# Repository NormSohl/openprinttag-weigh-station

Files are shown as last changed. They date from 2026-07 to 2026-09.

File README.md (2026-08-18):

# Filliment Scale

<p align="center">
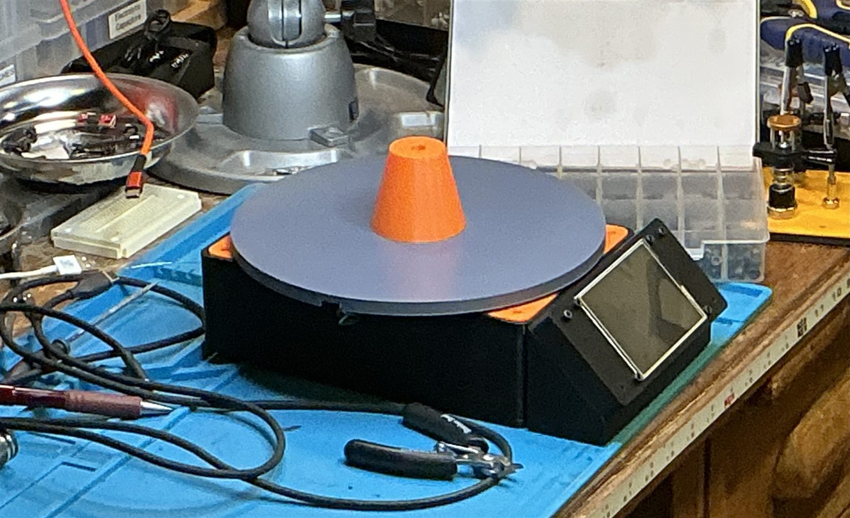
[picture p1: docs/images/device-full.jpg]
The assembled weigh station on the workbench: black enclosure, 3.5-inch display, and the round weighing platform with its orange centering spigot
  
  <br>
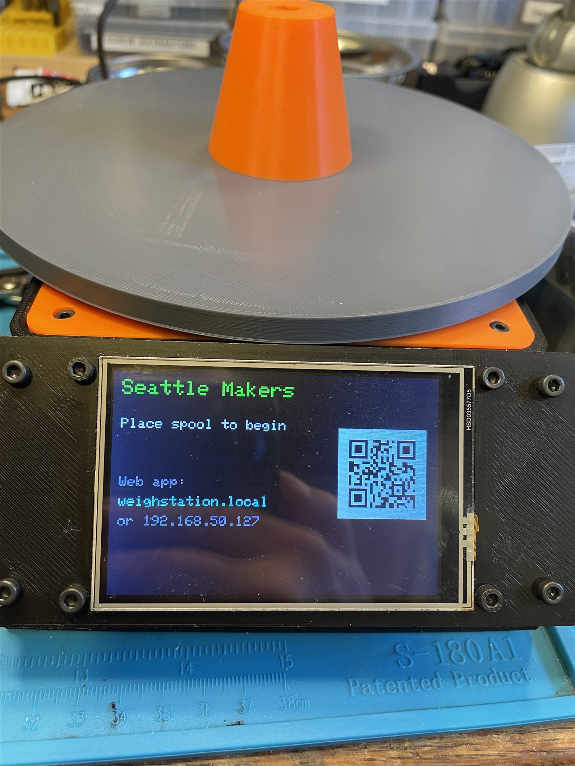
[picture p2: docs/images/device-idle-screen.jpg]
The station's idle screen: Seattle Makers, Place spool to begin, the web app address, and a QR code
  
</p>

The Seattle Makers filament weigh station: a **self-contained** NFC +
load-cell scale for the 3D-printing lab, and everything needed to build
one — the 3D-printed enclosure, wiring, and firmware.

Place a spool on the scale: it reads the [OpenPrintTag](https://specs.openprinttag.org)
(OPT) NFC tag, weighs the spool, and records the remaining filament
**locally on the device** — no external server. A built-in web app handles
inventory, onboarding new spools, reordering, backup/restore, and scale
calibration; usage history is kept as an append-only event log in
on-device flash.

OpenPrintTag is an open spool-identification standard created and
promoted by [Prusa](https://www.prusa3d.com/) — the project's namesake.
Spec: [specs.openprinttag.org](https://specs.openprinttag.org) · reference
implementation: [OpenPrintTag/openprinttag-specification](https://github.com/OpenPrintTag/openprinttag-specification)
on GitHub. This station's own tags are genuine OpenPrintTag MK1 stickers sourced
directly from Prusa (see the [BOM](hardware/bill-of-materials.md)), and it
reads any other vendor's OPT-compliant tag (Prusament, eSun, etc.) the
same way a Prusa printer would.

- **Hardware:** SparkFun Thing Plus ESP32-S3, PN5180 NFC (ISO15693), NAU7802
  load-cell ADC, 3.5" ILI9488 SPI TFT (480×320), passive piezo buzzer, onboard
  WS2812 NeoPixel.
- **Firmware:** PlatformIO + Arduino, FreeRTOS tasks (NFC / scale / display /
  sync + web app). Local storage on LittleFS + NVS.

## Get it running

Building the hardware? Start at [`docs/build-guide.md`](docs/build-guide.md).
Already have a built station and just need firmware? Download the latest
[**pre-built release**](https://github.com/NormSohl/openprinttag-weigh-station/releases/latest)
and flash it with `esptool` — no PlatformIO or source checkout required; see
the build guide's [flashing section](docs/build-guide.md#6-flashing-the-firmware)
for the exact command. Building firmware from source is documented in
[`DEVELOPMENT.md`](DEVELOPMENT.md) for anyone modifying it.

## Docs

- [`docs/build-guide.md`](docs/build-guide.md) — build one from scratch: parts, printing, wiring, flashing, first bring-up
- [`DEVELOPMENT.md`](DEVELOPMENT.md) — set up, build, and flash
- [`docs/user-manual.md`](docs/user-manual.md) — operation (members + admins)
- [`hardware/netlist.md`](hardware/netlist.md) — wiring diagram + pinout
- [`docs/design/sd-local-ecosystem.md`](docs/design/sd-local-ecosystem.md) — the
  local-storage architecture

> **History:** this project originally synced to Spoolman (and kept history in
> Prometheus). It is now standalone — Spoolman and Prometheus have been removed
> and replaced by on-device storage and the built-in web app.

## License

[GPL-3.0-or-later](LICENSE). Commercial use, including selling assembled
units or a modified firmware, is fine — but any distributed derivative
(firmware, the enclosure `.scad` files, or this repo's own docs) must stay
under the same license and come with source. Firmware, tools, and hardware
source files each carry an `SPDX-License-Identifier: GPL-3.0-or-later`
header; that's the convention to follow in any new file.

Third-party libraries pulled in via `platformio.ini` and the vendored copy
of `lib/PN5180-Library` (LGPL-2.1) keep their own upstream licenses —
check the library's own `LICENSE` before assuming GPL terms apply to it.

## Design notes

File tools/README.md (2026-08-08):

# tools/ — bench aids that need no board

Two kinds of thing here: UI previews (Python, below) and `qr/` — C harnesses
that build and run the real QR encoder natively under AddressSanitizer, to
check the capacity table `drawQr()` depends on. Unlike the previews, those
are actual tests with a pass/fail exit code. See `qr/README.md`.

## UI preview generators

Standalone Python scripts that render the device's UI **without flashing the
board**, for reviewing look/layout/wording on a PC. Pure `python3` stdlib, no
dependencies.

| Script | Renders | Source of truth |
|---|---|---|
| `preview_webapp.py` | The built-in web app (dashboard, spools, spool history + sparkline, onboard, reorder, config, calibrate, backup) | `src/web_app.cpp` |
| `preview_lcd.py` | The 3.5" ILI9488 TFT for every device state (480×320) | `src/display_task.cpp` |

```bash
python3 tools/preview_webapp.py   # -> webapp-preview.html
python3 tools/preview_lcd.py      # -> lcd-preview.html
```
Open the generated HTML in any browser.

> ⚠️ **These duplicate layout/markup from the firmware with sample data** — they
> are *not* built or tested by CI, and they will drift if the web/display code
> changes. Treat them as a convenience preview, and re-run (and tweak) them after
> editing `web_app.cpp` / `display_task.cpp`. The firmware is always authoritative.

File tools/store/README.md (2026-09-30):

# tools/store — `store.cpp`, compiled and run on the host

`./run.sh` builds and runs everything here. It needs ArduinoJson:

```
git clone --depth 1 https://github.com/bblanchon/ArduinoJson ../../.deps/ArduinoJson
./run.sh
```

## Why this exists

The PlatformIO **registry** is unreachable from the Claude Code sandbox, so
firmware changes made there get no compiler at all — only a real `pio run`
proves them. But the registry is the only thing blocked; GitHub is reachable,
and `store.cpp`'s dependencies are small enough to shim. `shim/` supplies just
enough `Arduino.h` / `LittleFS.h` / `Preferences.h` / FreeRTOS for the real
`src/store.cpp` to compile and **run**, with LittleFS over a scratch directory
and NVS over a flat file — so the counters diverge across a simulated reboot
the way the real partitions do, which is the exact condition
`reconcileIdCounter_()` exists to repair.

That buys two things the sandbox otherwise cannot have:

1. **`store.cpp` is compile-verified.** It is the largest and most-changed file
   in the project.
2. **The compaction fold is verifiable without hardware.** `run.sh` runs
   `SEED 20 200` → `DUMP usage` → `COMPACT` → `DUMP usage` and diffs the two,
   which is the one check whose regression cannot be recovered afterwards: once
   raw events are folded away, the `Usage` rows are the only evidence left. The
   figures match the 2026-08-08 hardware run exactly — 4 buckets, 4477.5 g and
   995 weighs each, 17910.0 g total.

`--products` covers what no serial command reaches: adoption converging on one
product rather than one per spool, a disagreeing tag being reported without
updating anything, an edit propagating to its spools, and products surviving a
fold. It found a real bug on its first run — `productDiffers_()` was not
comparing the tare. That comparison was **deliberately removed** on 2026-09-30:
tare now belongs to the spool, not the product (the same filament sometimes
arrives on a different spool body), so a tag whose tare differs from its
product's is that spool's tare, not a conflict. The suite now asserts both
directions — a different tare is *not* reported and does not fork a product,
and a product edit leaves each spool's own tare alone (a spool with none takes
the product's default).

`--audit` covers the physical-inventory audit state machine — phase
transitions, Found/Close semantics, and specifically the two real bugs found on
hardware 2026-08-15 that no automated test had caught until this one existed:
the four `Audit*` marker events (global, no `uuid`) silently vanishing across a
compaction fold that straddled an in-progress audit, and a retired spool never
clearing `retired` on a genuine subsequent reweigh. Both are regression-tested
here now (SEED past `STORE_LOG_KEEP_EVENTS`, `COMPACT`, assert the phase
survived; reweigh a retired spool, assert `retired` cleared).

`--cost` covers `applyInto_()`'s `delta * rate` — the conversion from grams
consumed to dollars, and the one calculation the whole cost feature exists for.
Nothing else reached it: `SEED` never sets a price, so every `dollars` figure
in the other suites is `$0.00` and a regression would have been invisible until
someone noticed the money was wrong months later. Three spools, one period:
priced up front (500 g of a $30.00/kg spool → $15.00), never priced (300 g →
$0.00, grams still counted), and priced only partway through (200 g consumed
but only the later 100 g priced → $5.00, because a price recorded later must
never backdate earlier consumption). Then it seeds past
`STORE_LOG_KEEP_EVENTS`, compacts, and re-asserts all three — Usage rows are
the only evidence left once raw events fold away.

**It seeds before compacting deliberately.** The first cut ran `COMPACT` on a
twelve-line log, where it is a no-op, so the "survives the fold" assertions
re-checked un-folded data and passed for the wrong reason. The test now
captures the line count either side of the fold and fails if nothing was
actually folded. Its detection power was confirmed by mutation: doubling the
rate in `store.cpp` fails both priced buckets, before and after compaction,
and correctly leaves the unpriced one passing.

`--popularity` covers `storeMaterialPopularity()` — the Stock List's
stockout-corrected `grams / available_days` metric — against a hand-built
timeline (in stock, consumed to empty, restocked, partially consumed again)
where every expected number is known in advance. Writing it surfaced a real,
previously undocumented gap: **popularity had no fold-survival mechanism.**
Unlike the consumption rollup (folded into permanent `Usage` rows) and unlike
Products/Audits (re-emitted from live state at compaction time),
`storeMaterialPopularity()` only ever replays raw log lines, and a compaction
`Checkpoint` carries a state snapshot, not grams or crossing history. On a
station busy enough that `STORE_LOG_KEEP_EVENTS` (2000 events) covers less
real time than the popularity window (90 days by default), a compaction could
silently fold away consumption still legitimately inside the window —
reproduced on this bench as `grams` dropping 1000 → 0 and `available_days`
shifting 15 → 5 for identical underlying history, before vs. after a forced
compaction. That was the opposite of the feature's stated purpose ("a
stockout must never make a popular material look artificially unpopular").

**Fixed** by giving `storeCompact()` a retention floor: it now refuses to
fold any log line timestamped within `STOCK_POPULARITY_WINDOW_DAYS` of now
(`config.h`), no matter how far past `STORE_LOG_KEEP_EVENTS` the log has
grown — found by a single pre-pass over the log (piggybacked on the existing
line-count pass) that locates the earliest in-window line and caps `skip` at
that index, since compaction only ever discards a *prefix* of the log.
`STORE_LOG_COMPACT_BYTES`'s byte trigger is what still bounds how long that
can go on for. `STOCK_POPULARITY_WINDOW_DAYS` moved out of `web_app.cpp` and
into `config.h` specifically so the compaction floor and the query window
share one definition and cannot drift apart. `--popularity` now asserts (not
just prints) both directions: a compaction that would touch in-window history
must be refused entirely and leave the numbers byte-for-byte unchanged, and
material genuinely outside the window must still compact normally without
disturbing an unrelated in-window material's numbers.

**This does not replace `pio run`.** Everything outside `store.cpp` — the tasks,
the web app, the display — still has no compiler here.

## The matcher slice

`storeFindProduct()` decides whether the tag on the scale is *another spool of
something we already stock* or *a new product*. Both wrong answers are silent:

- **Missed match** → a second product is created, and the inventory lists the
  same filament twice. The reorder threshold then guards half a shelf each.
- **Over-match** → two different filaments merge into one row. A 1 kg and a
  5 kg of the same product carry the identical `material_name`, so this is the
  easy mistake to make, and it defeats the decision that a different size is a
  different product.

Neither shows up as an error, on the bench or in service — which is why this is
tested off the board.

`extract_match.py` slices `ProductRecord`,
`normEq_`, `nomEq_` and `findProduct_` **verbatim** out of `src/store.h` and
`src/store.cpp` into a generated header. The test therefore exercises the
shipping bytes, and it cannot drift the way a transcribed copy would. If a
refactor moves the markers the extractor brackets on, it exits with an error
rather than testing something stale.

This also makes those functions compile-verified, which is otherwise not
available for anything in `src/`.

## Run

```
python3 extract_match.py
g++ -std=c++17 -O1 -g -fsanitize=address,undefined -o match_test match_test.cpp
LD_PRELOAD=$(gcc -print-file-name=libasan.so) ./match_test
```

`match_extract.h` and `match_test` are build products; they are not committed.

## What it asserts

Each rung of the ladder in isolation, and the cases where the rungs disagree:

| check | why it is here |
|---|---|
| `eSun` matches `ESUN`, `PLA Summer` matches `PLA  Summer` | vendors and product names are typed by hand |
| `PLA` does **not** match `PLA+` | whitespace is skipped, punctuation is not — these are different filaments |
| nominal weight 0 does not block a match | a tag carrying no weight offers nothing to distinguish on |
| 1 kg and 5 kg stay apart under rules 3 and 4 | the whole reason nominal weight is in the key |
| `package_uuid` beats `gtin` beats `material_uuid` beats names | the ladder order is the design's, not an accident |
| an unknown `package_uuid` still falls through to the name rule | a vendor UUID we have not seen must not veto a good name match |
| an empty probe matches nothing | must not silently adopt row 0 |

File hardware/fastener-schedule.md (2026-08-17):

# Fastener Schedule — opt-weigh-station

Derived directly from `weighstation.scad` and `porch-tft-faceplate.scad`.
All screws are metric ISO 4762
socket head cap screws (SHCS), stainless A2. All heat-set inserts are
Ruthex press-fit, installed from above. Washers (DIN 125-A, stainless)
go under every screw head bearing on plastic.

## Heat-Set Inserts

| Size | Location | Qty |
|---|---|-----|
| M3 (Ruthex RX-M3x5.7) | Tray mount bosses | 4 |
| M3 (Ruthex RX-M3x5.7) | Deck corner columns | 4 |
| M3 (Ruthex RX-M3x5.7) | Overload stop post | 1 |
| M3 (Ruthex RX-M3x5.7) | USB-C breakout floor bosses | 2 |
| M3 (Ruthex RX-M3x5.7) | NAU7802 standoffs | 2 |
| M3 (Ruthex RX-M3x5.7) | Porch display faceplate corner bosses | 4 |
| M4 (Ruthex RX-M4x6.0) | Platform center (underside) | 1 |
| M5 (Ruthex RX-M5x7.0) | Load cell fixed-end boss | 1 |

**Total: 19 inserts** — 17× M3, 1× M4, 1× M5

## Screws

| Size | Location | Qty |
|---|---|-----|
| M3×10 SHCS | Tray board → tray bosses | 4 |
| M3×10 SHCS | USB-C board → floor bosses | 2 |
| M3×10 SHCS | NAU7802 board → tray standoffs | 2 |
| M2.5×8 SHCS | Display board → faceplate front (+ nut) | 4 |
| M3×12 SHCS | Deck corners → column inserts | 4 |
| M3×10 SHCS | Faceplate corners → porch heat-set bosses | 4 |
| M3×50 SHCS | Overload stop adjustment screw | 1 |
| M4×25 SHCS | Spigot → platform center | 1 |
| M5×30 SHCS | Load cell fixed end → base boss | 1 |

**Total: 23 screws** — 4× M2.5×8, 12× M3×10, 4× M3×12, 1× M3×50, 1× M4×25, 1× M5×30

## Nuts

| Size | Location | Qty |
|---|---|-----|
| M2.5 nyloc (or hex) | Display board through-bolts — behind the board, faceplate's open back | 4 |

**Total: 4 nuts** — the faceplate's own corner screws thread straight into
heat-set bosses in the porch wall and need no nut; only the board-to-plate
screws do, reached through the plate's open back before final mounting.

## Washers

| Size | Qty | Notes |
|---|-----|---|
| M2.5 flat (DIN 125-A) | 4 | Under the display-board nuts (spread load on the PCB) |
| M3 flat (DIN 125-A) | 17 | One per M3 screw (incl. 4 faceplate) |
| M4 flat (DIN 125-A) | 1 | Spigot bolt |
| M5 flat (DIN 125-A) | 1 | Load cell fixed-end bolt |

## Notes

- **Overload stop screw (M3×50):** travels from below the base underside
  (~45mm) before reaching the insert mouth — a shorter screw will not
  engage the insert at all. `plat_gap` was raised 2→5 (platform/adapter
  clearance), so `lc_boss_h` grew 46.3→49.3mm and the post is ~3mm taller;
  M3×50 still engages (~5mm) but confirm on the printed part — step up to
  M3×55 if engagement is marginal.
- **Load cell screw (M5×30):** stack is platform (8mm) + load cell bar
  (12.7mm) = 20.7mm of clearance before the insert. M5×30 gives ~4–9mm of
  thread engagement depending on insert seating depth.
- **NAU7802 and USB-C breakout boards:** hole sizes have not been measured
  against the actual boards. If either board uses M2 holes instead of M3,
  swap the corresponding screw line for M2 self-tap and drop the matching
  insert (the standoff/boss is sized generously enough to work either way).
- All M3 boss/standoff fastenings (tray, deck, USB, NAU, faceplate) use the
  same Ø8 boss with a 1.7mm wall around the M3 insert — adequate in PETG.
- **Display board through-bolts (M2.5×8 + nut):** cap head sits proud on
  the faceplate's front bezel; the shaft passes through the thin front
  panel and the board's corner hole (92×50mm pattern) into an M2.5 nut
  behind, cinching the board against the panel back. Nuts + washers go on
  from the faceplate's open back before it's mounted to the porch. M2.5×8
  gives ~2–3mm past the nut; drop to M2.5×6 if the nut sits proud. No
  counterbore — the cap is intentionally proud (front service).
- **Faceplate corner screws (M3×10, no nut):** the faceplate (3mm) sits
  directly over an opening cut into the porch's own front face and picks
  up 4 heat-set-insert bosses that project sideways from the porch's real
  side wall — no wiring-passage reach-through, no nut. Head sits proud
  (no counterbore on a 3mm plate). This replaced the older adapter's
  M3×25 + nyloc-through-the-porch-cavity pattern; see
  `printed-parts-issues.md` issue 5 for why.

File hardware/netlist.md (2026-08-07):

# Wiring Netlist

Source → destination for the controller and every peripheral. Matches the
firmware pin map (`src/config.h`) and the display datasheet-of-record
(`docs/datasheets/display-hosyond-ili9488.md`).

**MCU:** SparkFun Thing Plus ESP32-S3 (DEV-21230).

> "LED" on the display is the **panel's built-in backlight** (main header
> pin 8, silk-labeled `LED`), not a separate indicator. Tie to 3.3 V for
> always-on. The panel shows nothing without it.

---

## Diagram

Wiring block diagram

Every device wires back to the controller — the PN5180 and display don't connect
to each other; each shared net runs from the controller and forks at a splice.
The onboard NeoPixel (GPIO 46) and BOOT button (GPIO 0) need no wiring.

---

## Assembly schedule

Two kinds of connection: **direct** single wires, and **shared nets** that reach
more than one device — each of those is joined once at a **soldered splice**
(pigtail star), with a single clean leg to every endpoint.

### Direct wires — one per row (MCU pin → device)

| # | From | To |
|---|---|---|
| 1 | GPIO 5  | PN5180 : NSS (CS) |
| 2 | GPIO 6  | PN5180 : BUSY *(active-high)* |
| 3 | GPIO 7  | PN5180 : RST *(active-low)* |
| 4 | GPIO 15 | TFT : CS |
| 5 | GPIO 16 | TFT : DC (RS) |
| 6 | GPIO 17 | TFT : RESET |
| 7 | GPIO 14 | Buzzer : + *(PWM; passive piezo, no resistor)* |
| 8 | **VUSB (5 V)** | **PN5180 : 5V** — RF transmitter rail, see Cautions |

### Shared nets — one soldered splice each

Each splice joins the legs below; a single wire then lands at every endpoint.
Bridge **VCC→LED** on the display module so the backlight needs no separate leg.

| Splice | MCU leg | Device legs |
|---|---|---|
| MOSI | GPIO 11 (`11/PICO`) | PN5180 MOSI · TFT SDI |
| SCK  | GPIO 12 (`12/SCK`)  | PN5180 SCK · TFT SCK |
| MISO | GPIO 13 (`13/POCI`) | PN5180 MISO **only** — *do NOT add TFT SDO, see Cautions* |
| 3V3  | 3V3 | PN5180 3.3V · TFT VCC |
| GND  | GND | PN5180 GND · TFT GND · Buzzer − |

### NAU7802 load-cell ADC — one Qwiic cable

Not jumpers — a single 4-conductor Qwiic cable from the Thing Plus Qwiic
connector to the NAU7802 board carries all four:

| Conductor | MCU | NAU7802 |
|---|---|---|
| SDA | GPIO 8 | SDA |
| SCL | GPIO 9 | SCL |
| +3.3 V | Qwiic 3V3 | 3.3V |
| GND | Qwiic GND | GND |

### Load cell → NAU7802 terminal block (4-wire full bridge)

| # | Load-cell wire | Function | NAU7802 terminal |
|---|---|---|---|
| L1 | 🟥 Red (红) | Excitation + | E+ |
| L2 | ⬛ Black (黑)  | Excitation − | E− |
| L3 | 🟩 Green (绿)  | Signal + | A+ |
| L4 | ⬜ White (白)  | Signal − | A− |
| L5 | 🟨 Yellow (黄) | Shield/drain | GND *(omit if absent)* |

**Totals:** 8 direct wires + 5 soldered splices (13 legs) + 1 Qwiic cable +
4–5 load-cell leads.

> **The display's microSD slot is not wired and is not used.** The ESP32-S3 has
> only two general-purpose SPI peripherals and both are taken (PN5180 on SPI2,
> TFT on SPI3 — see `platformio.ini`), so the card had no host of its own. The
> event log lives on internal flash and is backed up through the web app's
> **Backup** page. Leave the Thing Plus's own SD slot empty too.

---

## Shared-net junctions — soldered pigtails

Five nets reach more than one device — **MOSI, SCK, MISO, 3V3, GND**. Instead of
stacking wires on a pin, join each with **one soldered splice** and heat-shrink
it; a single clean leg then lands at each device (see the splice table above).

**Technique**

- Strip ~4 mm on each leg; gather and solder into one joint (a lineman's /
  Western-Union twist adds mechanical strength before you flow solder).
- **Thread the heat-shrink onto one leg first** and slide it well back from the
  end — once the wires are joined there's no open end to feed a tube over the
  splice. Solder, let it cool, slide the tube over the joint, then heat to shrink.
- **Stagger** the five splices along the loom so the shrink bumps don't stack,
  and anchor the bundle so nothing flexes right at a joint.
- Keep the splices **near the MCU** so the shared-bus stubs stay short.

**Rails with many legs.** The 3V3 (3 legs) and especially GND (4 legs) splices
carry the most wires; if a single solder joint gets bulky, put those two on a
small **perfboard bus** instead — a row of commoned pads, one wire per pad. Same
result, neater for many wires. The three SPI splices are just three wires each.

If you use a perfboard bus, mount it on a flat interior wall near the MCU:
foam tape (VHB) or adhesive-backed nylon PCB standoffs need no reprint; M2.5
standoff bosses can be added to the enclosure SCAD for a screw-down future
revision.

## Device-end connectors & retention

Independent of the splices, the leg that lands at each module can be:

- **Soldered directly** to the module's header pin — most reliable, permanent.
- **DuPont (0.1 in) plug** — keep it if you may want to swap a module. Each
  female terminal holds one wire and each header pin takes one terminal, which is
  exactly why the shared nets are spliced upstream rather than doubled onto a pin.
  Dab hot glue on DuPont housings so they can't back out under handling.

The NAU7802 stays on its latching Qwiic cable and the load cell in its screw
terminal — both already reliable, nothing to change.

---

## Onboard — no external wiring

| Function | MCU pin |
|---|---|
| WS2812 status pixel | GPIO 46 (onboard) |
| BOOT / WiFi-reset button | GPIO 0 (onboard) |

## Not wired (planned / out of scope)

| Device | Interface | Status |
|---|---|---|
| microSD (on display board) | would need a 3rd SPI host | **removed** — no SPI peripheral available (PN5180 has SPI2, TFT has SPI3). Backup is via the web app's Backup page instead |
| Resistive touch (T_CLK/T_CS/T_DIN/T_DO/T_IRQ) | SPI slave, same header | **out of scope** — intentionally unwired |
| PN5180 IRQ | — | unused (firmware polls BUSY) |

---

## Cautions

- **The PN5180 needs BOTH supplies.** Its *logic* is 3.3 V (never put 5 V on
  SPI/NSS/BUSY/RST), but the module has a **separate 5 V pin that powers the RF
  transmitter / antenna driver**. Leave 5 V off and SPI may still answer while
  the reader generates no usable field — i.e. it looks alive but sees no tags.
  Wire **VUSB → PN5180 5V** and **3V3 → PN5180 3.3V**.
  *(An earlier revision of this file said "3.3 V only — do not connect to 5 V".
  That was wrong: it conflated the logic level with the module's power pins.)*
- PN5180 + TFT share **MOSI and SCK only** — never MISO. They sit on *different*
  SPI peripherals (SPI2 and SPI3) and neither can be moved, so the firmware
  re-points those two pins on every handoff (`src/spi_bus.cpp`) — the S3 routes
  a pin's output from exactly one peripheral, and whoever attaches last silently
  takes it. Nothing to do at the wiring bench; noted here because it explains
  why this looks like a plain shared bus but is not one.
- **Leave the display's `SDO` pin unconnected.** The ILI9488's SDO does **not**
  tri-state when its CS is high (documented TFT_eSPI limitation), so wiring it
  to the shared MISO line makes the panel drive MISO permanently — every reply
  from any other device on the bus reads back as 0x00. Symptom: the display
  works fine while the PN5180 appears completely dead. We only write to the
  display, so nothing is lost; `TFT_MISO` is set to -1 in `platformio.ini`.
  *(An earlier revision of this file wired TFT SDO into the MISO splice. That
  was wrong and is what kept the NFC reader from ever answering.)*
- Load-cell orientation: force axis vertical, sealed/potted face **down** for
  positive output. Calibrate at 50–80 % of rated range via the web
  **Calibrate** page (or serial `ZERO` / `CAL <grams>`).

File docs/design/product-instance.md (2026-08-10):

# Design: products and instances

Status: **built** (2026-08-10) — pending bench verification.

| step | state |
|---|---|
| Stop destroying unmodelled tag fields | **done** — `OptMain.extra` passthrough |
| Read OPT identity keys 1–4 | **done** — `package_uuid` / `material_uuid` / `brand_uuid` / `gtin` |
| Product entity, index, event type, compaction survival, matching | **done** — `ProductRecord`, `StoreEv::Product`, `storeFindProduct()` / `storeAdoptProduct()` |
| Foreign-tag adoption resolves a product | **done** — `syncTask`, provisional |
| Web onboard/edit form resolves a product | **done** — not provisional |
| Products page + `/api/products` | **done** |
| Onboarding UI ("another spool of X" vs "a new product") | **done** |
| Product editing + propagation to its spools | **done** — `/product?id=N` |
| Reorder against products | **done** — exact match, name fallback |

**The design is built.** What is left is bench verification, and B2 in
`implementation-plan.md` (importing a catalog from 3dfilamentprofiles.com),
which is a separate piece of work.

**Products are created by the two onboarding paths and edited only on
`/product`.** That page is the one place an update is allowed, because it is
the only one that can honestly say what the edit will touch — it names the
spools first, then propagates on save. Neither the spool form nor a tag may
update a product; see *Authority* below. `product == 0` stays valid, so records
that predate products keep working untouched.

## The problem

Every spool record today is a complete, independent copy of its own identity:

```c
struct SpoolRecord {
    uint32_t spool;  char uuid[33];
    char     vendor[64];  material[64];  abbr[16];
    uint8_t  rgba[4];
    float    dia, empty_g, nom_g;
    float    remaining_g, used_g;
    bool     needs_ob;  char last_ts[25];
};
```

Ten spools of the same filament are ten copies of the same vendor, material
name, colour, diameter, tare and nominal weight. That costs three things:

- **Onboarding is retyped every time.** Nine of those ten forms are identical,
  and each is a fresh chance to pick the wrong spool profile — a mistake that
  silently biases every later remaining-weight, because remaining is
  `gross − tare`.
- **A correction has to be made ten times.** Discover the nozzle temperature is
  wrong and there is no single place to fix it.
- **Facts that belong to a product are stored per spool.** A measured colour is
  the clearest case: measure one spool with a spectrometer and you have
  characterised *the product*, not that spool. There is nowhere to put that.

## Guiding insight

**OpenPrintTag already models this, and we are flattening it.** Keys 0–3 are a
four-level identity:

| key | field | level | we store |
|---|---|---|---|
| 3 | `brand_uuid` | brand | ✗ (name only) |
| 2 | `material_uuid` | **the product** | ✗ |
| 1 | `package_uuid` | the SKU | ✗ — **this is our Product**, since a different size is a different product |
| 0 | `instance_uuid` | **this spool** | ✓ as `SpoolRecord.uuid` |

And the spec gives a derivation rule that makes this adoptable without vendor
cooperation:

> `material_uuid` — *"If not specified, can be deduced from `brand_uuid` +
> `material_name`."*

So a product identity can be computed from data we already hold. No new tag
field, no dependency on vendors writing UUIDs.

## Prerequisite: stop destroying fields we do not model — **DONE** (2026-08-08)

`optEncodeMain()` writes **16 of the spec's 61 Main keys**. Rewriting Main on a
compliant vendor tag therefore *destroys* up to 44 fields the vendor wrote —
GTIN, all four UUIDs, manufactured and expiry dates, density, drying temperature
and time, chamber temperatures, viscosities, certifications, RAL reference,
secondary colours. Silently, with no error, and irreversibly.

It is latent only because an adopted foreign tag's record is built *from* the
tag, so the two agree and the reconcile loop never fires. **Products make
rewrites routine** — a product edit sets `gWriteMainPending` for every spool of
it — so this stops being latent exactly when the work above lands.

Three options:

1. **Never rewrite Main on a tag we did not originate.** Safe, and gives up
   "edit the product, every tag updates itself" for precisely the spools most
   likely to carry rich data.
2. **Preserve unmodelled keys verbatim.** The decoder already walks the Main map
   key by key; record the byte span of each *unrecognised* key/value pair and
   splice those bytes back in on encode, after our own keys and before the map
   closes. No duplication is possible, because a span is only kept for a key the
   switch did not claim.
3. Model all 61 keys. Not realistic, and it would only move the problem to key
   62.

**(2), implemented.** `OptMain.extra[192]` plus `extra_len`; `optDecode()` copies
each unrecognised pair in, `optEncodeMain()` splices them back before closing the
map. 192 is above the largest Main region the layout produces (234 B) less our
own output, so overflow should be unreachable.

The overflow case is answered rather than assumed away: `extra_overflow` is set,
`optMainPreservesAll()` reports it, and `nfcTask` **refuses the rewrite**. Losing
an edit beats losing a vendor's data, and `DUMP TAG` says which happened.

`tools/opt/optfuzz` proves it — a Main map carrying `gtin`, `country_of_origin`
and `density` (uint, text and float, none of which we model) survives decode →
re-encode → decode byte for byte.

## The four entities

**Brand** → **Product** → **Profile** → **Instance**, where Profile is *not* a
child of Product but a shared table both point into.

| Entity | Holds | Why there |
|---|---|---|
| **Brand** | name | Already just a string; a table only if it grows attributes |
| **Product** | material name, abbreviation, colour (rgba + measured L\*a\*b\*), diameter, print/bed temps, GTIN, default profile | Everything true of *every* spool of this filament |
| **Profile** | tare (`empty_g`), nominal full weight | The physical reel. Shared across products, and independent of them |
| **Instance** | `instance_uuid`, spool number, remaining/used, `needs_ob` | The only things that differ spool to spool |

**Profile is separate rather than a product field** because the two vary
independently. Most of the lab is one cardboard reel, so that is one number
maintained once; but a vendor ships different reels for different lines
(eSun 1 kg is 200 g, eSun PLA+ 1 kg is 255 g), and a vendor can change reels
mid-product-life. Folding tare into Product would duplicate the shared case and
still not capture the changing one.

`CfgProfile` and `CfgStock` already exist and are most of Profile and Product
respectively — `CfgStock` has vendor, material, colour, diameter, nominal
weight, SKU, GTIN and pack quantity. This is less new construction than it
looks; it is mostly wiring what is there to spool records.

**Rename the seeded profiles while doing this.** They are named by brand today
— "eSun 1kg", "Overture 1kg" — which made sense when a profile was picked per
spool. As a shared physical-reel table they should be named by the reel:
*"Cardboard 1 kg (200 g)"*. Otherwise the table fills with brand-named entries
that all describe the same reel.

## Identity

**Products get a local auto-increment id**, like spool numbers, backed by the
same NVS counter mechanism. Not a derived string key: a product must survive
being renamed, and `brand|material_name` does not.

**Matching** — when a tag arrives, find its product by, in order:

1. **`package_uuid`** (key 1), if the vendor wrote one;
2. **`gtin`** (key 4), if present;
3. `material_uuid` (key 2) **plus nominal full weight** (key 16);
4. normalised (`brand_name`, `material_name`, nominal full weight);
5. no match → create one.

**`package_uuid` first, not `material_uuid`.** The spec distinguishes them
precisely along the line this design draws:

> key 2 `material_uuid` — *"identifier of the **material**"*, deducible from
> `brand_uuid` + `material_name`
> key 1 `package_uuid` — *"identifier of the **package (product)**"*, deducible
> from `brand_uuid` + **`gtin`**

GTIN is per-SKU: a 1 kg and a 5 kg of the same filament carry different GTINs
and the same `material_name`. Since **a different size is a different product**
here, `package_uuid` *is* our product identity and `material_uuid` is one level
too coarse — matching on it alone would merge the sizes we just decided to keep
apart. Nominal weight is the fallback that recovers the distinction when a tag
carries neither identifier.

Steps 3–4 are what make adoption converge rather than multiply: without them the
second Prusament PETG Orange creates a second product and the inventory lists it
twice.

**All four keys are now read and written** — `OptMain` carries `package_uuid`,
`material_uuid`, `brand_uuid` and `gtin`, and `tools/opt/optfuzz` asserts they
survive decode → re-encode. Note the trap that came with the passthrough above:
a decode case without a matching encode is now *worse* than not modelling the
field, because claiming the key removes it from `extra` and it is then dropped
on the next rewrite.

`tools/store/` tests the ladder natively — see that README for what each rung
is protecting against.

## Storage: spool records stay resolved snapshots

The tempting design — move the shared fields out of `SpoolRecord` and resolve
them through the product on every read — is the wrong one here. It breaks
foreign tags (a genuine Prusament has full identity inline and no local
product), and it forces a migration of every existing record.

**Instead: `SpoolRecord` keeps its fields, and gains a product reference.**

```c
uint32_t product;   // 0 = none (foreign tag, or pre-migration)
```

The existing fields become a **cache of the resolved values**. Products are the
place edits *originate*; the spool record is what everything downstream already
reads.

This falls out well:

- `recordDiffersFromMain()`, `overlayRecordOntoMain()`, `rebuildInventory_()`
  and the ~1 Hz reconcile loop need **no changes at all**.
- Editing a product emits one `Reconcile` event per spool of that product,
  updating their cached copies — which is exactly the existing mechanism that
  rewrites tags on next placement. The "fix it once, every tag updates itself"
  behaviour comes free.
- A spool with `product == 0` behaves precisely as it does today.

The cost is one event per spool per product edit, bounded by spools per product.
At lab scale that is single digits.

### New event type — built

`StoreEv::Product` is an upsert of a product definition, replayed into a
products index like spools are. Products are **definitions, not events**: they
must survive compaction the way `Usage` rows do, so `storeCompact()` carries
them into the rewritten log rather than folding them away.

It emits them from the **live** index, not from the folded region — and unlike
the spool checkpoints, that is not merely safe but required. A Product event is
not a delta: replay is last-write-wins on the whole record, so the live index
already holds the newest definition of every product. A product last defined in
the retained tail gets that same definition replayed on top (a no-op); a product
last defined in the discarded region survives only because of this. Nothing can
revert, because the tail cannot contain an *older* definition than the index
built by replaying it.

That argument is the mirror image of the one for checkpoints, where writing from
the live index **is** wrong — see *Consumption rollup* in `CLAUDE.md`. The
difference is that a checkpoint is a baseline the tail measures deltas against,
and a product definition is not.

The product-id counter is reconciled against the log at boot and on import, for
the same reason the spool counter is, and one sharper: a reissued spool number
duplicates a label, but a reissued *product* number makes two definitions
overwrite each other on replay, and every spool pointing at that number follows
whichever won.

### What must not change

**The consumption rollup must keep snapshotting strings at weigh time.** It
currently records vendor and abbreviation as text in `UsageRow`, deliberately
capturing what was true when the filament was consumed. If it referenced a
product instead, renaming a product would silently rewrite history. This is
already correct — the requirement is not to "improve" it.

## The two onboarding paths

This is the user-visible payoff, and it is what the whole change is for.

**Another spool of X.** Pick the product; everything else is inherited. Tare
and nominal come from the product's profile. One control, no retyping, no
opportunity to pick the wrong profile.

**A new product.** The current full form, plus a profile picker that mostly
selects an existing reel. Defining a new profile is rare — a genuinely new reel.

The blank-tag flow reaches the same place: format the tag, create the instance,
then the Onboard page asks *which product*, offering "new product" as the
second option rather than the only one.

## Foreign tags create products

A foreign tag is not a special case in this model — it is the new-product path
with the form pre-filled from the tag. Decode Main, find-or-create the product
by the matching rules above, create the instance, converge.

The second spool of that product then finds the existing product and inherits
it, which is the behaviour that makes an inventory of genuine Prusament roll up
correctly instead of listing four identical rows.

### Authority: create on first sight, never auto-update

**This is the rule that needs to hold.** Product edits propagate to tags. So if
a foreign tag could also *update* a product, reading one tag would rewrite the
tags of every other spool sharing it — one odd or damaged tag could walk a whole
shelf.

A later tag that disagrees with an existing product therefore:

- keeps the product as it is,
- records the discrepancy,
- writes nothing.

Surface it in the web app for a human to adjudicate. This makes the dangerous
direction impossible rather than merely unlikely.

`write_protection` (key 13) is already honoured — `optMainWritable()` gates the
Main write-back — so a protected vendor tag will not be rewritten even when a
product edit says it should be. Aux still records, per spec. `/product` says so
before you save, rather than letting a skipped tag look like a failed edit.

**Built as:** `/product?id=N`. It names the spools the edit will touch before
you press save, then `storeUpsertProduct()` + `storePropagateProduct()` — one
`Reconcile` per spool, which updates their cached copies and leaves the existing
reconcile loop to rewrite their tags on next placement. Saving also clears
`provisional`, which is precisely what that flag was waiting for: a human
looked at the values.

## Migration

No data loss and no flag day:

- Existing records keep working untouched (`product == 0`).
- Products can be derived on demand by grouping existing records on
  (vendor, abbreviation, colour), or created lazily the next time a spool of
  that filament is onboarded.
- The store is currently empty after `WIPE ALL`, so in practice this is moot on
  the bench unit — but the property matters for a deployed device.

## Reorder gets simpler

`rollUp()` matches stock items against spools by comparing **strings** —
`strcmp(r.abbr, s.material)` after today's fix, which was itself a repair for
`material` changing meaning. With products, a stock item references a product id
and matching is an exact lookup. The "keep N spools of X" threshold becomes a
product-level property, which is what it always was.

## Decisions (2026-08-08)

**1. No package/SKU level.** A different size is a different product. Three
levels: Brand → Product → Profile → Instance.

> **Consequence for identity.** If size distinguishes products, the match key
> cannot be (`brand_name`, `material_name`) alone — a 1 kg and a 5 kg of the
> same filament often carry the identical `material_name` and would merge. The
> spec already draws this line: `package_uuid` (key 1) identifies the *package*
> and is deducible from `brand_uuid` + GTIN, which is per-SKU. So
> `package_uuid` is our product identity; nominal full weight is the fallback
> when a tag carries no identifier. See *Identity* above.

**2. No per-instance tare override.** Tare lives on the Profile, reached through
the Product. An Instance is just `instance_uuid`, spool number, remaining/used
and `needs_ob`.

> **Consequence for "Capture tare".** With no instance-level place to put it,
> the button stops meaning "this spool weighs X empty" and becomes "measure this
> reel" — i.e. it creates or corrects a **Profile**. That is arguably what it
> always should have been, and it is the honest workflow: you weigh one empty
> reel and every product on that reel benefits.

**3. Tag-derived products are marked provisional.** A product created by
adopting a foreign tag is flagged until a human confirms it. Provisional
products are excluded from tag write-back, so adopting a spool can never cause
the station to rewrite a vendor's tag from data it inferred.

**4. `primary_color_lab` (key 59) — add the fields, leave them blank.** The
struct, decode and encode go in now; nothing populates them until someone
measures. Absent on the tag means unmeasured, and `optEncodeMain()` omits the
key entirely rather than writing zeroes — a measured black is `L*=0`, so zero
is a legal value and cannot double as "unknown". A separate `has_lab` flag
carries that instead, because zero-initialised structs must read as unmeasured.

Two things to settle before the *first* measurement, since neither is
recoverable afterwards and neither would surface as an error:

- **Illuminant must be D65 / 2°**, which the spec requires. Nix apps offer a
  choice and several default to D50 — valid numbers, wrong field.
- **Pick one surface.** Wound filament and a printed swatch of the same material
  are different colours (finish, layer lines, translucency). Either is
  defensible; mixing them makes the values meaningless.

## Sequencing

Store first (product entity, index, event type, compaction), then onboarding,
then reorder, then the web pages. Each step is independently shippable because
`product == 0` remains valid throughout.

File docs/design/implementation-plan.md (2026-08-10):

# Implementation Plan — Local-Storage Ecosystem

Moving `docs/design/sd-local-ecosystem.md` from design to code. This is the
sequencing/scoping plan: phases, dependencies, testable milestones, and the
decisions to lock before/while building.

Status: **complete** — see the Status section below for what closed differently
from how it was written here. Kept as the record of what was planned and why.

## Approach

Build the storage layer **in parallel** with the existing (Spoolman)
firmware, cut the tag/weigh flow over to it, then grow the web app on top.
Each phase ends at a **testable milestone** so we never have a long
untestable stretch. The OPT codec, NFC flow, and load-cell code are reused
almost unchanged — the churn is concentrated in `sync_task.cpp`.

### What can proceed now, without the load cell
The strain gauge is still en route, but NFC, TFT, and SD are in hand.
Storage, config, and the whole web app can be built and tested with
**simulated weigh events** (serial-injected). Only final end-to-end
calibration/validation needs the load cell. So Phases 1–6 are not blocked
by hardware; Phase 0's SD bring-up is the only hardware gate.

## Refactor shape

`sync_task.cpp` (679 lines: Spoolman client + web server + reconciliation)
splits into:

| New module | From | Role |
|---|---|---|
| `store.*` | new | LittleFS log + indices, NVS counters, SD backup/restore |
| `web_app.*` | expanded web server | dashboard, onboarding, config, reorder, backup |
| `net.*` | WiFiManager/AP bits | SoftAP + station, mDNS |
| ~~Spoolman client~~ | deleted | — |

`opt_tag.*`, `scale_task.cpp` unchanged; `nfc_task.cpp` repointed from
Spoolman calls to `store`; `display_task.cpp` minor (idle address, local
spool ID).

## Status (2026-08-10): **all seven phases are done and validated on hardware**

Every phase below is built, and every mechanism has run on the board — see
*Bring-up status* in `CLAUDE.md` for what each one proved. Three things closed
differently from how they were written, and are recorded as such rather than
quietly ticked off:

- **Phase 0's SD gate was closed by REMOVAL, not by completion.** The S3 has two
  general-purpose SPI peripherals and both are taken (PN5180 on SPI2, TFT on
  SPI3), so the card never had a host. Storage is internal flash only.
- **Phase 6's SD half went with it.** The host export/import path is built and
  verified; what actually bounds storage growth is `storeCompact()`, which was
  not in the original plan.
- **The `mailto:` link on `/reorder` is not built.** CSV download is. Nothing
  else in the plan is outstanding.

Backlog **B1** (per-spool weigh history, CSV, sparkline) was built as part of
Phase 4's spool detail page — it is no longer backlog. **B2** (3dfilamentprofiles
import) is still open.

Work continuing *on top of* this redesign — the product/instance data model —
is a separate design: `product-instance.md`. It is not part of these phases.

**Caveat on "done":** commits since `dafb4d5` are source-complete but have not
been flashed. The PlatformIO registry is unreachable from the Claude Code
sandbox, so only a real `pio run` compiles them. See *Due on the bench* in
`CLAUDE.md`.

## Phases

### Phase 0 — Scaffolding & hardware gate
- ✅ **Partition table** (`partitions.csv`, wired via
  `board_build.partitions`): 4 MB = single 1.875 MB `factory` app + 2 MB
  LittleFS (`spiffs` label) + nvs/coredump. Layout validated (contiguous,
  ends at 0x400000). *Verified 4 MB / 2 MB quad PSRAM with `esptool flash_id`.*
- ✅ Build-time decisions locked (see Decisions section).
- ~~**Wire + bring up the SD** on the ESP32-S3's second SPI host.~~ **REMOVED** —
  there is no third SPI peripheral for it. See the Status note above.
- **Milestone:** board mounts LittleFS (custom partition). *(The SD half of
  this milestone is void — see above.)*

### Phase 1 — `store` core (headless)
- NVS monotonic spool-ID counter.
- Append-only NDJSON event log on LittleFS + per-line CRC.
- Derived indices (`spools`, `inventory`) built by log replay; lazy rebuild
  on boot if missing/corrupt.
- Read/query API for display + web.
- Exercised via serial commands (inject events, dump indices).
- **Milestone:** inject N weigh/onboard events → correct indices survive a
  power cycle and a torn-tail-line recovery.

### Phase 2 — Cut the tag/weigh flow over to `store`
- Replace the Spoolman client calls in the tag→record path (onboard stub,
  weigh write-back, reconciliation) with `store` operations.
- Delete the Spoolman HTTP client; drop `SPOOLMAN_BASE_URL`.
- Display reads current spool from `store`.
- **Milestone:** place a tag → weigh → record persists locally; remove →
  re-place reconciles. No network needed. (Onboarding data entry still a
  stub here; the form lands in Phase 4.)

### Phase 3 — Config catalog
- `vendors / materials / spool-profiles / colors / stock-items` JSON on
  LittleFS; load/save API; seed sensible defaults.
- **Milestone:** catalog loads at boot; a hand-edited file round-trips.

### Phase 4 — Web app: inventory + onboarding
- Expand the web server; **SoftAP + station**, mDNS; serve `/web/` assets
  from LittleFS with a firmware-embedded recovery page.
- **Inventory:** `GET /`, `/spools`, `/spool/<id>` (read from `store`).
- **Onboarding:** `GET /onboard` (pick vendor/material/profile/color),
  `POST /tare`, `POST /onboard` (write tag Main + append event).
- **Milestone:** from a browser, view inventory and complete a real
  onboarding end-to-end — **this closes 2 of the 3 user-facing gaps**.

### Phase 5 — Ordering
- `GET /config` CRUD for the catalog tables.
- `GET /reorder`: on-hand roll-up per stock item → empty/below-threshold
  list → CSV download + `mailto:`.
- **Milestone:** a low stock item appears on `/reorder`; CSV downloads.
  **Third gap closed.**

### Phase 6 — Backup & restore  *(host path implemented and verified; SD path removed)*
- SD snapshot: stage → CRC-verify → promote by rename → dated history,
  with card-full oldest-first reclaim. — **REMOVED.** The S3 has no third SPI
  peripheral (PN5180 has SPI2, TFT has SPI3), so the card never had a host.
  Superseded by web-app export/import plus in-place log compaction
  (`storeCompact()`), which is what actually bounds storage growth.
- `GET /export` (host download), `POST /import`, `POST /restore` (SD), plus
  idle auto-snapshot and web controls on `/backup`.
- **Milestone:** wipe LittleFS, restore from a host-uploaded bundle. *(Verified.
  The SD half is void.)*

### Phase 7 — Display & polish
- Idle screen shows the web-UI address (+ optional QR); local spool ID;
  drop "offline" wording.
- End-to-end validation once the load cell is mounted/calibrated.
- **Milestone:** cold-boot to onboarding to reorder with no external
  services; address discoverable on-screen.

## Critical path

Phase 0 → 1 → 2 unlock the local core; **Phase 4 is the payoff** (inventory
+ onboarding UI). 3 gates 4/5; 6 and 7 can trail. Ordering (5) and backup
(6) are independent once 3/4 land.

```
0 ── 1 ── 2 ──┐
     └── 3 ───┴── 4 ── 5
                   └─── 6
                   └─── 7
```

## Decisions (LOCKED)

1. **Web stack: `ESPAsyncWebServer`.** Non-blocking; won't stall the
   NFC/scale/display tasks and serves assets + concurrent clients well.
   → add the lib dependency in `platformio.ini` at Phase 0/4; the current
   synchronous `WebServer` config page is replaced.
2. **Single app slot (no OTA) + 2 MB LittleFS.** The panel USB-C is
   full-function, so firmware flashes over USB — OTA's second 2 MB app
   slot isn't worth its cost. One 1.875 MB `factory` app (headroom) + 2 MB
   LittleFS (~800 spools w/ history). Simpler; no OTA path to build.
   *(Revised from the earlier dual-OTA choice once the panel port was
   confirmed full-function. Note: changing the partition scheme later needs
   a USB reflash to repartition.)*
3. **Network: station + AP fallback.** Join lab WiFi if configured
   (`weighstation.local`); otherwise bring up the `WeighStation` SoftAP.
   `net.*` owns this.
4. **Cutover onboarding: local stub + `needs_onboarding` flag.** New/blank
   tags register a stub locally during Phases 2–3; a person completes the
   details in the Phase 4 web form. No interim data-entry UI.

These resolve the corresponding open questions in `sd-local-ecosystem.md`
(web stack, partition scheme, AP mode).

## Out of scope (per design doc)
Spoolman, resistive touch, physical keyboard, SMTP, vendor/API ordering,
FRAM. See `sd-local-ecosystem.md`.

## Backlog — post-bringup

Ordered by likely value. B1 is done; B2 is what is left.

### ~~B1~~ — Per-spool usage history / analytics view — **BUILT**
The append-only event log **already records** the raw data: every weigh
session appends one `weigh` line (`ts`, `gross_g`, `remaining_g`, `used_g`)
and it is never overwritten, so the time series accrues automatically from
first flash. Nothing on the tag is involved — the tag carries only current
used/remaining; history lives in the log. Missing piece is the **read side**:
- ✅ `GET /spool?id=<n>` — the weigh series for one spool.
- ✅ CSV export of the series (`/spool?id=<n>&format=csv`).
- ✅ Remaining-over-time sparkline, on the spool detail page.
Build cost is a store query that streams the log filtering by spool/uuid,
plus a web view. Because the data is already captured, deferring this loses
no history.

### B2 — Import onboarding catalog from 3dfilamentprofiles.com
Populate the config tables (vendors/materials/colors/spool-profiles/stock-
items) from a user's exported filament list, so onboarding is pick-from-your-
usual-order. **Offline-first:** the user exports on their laptop (their
account) and uploads the file to the device via a new `/import-3dfp`
endpoint — no internet or credentials on the ESP32. Verified field mapping
(from the real dataset schema):

| 3dfilamentprofiles field | → config field | note |
|---|---|---|
| `brand_name` | vendors / stock `vendor` | |
| `material` | materials / stock `material` | |
| `color` + `rgb` | colors (name + rgba) | `#RRGGBB` → RGBA |
| `default_properties.temp_min/max` | material print temps | fallback from `properties` |
| `default_properties.bed_temp_min/max` | material bed temps | |
| **`spool_weight` (~253 g)** | **profile `empty_g` (tare)** | it's the *empty* spool weight → feeds the scale's remaining calc |
| `ASIN` | stock reorder reference | Amazon link for the reorder CSV |

Gaps + defaults: no diameter (default 1.75); `spool_weight` is empty, so
nominal-full defaults to 1000 g (adjustable); no GTIN (ASIN used instead).
Needs a real `/my/spools` export sample to lock the parser to the export
schema (which may be flatter than the public API dump).

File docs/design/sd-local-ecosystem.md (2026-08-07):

# Redesign: Local-Storage Ecosystem (Spoolman-free)

Status: **implemented**, with one part superseded.

> **The SD card was removed.** Every SD section below is kept as a record of
> the original design, not as a description of the build. The ESP32-S3 has two
> general-purpose SPI peripherals and both are taken — PN5180 on SPI2, TFT on
> SPI3, which TFT_eSPI's S3 port hard-wires — so the card never had a host it
> could use. It also cost more than it bought: a failed `SD.begin()` boot-looped
> the device once, and an unattended backup nobody audits mainly manufactures
> false confidence.
>
> What replaced it: the web app's **Backup** page (`/export`, `/import`) for
> off-device copies, and in-place **log compaction** (`storeCompact()`) to bound
> growth — which is what actually threatened storage, and which an SD mirror of
> the same file would not have fixed. See the *Storage* section of `CLAUDE.md`.

## Goal

Replace the external Spoolman backend with a fully self-contained
ecosystem: the weigh station stores everything locally and serves its own
web UI for onboarding, history, and reordering. No separate server to
host, back up, or keep running. Primary data lives on the ESP32-S3's
internal flash; the SD card is demoted to backup, cold archive, and
web-asset hosting — so the device works even with no card inserted.

## Guiding insight

**The OPT tag is already the authoritative record.** Its Main section
holds spool identity (brand, material, color, weights); its Aux section
holds used/remaining weight. So local storage does **not** need to be a
database — it only needs to be a logbook plus a few rebuildable indices.
Even a total storage loss only costs *history*; current inventory can be
reconstructed by re-scanning the physical spools.

## Storage architecture — three tiers

The SD card's weakness (FAT corruption on brownout, removable-media
flakiness, cheap-card wear) makes it a poor *primary* store. The board
already carries better storage. Split by reliability need:

| Tier | Medium | Holds | Why |
|---|---|---|---|
| **Counters** | **NVS** (internal flash) | spool-ID counter, log write/rotation pointers, scale cal, WiFi, hostname/SoftAP | transactional, power-fail safe; the values whose corruption hurts most |
| **Primary** | **LittleFS** (internal flash) | event log + derived indices + **all config tables** + **web UI assets** | copy-on-write, wear-leveled, brownout-resilient; no removable media |
| **Backup** | **microSD** (removable) | mirror of everything above, rotated cold archive, export/import transport | pure backup — **nothing lives only on SD**; card absent or corrupt loses backup, never function |

**Nothing the device needs to run lives only on SD** — the card can be
absent and the station still onboards, weighs, and serves its web UI. The
source of truth is the **event log on LittleFS**; indices and config are
edited in primary storage and **mirrored to SD as backup** (SD is read
only during restore, never in normal operation). Old log segments still
rotate out to the SD archive when the flash partition fills.

A **minimal recovery page is embedded in firmware** so a blank board with
no card can still boot, show the address, and accept a restore.

```
# LittleFS (internal flash) — PRIMARY (source of truth)
/log/events.ndjson          # append-only, one JSON object per line
/index/spools.json          # current state per spool (derived)
/index/inventory.json       # remaining grams per material (derived)
/index/reorder.json         # stock items empty/below threshold (derived)
/config/vendors.json        # brand list
/config/materials.json      # material presets (temps, diameter, class/type…)
/config/spool-profiles.json # spool size → nominal-full + empty tare
/config/colors.json         # color palette (name → RGBA)
/config/stock-items.json    # standard-stock catalog: SKUs to keep + thresholds
/web/                       # static UI assets (served from primary)

# NVS namespace "store" — counters + device settings
counter                     # uint32, next spool ID (atomic)
rotate                      # log rotation bookkeeping
# (+ scale cal, WiFi, hostname/SoftAP as today)

# microSD — BACKUP ONLY (verified snapshots + transport; never SD-only)
/backup/events.ndjson       # current good backup (promoted by rename)
/backup/events.staging      # in-progress write; promoted only after verify
/backup/history/            # dated point-in-time snapshots (retained)
/backup/config/             # config backup (same discipline)
/backup/manifest.json       # current generation + CRCs for restore/recovery
```

### Capacity

The board is **4 MB flash / 2 MB quad PSRAM** (ESP32-S3-MINI-1-N4R2) —
**verified on hardware** with `esptool flash_id` ("Embedded Flash 4MB (XMC),
Embedded PSRAM 2MB (AP_3v3)"). An earlier 8 MB assumption was wrong and put
the partition table past the end of flash, which boot-looped the board. No
OTA (firmware flashes over the full-function panel USB), so a single
1.875 MB app leaves a **2 MB LittleFS** partition. Current-state record ≈
250 B/spool; history event ≈ 120 B; ~20 events per spool lifetime ≈
2.5 KB/spool with full history.

| Counting… | Per unit | Fits in 2 MB LittleFS |
|---|---|---|
| Registered spools, current state only | ~250 B | **~8,000** |
| Spools with full lifetime history | ~2.5 KB | **~800** |
| Raw history events | ~120 B | **~17,000** |
| Spool-ID counter (NVS `uint32`) | 4 B | **4.29 billion** (never the limit) |

Still far beyond a makerspace's working set (hundreds of spools at most), and
SD archiving lifts the ceiling further.

Indices live in RAM/PSRAM (2 MB) — ~250 B/spool → thousands of records fit
easily. With SD archiving the working set stays on flash and older history
rolls to the card (GBs) — pushing the practical ceiling to hundreds of
thousands of spools, bounded by the card, not the device. Headroom lever:
a slimmer log line
(`used_g` is derivable from `gross − tare`).

### Event log line schema (NDJSON)

One object per line, newline-terminated, flushed after every write.

```json
{"ts":"2026-07-05T18:03:11Z","ev":"weigh","uuid":"<opt-instance-uuid>",
 "spool":42,"gross_g":812.4,"remaining_g":612.4,"used_g":187.6,"crc":"a1b2"}
```

- `ev` ∈ `onboard | weigh | reconcile | reorder_flag | export`.
- `uuid` ties the event to the tag's `instance_uuid` (same key Spoolman
  used as `nfc_id`).
- `spool` is a local auto-incrementing ID (replaces Spoolman's native ID
  shown on the display).
- `crc` is a checksum of the rest of the line so a torn tail line from a
  mid-write brownout can be detected and skipped on recovery.

### Derived indices

Rebuilt by replaying the log (on demand, or lazily on boot if missing).
Never the source of truth — safe to delete and regenerate.

## Onboarding & UI — built-in web app

Replaces Spoolman's web UI. Same workflow shape as today: device detects
a blank/foreign tag and creates a stub; a human fills in the real
material data in a browser; the device writes the tag and logs it.

- **Access:** device runs a **SoftAP** ("WeighStation"). Connect a
  laptop/phone directly to it and browse to the device — no LAN or
  infrastructure required. (Builds on the existing captive-portal AP
  code.) Falls back to station mode + `weighstation.local` if a network
  is configured.
- **Discoverability:** the **idle/at-rest screen shows the address**
  (SoftAP SSID or `weighstation.local` + IP) so anyone can find the web
  UI without poking the device — this is why the display is deliberately
  not touch-driven. A QR code to the URL is a cheap add on 480×320 and
  lets a phone jump straight in. (Today's Idle screen shows only
  "Place spool to begin" — extend it.)
- **Assets from primary storage:** serve `/web/` static files off
  LittleFS, so the UI loads with no card present; updating it is editing
  files (web upload), no reflash. Backed up to SD like everything else.
- **Routes (sketch):**
  - `GET /` — dashboard: recent activity, low-stock warnings.
  - `GET /onboard` — onboarding form (pick vendor/material/spool/color).
  - `POST /tare` — read the load cell once; return the current weight to
    prefill `empty_container_weight` (reference-spool capture).
  - `POST /onboard` — write Main section to tag, append `onboard` event.
  - `GET /spools` — spool list from `spools.json`.
  - `GET /spool/<id>` — per-spool history (filtered log view).
  - `GET /config` — manage the config tables (vendors, materials, spool
    profiles, colors, stock items); writes to primary + mirrors SD.
  - `GET /reorder` — stock items empty/below threshold; CSV download +
    `mailto:`.
  - `GET /export` — download a full backup bundle (log + config + manifest).
  - `POST /restore` — restore from an SD backup (confirm-guarded).
  - `POST /import` — restore from a host-uploaded backup bundle (confirm-
    guarded); the no-card route.

### Config catalog — onboard by picking, not typing

Most OPT Main fields are *reusable* across spools, not per-spool. Holding
them as web-editable config tables (in primary storage) turns onboarding
into **pick vendor → pick material → pick spool profile → pick color**,
filling nearly all of Main automatically. Only `actual_netto_full_weight`
is measured per-spool.

| Table | Fills OPT Main field(s) |
|---|---|
| `vendors.json` | brand_name (k11) |
| `materials.json` | material_name (k10), abbreviation (k52), class (k8), type (k9), diameter (k30), min/max print temp (k34/35), min/max bed temp (k37/38) |
| `spool-profiles.json` | nominal_netto_full_weight (k16) + empty_container_weight (k18) |
| `colors.json` | primary_color_rgba (k19) |

```json
// /config/spool-profiles.json  (size → nominal-full + empty tare)
[
  {"label":"Prusament 1kg PETG", "nominal_full_g":1000, "empty_g":201.0},
  {"label":"Generic 1kg cardboard","nominal_full_g":1000,"empty_g":130.0},
  {"label":"Generic 0.75kg plastic","nominal_full_g":750, "empty_g":175.0}
]
```

All tables are user-editable via `GET /config` in the web UI (writes to
primary, mirrors to SD). New free-text values entered during onboarding
offer to save back to the relevant table for reuse.

### Empty-spool tare (`empty_container_weight`)

The tare feeds the firmware's remaining-filament calc (gross − tare). A
new full spool can't be weighed empty, so onboarding gets it two ways
(both in the web form — no touchscreen):

1. **Reference-spool capture.** Keep spare *empty* spools on hand; place a
   matching empty and hit **"Capture tare"** (`POST /tare` reads the load
   cell once). Offers to save the value to the spool profile.
2. **Profile lookup.** Picking a spool profile pre-fills the tare, so no
   reference spool is needed when the type is known.

## Backup & restore

SD is pure backup, and backup is only useful with a restore path.

### Write discipline — never overwrite a good backup in place

Each backup is a **fresh, verified file promoted by rename**; the previous
good copy is retained as dated history. So an intact backup exists at
every instant, even if power is lost mid-write. Crash-safe sequence:

1. **Stage.** Write the snapshot to `backup/events.staging`; flush + close
   (commit FAT metadata). The live `backup/events.ndjson` is untouched.
2. **Verify.** Recompute a CRC32 over the staged file and compare to the
   hash taken from the primary source during the write (plus re-check
   per-line CRCs + record count). On mismatch: delete staging and abort —
   the current backup still stands.
3. **Archive the old.** Rename the current good backup
   `events.ndjson → history/events-<UTC-timestamp>.ndjson`.
4. **Promote.** Rename `events.staging → events.ndjson`.
5. **Record + prune.** Update `manifest.json` (current generation,
   timestamp, CRC, record count) and prune history per retention policy.

`manifest.json` names the current-good file + its CRC, which closes the
brief window between steps 3–4 where `events.ndjson` is momentarily
absent: on boot, if `events.ndjson` is missing or fails its manifest CRC,
recovery falls back to the newest `history/` file whose CRC matches its
manifest entry. Rename is a tiny directory-entry op (not a long data
write), so its corruption window is negligible vs. an in-place rewrite.

The same scheme covers `/backup/config/`. Dated history gives **free
point-in-time rollback** — you can restore any snapshot, not just the
latest. **Retention:** keep the last N snapshots (or GFS-style
dailies/weeklies) and prune older; SD has GBs, so the cap just prevents
unbounded growth. Snapshot cadence is tunable (after onboarding events,
on card insert, or periodic — see open questions).

**Space reclaim (card full):** before staging a new snapshot, if the card
lacks room, **delete the oldest `history/` snapshot first** and retry;
repeat oldest-first until it fits. Guardrails:

- Only dated `history/` files are evictable — **never** the current
  `events.ndjson`, `events.staging`, `manifest.json`, or `/backup/config/`.
- Evict down to (but not past) a floor of the most-recent few snapshots
  unless space truly demands going lower.
- If even evicting all prunable history won't fit the new snapshot, **skip
  the backup gracefully** — surface a "backup card full" warning on the
  dashboard/idle screen; primary data on flash is untouched, so nothing
  live is lost, only backup freshness.

Accepted tradeoff: on a chronically full card the oldest point-in-time
history eventually ages out — expected for finite storage, and current
inventory is always recoverable from the tags + primary flash regardless.

### Off-device backup — download to the host machine

A third, independent copy: the web client can **download a full backup to
the browser's machine** (`GET /export`). It's the strongest copy —
off-device, air-gapped from whatever fails the board or the card, and
needs no SD and no mail credentials.

- **Same bundle as an SD snapshot** — a single file (zip) containing
  `events.ndjson`, `config/*`, and `manifest.json` (version + CRCs). A
  host-saved file is byte-identical to an SD snapshot and restores through
  the exact same verified path.
- **Round-trip via upload** — `POST /import` accepts an uploaded bundle,
  verifies it against its manifest CRCs, and restores (confirm-guarded).
  Works even with no SD present.
- **Config cloning without moving the card** — download a bundle here,
  upload it on a second station; it inherits vendors/materials/profiles/
  colors/stock-items.
- Purely manual (a "Download backup" button on the dashboard); an
  optional periodic reminder can nudge, but no credentials are stored.

Net: three independent copies — **primary (flash), SD (auto snapshots),
host (manual, air-gapped)**.

### Restore paths

- **Auto-bootstrap:** on boot, if primary is empty (fresh/erased board)
  and an SD backup exists, offer to restore from it.
- **Manual restore (`POST /restore`):** replay the backup log to rebuild
  the primary log, regenerate indices, and import config. **Confirm-
  guarded** so it can't silently overwrite good primary data.
- **Upload restore (`POST /import`):** restore from a host-uploaded
  bundle (see above) — the no-card recovery route.
- **No-card / blank-flash floor:** the firmware-embedded recovery page
  still loads, shows the address, and accepts a restore/upload or fresh
  setup.

## Ordering workflow

Spoolman never did ordering, so this is net-new either way. Manually
triggered from the web UI, review-then-send.

### "Standard inventory" = the stock catalog

There is **no standard-inventory flag on the tag or per spool** — nor
should there be. "We keep this in stock" is a property of a *product
line/SKU*, not of an individual spool (a line you're **out of** has zero
spools to carry a flag). So it lives in a config table; **presence in the
table means it's standard stock.**

```json
// /config/stock-items.json
[
  {"vendor":"Prusament","material":"PETG","color":"Prusa Orange",
   "diameter":1.75,"spool_g":1000,
   "min_spools":2,                 // threshold; or "min_grams"
   "sku":"PRM-PETG-ORG-1000","gtin":"859...","pack_qty":1}
]
```

Spools that aren't in the catalog (a one-off someone brought in) never
generate reorder noise.

### Flow

1. **Roll-up** on-hand per stock item from the inventory index — match
   active spools by identity (vendor + material + color [+ diameter]) and
   sum remaining grams / count spools.
2. **Flag** each item that is **empty** or **below its threshold**
   (`min_spools`/`min_grams`; global default if unset).
3. **Review** the shortfall list on `GET /reorder`.
4. **Send** the reviewed list as a CSV.

### Sending the list

`/reorder` offers a **CSV download** to the web client's machine, plus a
prefilled `mailto:` link to the order address. The human sends/places the
order from the CSV — no mail credentials or SMTP on the device.

Vendor/API order integration is explicitly out of scope for now.

## Firmware impact

Reuse is high — the tag format, weighing, and NFC flow are unchanged.

| Module | Change |
|---|---|
| `opt_tag.*` | unchanged |
| `nfc_task.cpp` | unchanged (still reads/writes tags) |
| `scale_task.cpp` | unchanged |
| `display_task.cpp` | minor: show local spool ID; "offline" wording gone |
| `sync_task.cpp` (679 lines) | **removed** — Spoolman HTTP client deleted |
| `store.*` | **new** — storage layer: LittleFS log/indices/config (primary) + CRC, NVS counters, SD mirror/rotate/archive, backup/restore |
| `web_app.*` | **new/expanded** — full app (dashboard, onboarding, config CRUD, reorder/CSV, backup export/import); `/web/` assets served off LittleFS |
| recovery page | **new** — minimal UI embedded in firmware for the no-card / blank-flash bootstrap + restore floor |
| `config.h` | drop `SPOOLMAN_BASE_URL`; add 4 SD pins (own SPI host), LittleFS partition + paths |
| partition table | **new** — single 1.875 MB app + 2 MB LittleFS (no OTA; see Capacity) |

## SD interface — RESOLVED

The display is a Hosyond 3.5" ILI9488 (`3.5'' TFT SPI 480X320 V1.0`). Its
microSD lines (`SD_CS`/`SD_MOSI`/`SD_MISO`/`SD_SCK`) are on a **separate
header** and are **not** bonded on-PCB to the display SPI bus — so the SD
topology is a free wiring choice, not a constraint. See
[`docs/datasheets/display-hosyond-ili9488.md`](../datasheets/display-hosyond-ili9488.md).

**Decision: give the SD its own SPI bus.** Wire the four SD pins to the
ESP32-S3's second SPI host (FSPI/HSPI), separate from the shared
PN5180 + TFT bus. This keeps SD I/O independent of NFC polling and display
refresh — no `gSpiMutex` traffic for storage at all. Costs 4 GPIOs, which the
S3 has spare. **Assigned:** `SD_SCK/MOSI/MISO/CS = GPIO 10/18/21/42`
(`src/config.h`, wired per `hardware/netlist.md`).

**Onboard slot considered.** The Thing Plus ESP32-S3 also carries its own
microSD slot on the SDIO-4 pins (which SparkFun notes is faster than SPI). We
use the **display's** SD instead for front-panel card access, and leave the
onboard slot empty (its SDIO traces then stay inert). If enclosure access ever
makes the onboard slot preferable, switching to `SD_MMC` there would drop these
4 wires — revisit if desired.

## Risks & mitigations

1. ~~**SD corruption on power loss**~~ — **downgraded.** Primary data now
   lives on LittleFS (internal flash), which is copy-on-write and
   brownout-resilient; the counter is in transactional NVS. SD holds only
   the backup mirror + archive, so a corrupt or absent card loses backup,
   not live data — the device runs standalone with no card. Log stays
   append-only + per-line CRC so a torn tail line is skipped on recovery.
2. ~~**SPI bus contention**~~ — **resolved.** SD is on its own SPI host,
   so it never touches `gSpiMutex`. No contention with the PN5180 or TFT.
3. **Flash wear** — writes happen at *weigh cadence* (occasional), not
   the 1 Hz reconciliation poll (reads/network only), so LittleFS
   wear-leveling keeps internal flash well within endurance for years.
4. **Backup freshness** — single device. SD mirror + web `/export` give
   off-device copies; mirror lag is the only exposure if flash itself
   ever failed (rare).

## Open questions

- Snapshot cadence + retention: when to write a verified snapshot (after
  onboarding, on card insert, periodic) and how many dated history files
  to keep — trades backup freshness/depth against card wear and space.

Resolved (see `implementation-plan.md` → Decisions LOCKED): network mode
= **station + AP fallback**; partition = **single app, no OTA, 2 MB FS**;
web stack = **ESPAsyncWebServer**.

## Explicitly out of scope

- Physical keyboard for onboarding — rejected. Adds USB-host firmware
  and hardware for worse UX than a browser form.
- **Resistive touchscreen — left unwired.** The board bundles resistive
  touch (T_xx pins) + stylus, but it simplifies nothing: the common path
  is hands-free (place/remove spool), and the only input-heavy task
  (onboarding) is far better on a browser form than a stylus + on-screen
  keyboard. The two conveniences touch might have offered are handled
  elsewhere instead — tare capture lives in the onboarding web form
  (`POST /tare`), and the web-UI address is shown on the idle screen. Not
  worth the 5 pins, XPT2046 driver, panel calibration, and parallel UI.
- **FRAM (e.g. Qwiic MB85RC256V) — considered, deferred.** Byte-atomic,
  ~10¹² write endurance, would drop onto the existing I²C/Qwiic bus. But
  LittleFS + NVS already give power-safe primary storage and a
  transactional counter with **zero added hardware**, so FRAM buys little
  for v1. Revisit only if a guaranteed-atomic ring buffer of the last N
  events (independent of any filesystem) is ever wanted.
- Any external server or cloud dependency.

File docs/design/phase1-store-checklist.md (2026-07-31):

# Phase 1 — `store` Core: Task Checklist

Foundation everything else sits on. Headless (no web); driven/tested over
serial with **simulated events**, so it's not blocked by the load cell.

**Prereq (Phase 0):** LittleFS data partition mounts; SD reads/writes.
Phase 1 assumes LittleFS is mountable — it does not need SD (SD is Phase 6).

**Definition of done (milestone):** inject a mix of onboard/weigh events
over serial → indices correct → power-cycle → indices identical (rebuilt
from log) → append a deliberately torn line → recovery skips it and the
rest is intact.

## Progress

**Code landed** (`src/store.h`, `src/store.cpp`, wired into `main.cpp` +
`scale_task.cpp` serial): tasks **1.1–1.8 implemented**. CRC round-trip and
torn-tail skip verified against a Python mirror; brace/paren balance clean.
**Not yet compiled/flashed** (no PlatformIO here) — 1.9 is on-hardware
verification: run the serial script, power-cycle, confirm the milestone.

**Flash size — RESOLVED (Phase 0 partition CSV still to write):** the
board is **4 MB flash / 2 MB quad PSRAM** (ESP32-S3-MINI-1-N4R2 — verified
on hardware with esptool; earlier 8 MB and 16 MB guesses were both wrong).
**Confirm with `esptool flash_id`** before cutting the CSV (one search
snippet mentioned a 4 MB N4R2 variant — unlikely given the JSON, but a 4 MB
board would not fit dual-OTA + a useful FS).

Partition (`partitions.csv`): **no OTA** (panel USB is full-function, so
firmware flashes over USB) → single 1.875 MB app + **2 MB LittleFS**
(~800 spools w/ full history). `storeBegin()` mounts LittleFS on the
`spiffs`-labelled partition.

---

## Design details to fix first

### Log line schema (per event type)
Append-only NDJSON, one object per line, newline-terminated, flushed after
each write. **Refinement over the design doc:** identity fields must live
in the log (on `onboard`/`reconcile`) so the spools index is fully
rebuildable — weigh lines stay lean.

```jsonc
// onboard / reconcile — carry identity (from the tag Main section)
{"ts":"2026-07-14T18:03:11Z","ev":"onboard","uuid":"<hex32>","spool":42,
 "vendor":"Prusament","mat":"PETG","abbr":"PETG","rgba":[227,111,17,255],
 "dia":1.75,"empty_g":201.0,"nom_g":1000.0,"needs_ob":true,"crc":"a1b2c3d4"}

// weigh — lean; weights only
{"ts":"...","ev":"weigh","uuid":"<hex32>","spool":42,
 "gross_g":812.4,"remaining_g":611.4,"used_g":188.6,"crc":"…"}
```

- `ev` ∈ `onboard | weigh | reconcile | reorder_flag | export`.
- `uuid` = tag `instance_uuid`, 32 hex chars (the store lookup key; the same
  value Spoolman formerly used as `nfc_id`).
- `spool` = local auto-increment ID (NVS counter).
- `crc` = CRC-32 (IEEE 802.3, poly 0xEDB88320) over the exact line bytes
  **from `{` up to and including the comma before `"crc"`** — i.e. the
  serialized object minus the `,"crc":"…"}` tail. Documented precisely so
  encode and verify agree byte-for-byte.
- Numbers: grams to 1 decimal; fixed formatting so CRC is deterministic.

### Sub-decisions to resolve in this phase
- **Timestamp source.** ESP32 has no battery RTC. Options: NTP when
  station-connected; manual "set clock" via web (Phase 4); accept
  approximate/relative time offline. Field is ISO-8601 UTC regardless;
  pick the populate path. *(Proposed: NTP-when-available + web manual-set;
  until then, boot-relative — flag events written before time is known.)*
- **Index persistence.** Rebuild-from-log on every boot (simplest; a few
  MB parses fast) vs persist `/index/*.json` and only rebuild on
  miss/corrupt. *(Proposed: rebuild-on-boot for Phase 1; add persisted
  snapshots later if boot time bites.)*
- **Concurrency.** `store` is touched by nfc_task (append), display
  (read), web (read/write). Guard with a `gStoreMutex`; keep the critical
  section to the in-memory index + the file append.

---

## Tasks

### 1.1 Module skeleton + types
- `src/store.h` / `src/store.cpp`. Structs: `StoreEvent` (tagged union by
  `ev`), `SpoolRecord` (current state), `MatInventory` (material → grams).
  Event-type enum. Path constants (`/log/events.ndjson`, `/index/…`).
- **Done:** compiles; `storeBegin()` stub mounts LittleFS.

### 1.2 NVS spool-ID counter
- Namespace `"store"`, key `"counter"` (u32). `storeNextSpoolId()` =
  atomic read-increment-commit; `storePeekSpoolId()`.
- **Done:** IDs are unique and monotonic across power cycles; never reused.

### 1.3 Log line codec + CRC
- `encodeEvent(StoreEvent&) -> String` and `decodeLine(line, StoreEvent&)`
  with CRC compute + verify per the spec above.
- **Done:** round-trips every event type; a flipped byte fails verify.

### 1.4 Append path (durable)
- `storeAppendEvent()`: serialize → append to log → `flush()`/`close()` →
  update in-memory indices under `gStoreMutex`.
- **Done:** N appends = N valid lines; a power cut mid-append leaves ≤1
  torn line and never corrupts earlier lines.

### 1.5 Index model + in-memory maintenance
- Apply each event to indices: `onboard` creates/updates identity +
  `needs_onboarding`; `weigh` updates weights + derives remaining;
  `reconcile` updates identity. Inventory = Σ remaining per material.
- **Done:** after a sequence, queries reflect correct current state.

### 1.6 Index rebuild (log replay)
- `storeRebuildIndices()`: stream the log, verify each CRC, **skip a torn
  tail line**, apply in order. Called on boot when indices absent/stale.
- **Done:** clear RAM → rebuild → indices identical to pre-wipe; torn tail
  skipped, earlier data intact.

### 1.7 Query / read API
- `storeGetSpool(id)`, `storeFindByUuid(uuid)`, spool iteration,
  `storeInventoryByMaterial()`. Read-only, mutex-guarded snapshots.
- **Done:** display can render the current spool from `store` alone.

### 1.8 Serial test harness
- Commands (115200): `EV onboard <uuid> <vendor> <mat> …`,
  `EV weigh <uuid> <gross_g>`, `DUMP spools|inv`, `REBUILD`, `LOGSTATS`
  (lines/bytes/last-CRC), `TORN` (append a partial line), `WIPE`.
- **Done:** the whole milestone test is scriptable over serial.

### 1.9 Milestone verification
- Script: inject mixed events → `DUMP` → power-cycle → `DUMP` matches →
  `TORN` → reboot → recovery skips the torn line, rest intact.
- **Done:** milestone criteria all pass; record the transcript.

---

## Not in Phase 1 (later phases)
- SD backup/snapshots/restore → Phase 6.
- Config catalog (vendors/materials/…) → Phase 3.
- Any web/HTTP → Phase 4+.
- Repointing nfc_task off Spoolman → Phase 2 (Phase 1 only injects events
  via serial; nothing calls `store` in the live flow yet).

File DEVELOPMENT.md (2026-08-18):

# Development & flashing

The assembled weigh station on the workbench

> **Just want to flash a station, not modify the firmware?** Skip this
> whole document — download the four files from the
> [latest release](https://github.com/NormSohl/openprinttag-weigh-station/releases/latest)
> and flash with `esptool` directly. See
> [`docs/build-guide.md`](docs/build-guide.md#6-flashing-the-firmware) for
> the exact command. Everything below is for building from source: making
> firmware changes, or targeting a board/partition layout no release
> covers yet.

This is a [PlatformIO](https://platformio.org/) project. The toolchain, the
ESP32 platform, and every library install themselves on the first build — you
don't hand-install any of that. The same build runs in CI on every push, so a
green local build should match CI.

## 1. Install the tools

**Recommended — VS Code + PlatformIO:**

1. Install [VS Code](https://code.visualstudio.com/).
2. Install [Git](https://git-scm.com/downloads).
3. In VS Code → Extensions → search **"PlatformIO IDE"** → Install. It bundles
   its own Python and the `pio` CLI — nothing else to set up.

**Or CLI-only:** install
[PlatformIO Core](https://docs.platformio.org/en/latest/core/installation/index.html)
(`pip install platformio`, or the standalone installer).

> **Windows:** the VS Code route is the path of least resistance — no Python to
> install, no PATH to edit, and no USB driver (see §5). Open the repo folder and
> VS Code will offer the PlatformIO extension automatically (it's recommended in
> `.vscode/extensions.json`). If you use PowerShell directly and `pio` isn't
> found, either use the PlatformIO toolbar buttons instead or add
> `%USERPROFILE%\.platformio\penv\Scripts` to your PATH.

## 2. Get the code

```bash
git clone https://github.com/NormSohl/openprinttag-weigh-station.git
cd openprinttag-weigh-station
```

## 3. Build

The first build downloads everything (the `espressif32` platform, the GCC
toolchain, and all `lib_deps`: PN5180, NAU7802, TFT_eSPI, ArduinoJson,
WiFiManager, AsyncTCP, ESPAsyncWebServer, tinycbor, …).

- **VS Code:** open the folder; PlatformIO auto-detects `platformio.ini`. Click
  the **✓ (Build)** button in the bottom status bar.
- **CLI:** `pio run`

## 4. Connect the board and flash

The target is a **SparkFun Thing Plus ESP32-S3** (`sparkfun_esp32s3_thing_plus`),
flashed over USB-C.

1. Plug the board into USB-C.
2. Upload: the VS Code **→ (Upload)** button, or `pio run -t upload`.
   - A normal upload writes the **bootloader + partition table + app**
     together, so the custom `partitions.csv` (single 1.875 MB app + 2 MB
     LittleFS, no OTA) takes effect on the first flash automatically.
   - **Download mode (expect to need this on the very first flash):** the S3's
     native USB won't present a bootloader until it's told to. Hold **BOOT**
     (IO0), tap **RESET** (EN), release **BOOT**, then upload. After one good
     flash the auto-reset works on its own.
   - Optional clean slate the first time: `pio run -t erase` before uploading.

> **Native USB, no bridge chip.** The Thing Plus ESP32-S3 wires USB-C straight
> to the chip's USB — there is **no CP210x/CH340 serial bridge**, so there's no
> vendor driver to install, and the port is **`ttyACM*` / `cu.usbmodem*` /
> `COMx`**, *not* `ttyUSB*`. (If you're hunting for `/dev/ttyUSB0`, that's why
> it's not there.)

**No filesystem image to upload.** Config tables seed themselves at first boot
and the web UI is embedded in the firmware, so there is no `uploadfs` step — a
plain upload is complete.

## 5. Serial monitor (optional)

```bash
pio device monitor -b 115200
```

For boot logs and the capacity/test harness (`SEED <spools> <events>`, `DUMP`,
`LOGSTATS`, `REBUILD`, …). WiFi setup is shown on the TFT and
calibration/onboarding are done in the browser, so the serial console is **not**
required for bring-up — but on the *first* power-on it's the single most useful
instrument (see the expected output below). `pio device list` prints the port.

If the monitor is blank after a successful upload, it's the ESP32-S3 native-USB
CDC quirk: add `-DARDUINO_USB_CDC_ON_BOOT=1` to `build_flags` in
`platformio.ini` (depends on the board's USB wiring).

### Serial port access & drivers (per OS)

No driver install — native USB is class-compliant CDC. The only per-OS bit is
**permissions / a couple of well-known gotchas**:

- **Linux** — add yourself to the serial group once, then log out/in:
  ```bash
  sudo usermod -aG dialout $USER      # (or `uucp` on Arch)
  ```
  If the port appears then **vanishes after ~1 s**, the culprit is almost always
  `brltty` (a screen-reader daemon that grabs ACM devices):
  `sudo apt remove brltty`. Port is `/dev/ttyACM0`.
- **macOS** — nothing to install; port is `/dev/cu.usbmodemXXXX`. (Only a
  *bridge* board would need the SiLabs VCP driver — this one doesn't.)
- **Windows** — Win10/11 install the USB-CDC class driver automatically; it
  shows up as `COMx` in Device Manager. No Zadig needed for flashing/monitoring
  (Zadig is only for the separate JTAG interface, which we don't use).

## 6. Editor automation (VS Code)

Committed in `.vscode/` so it works the moment you open the folder:

| Task | What | How |
|---|---|---|
| **Pull, Flash & Monitor** | `git pull` → build → upload → serial monitor | **Ctrl+Shift+B** (default build task) |
| Flash & Monitor (no pull) | same, but builds exactly what's on disk | Ctrl+Shift+P → *Run Task* |
| Build / Flash / Monitor | the individual steps | Ctrl+Shift+P → *Run Task* |
| List serial ports | `pio device list` — find the COM port | Ctrl+Shift+P → *Run Task* |
| Erase flash | clean slate; **wipes LittleFS** (log, config, WiFi, calibration) | Ctrl+Shift+P → *Run Task* |

Build errors are parsed by the `$gcc` problem matcher, so compiler messages
become clickable file:line links in the Problems panel.

**Crash decoding is on.** `monitor_filters` in `platformio.ini` enables
`esp32_exception_decoder`, which rewrites a panic backtrace from raw addresses
into function + file:line — so a first-boot crash reads as
`nfcTask() at src/nfc_task.cpp:112`, not `Backtrace: 0x42008f3a 0x3ffb2280`.
Lines are also timestamped (`time`).

## First-boot bring-up (no PC needed after flashing)

> **First power-on: leave the microSD slot empty and keep the serial monitor
> open.** SD is the only brand-new, unvalidated wiring — it's fail-safe (boots
> fine with no card), so keeping it out means it can't muddy the first log. Add
> the card once the core is proven.

**What a healthy boot prints.** The subsystems come up as independent tasks, so
even a dead peripheral won't hide the others — read the banner to see who's
alive:

```
[store] ready: 0 spools, 0 log lines, next id #1
[cfg]   ready: N vendors, N materials, N profiles, N colors, N stock
[sd]    no card (backup to SD disabled until inserted)
*wm:AutoConnect ...            <- WiFiManager (portal or join)
```

Then the TFT lights and shows `WiFi Setup` (or the idle screen once joined). A
missing line points straight at the section to drill into — e.g. no `[cfg]`
means LittleFS didn't mount; a hang right after `SPI.begin` points at the shared
PN5180/TFT bus.

1. **WiFi:** on first boot the TFT shows `WiFi Setup` — join the
   `WeighStation-Setup` network and enter the lab WiFi. After that it runs in
   plain station mode at `http://weighstation.local` (no access point). If it
   can't reach the network it falls back to the `WeighStation` SoftAP.
2. **Find the UI:** the idle screen shows the web address.
3. **Calibrate:** open the web UI → **Calibrate** → *Zero* (empty scale) then
   *Set calibration* (known weight + its grams). The "not calibrated" banner
   clears when done. (Serial `ZERO` / `CAL <grams>` still work as a fallback.)
4. **Onboard a spool:** place a blank tag → 5-second confirm countdown → a stub
   is created → fill in the details at **Onboard**.

## Verifying the flash size

The partition map targets **4 MB** flash (ESP32-S3-MINI-1-N4R2), verified on the board. Re-check if you swap boards:

```bash
pio pkg exec -- esptool.py flash_id   # expect "Embedded Flash 4MB", "PSRAM 2MB"
```

## Project layout

| Path | What |
|---|---|
| `src/main.cpp` | task setup + shared globals |
| `src/nfc_task.cpp` | PN5180 / OPT tag read + write |
| `src/scale_task.cpp` | NAU7802 load cell + calibration |
| `src/sync_task.cpp` | state machine, WiFi/AP, tag ⇄ store reconcile |
| `src/web_app.cpp` | built-in web UI (inventory, onboard, reorder, calibrate, history, backup) |
| `src/store.*` | append-only event log + indices (LittleFS) |
| `src/config_store.*` | onboarding catalog tables |
| `src/display_task.cpp` | TFT + buzzer + NeoPixel |
| `platformio.ini` | build config incl. TFT_eSPI settings (passed as -D flags) |
| `.vscode/` | shared editor setup: tasks, extension recommendation, terminal settings |
| `partitions.csv` | flash layout |
| `docs/design/` | architecture + implementation plan (+ post-bringup backlog) |

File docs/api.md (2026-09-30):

# HTTP API

The assembled weigh station on the workbench

The station serves its web app and a small JSON API from the same server on
port 80. Base URL is `http://weighstation.local/` — or the raw IP, which is
worth preferring for anything automated, since mDNS is unreliable across VLANs
and from some Linux hosts. Pin it with a DHCP reservation.

Everything below is stable enough to build against; `state` values come from
`deviceStateName()` in `src/device_state.h`.

---

## Reading

All read endpoints are **open** — no key needed — so dashboards and scrapers
work with no configuration.

| Endpoint | Content-Type | Purpose |
|---|---|---|
| `GET /api/status` | JSON | Everything a dashboard polls: state, spool on the scale, weight, WiFi, storage health |
| `GET /api/spools` | JSON | Every spool: id, uuid, vendor, material, colour, remaining/used grams, product reference, cost, onboarding flag, retired flag |
| `GET /api/products` | JSON | Every product: what we stock, as opposed to the spools on the shelf |
| `GET /api/stock` | JSON | Every Stock List item (what to keep + its reorder threshold), each with its 90-day popularity |
| `GET /stock.csv` | CSV | Every Stock List item, no popularity — plain line-by-line list for comparing against physical bins/tags |
| `GET /reorder?format=csv` | CSV | Stock items below threshold |
| `GET /api/usage` | JSON | Consumption per month per vendor+material, grams and dollars (all-time, coarse — see `/api/stock` for the finer-grained, windowed number) |
| `GET /usage.csv` | CSV | Same data for spreadsheets and analysis pipelines |
| `GET /api/scale` | JSON | Live load-cell reading + calibration flag |
| `GET /api/storage` | JSON | Log size, free space, compaction due, write-failure flag |
| `GET /export` | NDJSON | The complete raw event log — the full backup artifact |
| `GET /config/export` | JSON | The Config catalog (vendors/materials/spool-profiles/colors/stock-items) as one file — a separate backup from `/export`; see below |
| `GET /events` | `text/event-stream` | Server-Sent Events push — see below |

> **`color` is `null` when no colour has been assigned**, on both `/api/spools` and
> `/api/status` — it is not `"000000"`. A spool onboarded before its colour was
> known, and any foreign tag that omits OpenPrintTag's `primary_color` key, has no
> colour rather than a black one, and a consumer must be able to tell those apart.
> `material` carries the OPT display string (`"PLA Summer Grass"`); the bare type
> code is on the record as the abbreviation and is what `/api/usage` groups by.
>
> **`cost` follows the same rule** — `null`, not `0`, when no price was recorded
> for that spool. A spool nobody priced is not a free spool, and filtering for
> `cost == null` is how you find the ones still missing one. It is the price of
> the whole spool as entered at onboarding, not a per-gram rate; `/api/usage`
> derives its dollar figures from it.

### `GET /api/products`

A **product** is a filament SKU; a spool is one instance of it. A spool's
vendor, material, colour, diameter, tare and nominal weight are a resolved
*cache* of its product's, so both endpoints report them and they agree.

```json
[
  { "id": 3, "vendor": "Prusament", "material": "PLA Galaxy Black",
    "abbr": "PLA", "color": "112233", "diameter_mm": 1.75,
    "empty_g": 201.0, "nominal_g": 1000.0, "provisional": false,
    "package_uuid": "…", "gtin": "8595581746018" }
]
```

- **`product` on `/api/spools` is `null`, not `0`**, for a spool that predates
  products or whose tag could not be resolved. It keeps working; it simply
  belongs to no product.
- **The four OpenPrintTag identity keys are omitted when the tag carried none**
  (`package_uuid`, `material_uuid`, `brand_uuid`, `gtin`) rather than sent as
  `""`. Absent is not the same as known-empty.
- **`gtin` is a string.** It is an identifier, and JSON numbers go through a
  double in most consumers.
- **`provisional: true`** means the product was inferred by adopting a tag and
  no human has confirmed it. Provisional products are excluded from tag
  write-back, so adopting a spool can never make the station rewrite a vendor's
  tag from data it guessed.

Products are created, never updated, by both onboarding paths and by tag
adoption — a product edit propagates to every tag of that product, so one odd
tag must not be able to rewrite a shelf, and neither should a typo corrected on
one spool's form. The single place an edit is allowed is `POST /api/product`
(behind the `/product?id=N` page, which names the spools the edit will touch
before you save). It updates the definition, clears `provisional`, and emits one
`Reconcile` per spool of the product. See `docs/design/product-instance.md`.

### `GET /api/stock`

```json
{
  "window_days": 90,
  "data_since": "2026-08-14T03:51:15Z",
  "items": [
    { "id": 7, "vendor": "eSun", "material": "PLA Beige", "color": "", "dia": 1.75,
      "spool_g": 1000.0, "min_spools": 1, "min_grams": 0.0,
      "sku": "", "gtin": "", "pack_qty": 1,
      "has_data": true, "grams_in_window": 820.0, "available_days": 41.2,
      "grams_per_week": 139.3 }
  ]
}
```

Every row is a Stock List item — what you've decided to keep, not what's
currently on the shelf (that's `/api/products`/`/api/spools`) — paired with its
**popularity**: grams consumed in the trailing `window_days`, divided by the
days that material was actually *in stock* (combined on-hand across every
spool of it), not by the calendar window. A material that sold out on day 2 of
90 and sat empty the other 88 is scored on those 2 days, not diluted across
90 — a stockout must never make a popular material look unpopular.

- **`id`** is the row's stable, never-reused identifier, and is what
  `/api/stock/update` and `/api/stock/delete` take. It is deliberately *not*
  the row's position in `items` — positions shift whenever anything is added
  or removed, so an id captured from an earlier read stays valid (or fails
  cleanly as gone), while a position silently comes to mean a different row.
- **`material` usually carries the colour and `color` is empty.** A row
  linked to a product (the normal case — picking an existing product,
  a catalog search, or manual entry, all link one) reports that product's
  full display name, e.g. `"PLA Beige"`, exactly as a spool's OpenPrintTag
  `material_name` holds it. `color` is only populated separately on an
  unlinked row, where `material` is then the bare type (`"PLA"`).
- **`has_data: false`** means the item was never in stock at all during the
  window — the strongest possible signal it's a candidate to remove from the
  Stock List, not an edge case to hide. `grams_per_week` is `null` in that case.
- **`data_since`** is the earliest event timestamp actually found in the log.
  If it's less than `window_days` ago, coverage is shorter than the window
  implies — shown rather than silently assumed.
- This is computed fresh from the log on every request (a bounded, read-only
  pass, same cost class as compaction) — it is not the same permanent,
  coarser rollup `/api/usage` reports, and the two numbers for the same
  material will not match.

### `GET /api/status`

```json
{
  "firmware": "1.0.0",
  "build_version": "milestone-2026-08-16-3-gabc1234",
  "state": "present",
  "uptime_s": 84213,
  "heap_free": 142360,
  "scale":   { "weight_g": 1243.5, "calibrated": true },
  "spool":   { "id": 42, "uuid": "e0040108660759df", "vendor": "eSun",
               "material": "PLA+ Summer Grass", "color": "1b1b1b",
               "remaining_g": 812.0, "needs_onboarding": false },
  "wifi":    { "mode": "station", "ssid": "Neverhood2",
               "ip": "192.168.50.127", "rssi": -54 },
  "storage": { "spools": 37, "log_bytes": 214880, "log_lines": 1442,
               "usage_rows": 18, "free_bytes": 1680384,
               "compact_due": false, "write_failed": false },
  "auth":    { "required": true }
}
```

`spool` is `null` when nothing is on the scale.

`build_version` is `git describe --tags --always --dirty` at build time --
which commit is actually flashed on this unit, distinct from `firmware`
(a hand-maintained semver that doesn't move on every commit). A `-dirty`
suffix means the working tree had uncommitted changes when it was built.

### GET /events

A persistent Server-Sent Events stream the built-in web app uses to update
itself live (see `CLAUDE.md`'s *Live page updates (Server-Sent Events)*
section for which pages watch it and why). Each message is:

```
event: state
data: <spool id>,<needs_onboarding 0/1>,<audit phase 0/1/2>,<audit found>,<audit total>
```

`<spool id>` is `-1` when nothing is on the scale; audit phase is
`0` Idle / `1` Scanning / `2` Resolving. A message is sent on every device
state change, on every audit start/finish/abandon/close/found action, and
once immediately to every client the instant it (re)connects — so a client
that only just opened the connection, or reconnected after a drop, is caught
up without needing a follow-up request.

**Don't react to a message by fetching more detail.** An earlier version of
this stream sent a bare "something changed" ping and expected listeners to
`fetch('/api/status')` to find out what — found on hardware to silently
stall under load, because this server holds very few concurrent connections
(see *Polling* below) and that fetch was racing the already-open SSE
connection for one. The message body above carries everything a listener
should need instead.

This is a genuine long-lived connection, unlike everything else in this
document — count it against the "few concurrent connections" budget
mentioned below if you're also polling other endpoints from the same client.

### Polling

`ESPAsyncWebServer` holds few concurrent connections. Poll on the order of
seconds, one client at a time; don't point a multi-worker scraper at it.
`/api/status` exists precisely so a dashboard needs one request, not six.
`/events` is the exception to "poll" — open it once and listen.

---
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

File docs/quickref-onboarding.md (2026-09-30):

# Quick Reference — Onboarding a New Spool

*Print this page and keep it at the station. Full detail: [user-manual.md](user-manual.md).*

Mainly for processing new stock as it arrives from a vendor — once per new,
untagged reel.

## Steps

1. **Apply an OpenPrintTag sticker** to the spool's flat hub face — centered
   so it lands over the reader. Press firmly.
2. **Place the spool on the scale.**
3. The display shows a 2-second countdown, then in the last second the digit
   turns **red** and the text switches to **"Writing tag now!"**:

   > New tag found
   > Remove to cancel
   > Registering in: 2…

   - **Remove the spool** within the countdown to cancel (e.g. it landed on
     the scale by accident).
   - **Leave it in place** to confirm — the station formats the tag and
     assigns a spool number.
4. Display shows the spool number and a QR code:

   > Registered!  Spool #58  212 g
   > NEEDS ONBOARDING

   The spool is now trackable but has no material data yet.
5. **Enter data for the new spool from any web browser.** Scan the QR code
   with your phone or tablet, or browse to `weighstation.local/onboard` on
   any device on the same network, while the spool is still on the scale.
6. On the **Onboard** page, the "This spool is…" dropdown defaults to
   **"a new product"**:
   - Already have this exact product on file? **Scroll down to select
     "another spool of X"** — it inherits vendor/material/colour/tare with
     nothing to retype. Different kind of spool this time? Set its tare
     below; it applies to this spool only.
   - New product (the default)? **Search the catalog first** — picking a
     real result fills in brand, material, colour, print temps, and vendor
     identifiers automatically.
   - Not in the catalog? Expand **Enter details manually**. Vendor, material,
     and colour each default to whatever you picked last time, and each has
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

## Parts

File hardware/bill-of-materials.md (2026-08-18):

# Bill of Materials — opt-weigh-station

Everything needed to build one weigh station, beyond the fasteners
(see `fastener-schedule.md` for screws, inserts, washers).

## Electronics

| Item | Spec | Qty | Notes |
|---|---|-----|---|
| ESP32-S3 dev board | SparkFun Thing Plus ESP32-S3 | 1 | Native USB CDC, Qwiic on GPIO 8/9 |
| NFC reader module | PN5180-NFC (ISO 15693) | 1 | **Needs BOTH rails:** 3.3 V logic *and* 5 V on the module's RF/antenna-driver pin (VUSB). 3.3 V alone can answer SPI but produce no usable RF field |
| Load cell amplifier | NAU7802 (SparkFun Qwiic Scale) | 1 | I²C, on Qwiic bus |
| Load cell | TAL220B, 5kg, 55×12.7×12.7mm | 1 | Single-bolt mount, ~40mm hole spacing |
| TFT display | Hosyond 3.5" ILI9488 SPI TFT, 480×320, resistive touch (MSP3520-type) | 1 | Amazon (Hosyond Store, sold by HONGXINBAORUI), ~$17.99; incl. stylus. SPI, shared bus with PN5180; CS GPIO 15, DC GPIO 16, RST GPIO 17. On-board microSD **not wired** (no SPI peripheral left — see netlist.md); resistive touch (T_xx pins) intentionally unwired |
| Piezo buzzer | Passive, GPIO 14 | 1 | Feedback tones |
| USB-C panel-mount cable | Full-function extension, panel-mount | 1 | Routes the ESP32's **native USB-C** to the panel — the single port for the whole unit: power, serial console, and firmware flashing (no OTA needed). Supersedes the earlier power-only USB-C breakout board. |

## Mechanical — Printed Parts

| Part | Material | Notes |
|---|---|---|
| Base | PETG | 4 walls, 40% infill near load cell boss |
| Deck | PETG or PLA | Prints face-down for finish |
| Platform | PLA | Disc, Ø205mm, prints face-down |
| Spigot | PLA | Centering cone |
| Tray | PETG or PLA | Carries ESP32 + NAU7802 |
| Porch display faceplate | PETG | `porch-tft-faceplate.scad`; thin retainer plate over the display opening, front face down, no supports |

**Print envelope check:** platform Ø205mm fits the Prusa MK4S bed (210mm Y)
with 2.5mm margin per side. Base footprint 200×140×60mm.

> **Known issues / errata:** see
> [`printed-parts-issues.md`](./printed-parts-issues.md) for deferred
> fixes (load-cell boss stiffening, TFT adapter window/depth) before the
> next print revision.

## Mechanical — Hardware (Wiring)

| Item | Spec | Qty | Notes |
|---|---|-----|---|
| Hookup wire | Thin stranded, various colors | — | Slack loop required between RFID platform and controller — a stiff harness corrupts load cell readings |
| Dupont jumpers / crimp housings | 2.54mm pitch | — | Per user's preferred prototyping style |
| Header pins | 2.54mm | — | For breakout board connections |

## Fasteners

See `fastener-schedule.md` for the complete screw/insert/washer list
(19 heat-set inserts, 23 screws, 23 washers, 4 nuts — incl. 4× M3×10 into
heat-set bosses for the display faceplate and 4× M2.5×8 + nut for the
display board).

## OPT NFC Tags

| Item | Spec | Qty | Notes |
|---|---|-----|---|
| Blank OpenPrintTag (10 NFC tags) — MK1 sticker | Prusa's own tag product | as needed | What this project actually uses. From Prusa directly: [prusa3d.com](https://www.prusa3d.com/product/blank-openprinttag-10-nfc-tags/), $5.55/10-pack. From [Printed Solid](https://www.printedsolid.com/products/original-prusa-blank-openprinttag-10-nfc-tags), Prusa's **official US distributor** (Prusa Research acquired them in 2022; US-based warehouse in Delaware), $7.99/10-pack — check stock, this SKU sells out periodically. See `docs/user-manual.md` for how they're applied |
| Blank ISO15693 NFC tags (alternative) | ICODE SLIX2-compatible — **not** NTAG (that's ISO14443A, incompatible) | as needed | The station formats a blank tag itself on first placement; no pre-formatting needed. NFC Tools app is only for manually formatting/testing tags outside the station's own flow |

## Open Items — Not Yet Specified

These appear in the design but don't have confirmed part numbers or
quantities yet:

- **NAU7802 mounting screws/board hole size** — not measured against
  the actual board; assumed M3, may be M2 (see fastener schedule notes)
- **Rubber feet** — base has recesses for them (4 corners) but no
  spec/source chosen yet
- **External server hardware** — no longer needed. The station is
  self-contained (local storage + built-in web app), so there is no
  Spoolman/Prometheus host to source. (Was previously an open item.)
  <!-- (Display microSD interface pinout — RESOLVED: the SD lines are on a
       separate header, not bonded to the TFT bus, now wired to a dedicated
       2nd SPI host at GPIO 10/18/21/42. See netlist.md and
       display-hosyond-ili9488.md.) -->

## Tools Required (not consumed, but needed for assembly)

- Soldering iron (heat-set insert installation)
- 2.5mm and 3mm hex keys (M3/M4 SHCS)
- 4mm hex key (M5 SHCS)
- Digital calipers
- NFC Tools app (NDEF tag formatting) + NFC.cool Tools (tag testing)

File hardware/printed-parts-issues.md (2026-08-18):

# 3D-Printed Parts — Known Issues / Errata

Field-found problems with the printed parts, and the fixes made. Issues 1-3
have been printed and verified as of 2026-08-16. Issues 4 and 5 are design
fixes that exist only in SCAD — render-verified, never printed — and are
**closed without a reprint as of 2026-08-17**: the current prototype was
built from an earlier revision and is working fine as-is, and another
costly print run isn't planned unless a second unit gets built. If that
happens, pick these back up and validate on hardware before trusting them.
**Issue 6 is OPEN** — a field workaround exists, but the SCAD itself still
needs to be fixed. Kept here as the errata history — add a new row and
update status the same way if a future print turns up a new issue.

Related files: [`weighstation.scad`](./weighstation.scad),
[`porch-tft-faceplate.scad`](./porch-tft-faceplate.scad).
`porch-tft-adapter.scad` (issues 2 and 3 below) is no longer in the repo
— superseded by the faceplate (issue 5) and removed rather than kept for
reference, so those two entries describe a file that no longer exists.

| # | Part | Severity | Status |
|---|---|---|---|
| 1 | Base — load-cell fixed-end boss | High (affects weighing accuracy) | **Fixed & verified** — reinforced boss printed, no visible deflection under load |
| 2 | Porch TFT adapter — window + pocket depth | Medium (fit/assembly) | **Fixed & verified** — printed, fits as designed. Superseded in the source by issue 5 for any future unit; the current prototype keeps this printed adapter and is working fine |
| 3 | TFT adapter top edge fouls the overhanging platform | High (blocks weighing) | **Fixed & verified** — plate_y 67→63 + plat_gap 2→5 (~3.1mm), printed and clears |
| 4 | Base — hairline crack at the bottom of the front-corner crevice (rounded body meets porch wedge) | Low (unprintable cusp, not a structural issue) | **Closed, not printed** — final fillet design (repositioned + enlarged, sliced clean of the porch face and display recess) is render-verified only. Current prototype predates this fix and is working fine as printed; no reprint planned for this unit |
| 5 | Porch TFT adapter → flush faceplate (mount redesign, not a defect) | — design change, not a fault | **Closed, not printed** — `porch-tft-faceplate.scad` replaces the adapter with a thin flush plate over an enlarged opening, held by 4 corner screws into heat-set bosses in the porch wall. Render-verified, mounting holes confirmed coaxial with the bosses. Current prototype keeps the printed adapter (issue 2) and is working fine; banked for the next unit built |
| 6 | Base — load-cell fixed-end mount, fastener access | Medium (field workaround exists; not yet modeled) | **OPEN** — the built unit needed a hand-drilled, countersunk hole through the case underside to run a long screw up into the fixed-end mount. Works well as a physical fix, but hasn't been carried back into `weighstation.scad` |

---

## 1. Load-cell fixed-end boss (pillar) deflects under load

**File:** `weighstation.scad` — load-cell fixed-end boss, ~line 408
(`cube([18, lc_w + 8, lc_boss_h])`, i.e. ~18 × 20.7 × 46 mm tall).

**Symptom:** under scale load the printed boss/pillar that anchors the
load cell's fixed end **flexes**, so part of the deflection is taken up by
the mount instead of by the strain-gauge beam. The load cell must be the
*only* compliant element in the load path; a springy mount corrupts the
reading (non-linear, hysteresis, drift).

**Interim workaround:** the pillar cross-section was increased on the
built unit to stiffen it.

**Fix applied to SCAD:** the boss's fore-aft (X) footprint — the direction
it bends — is widened on both sides: a full-height extension rearward
(`lc_boss_ext`, −X) and wider ±Y (`lc_boss_wide`), plus a forward
(`lc_boss_fwd`, +X) buttress toward the free end that stops `lc_beam_gap`
(5 mm) below the bar so the beam still deflects freely. Fore-aft base
grows from 18 mm to ~43 mm. Only the strain-gauge beam should move.

> The first attempt used a `hull()` of thin boxes as a rear buttress —
> that rendered as a degenerate zero-thickness sheet ("polygon with no
> sides", Volumes: 2). Replaced with the solid +X buttress above.

**Verified (2026-08-16):** printed with `lc_boss_ext` / `lc_boss_fwd` /
`lc_boss_wide` as committed in the SCAD — single solid volume, +X buttress
clears the overload-stop post. Re-checked under a full-scale test weight:
no visible boss deflection; the load cell's strain-gauge beam is the only
compliant element in the load path. Cross-ref the load-cell install guide
([`docs/datasheets/load-cell-install-guide.md`](../docs/datasheets/load-cell-install-guide.md))
— "force direction perpendicular, rigid mount" — satisfied.

**Render-verified (2026-08-16, OpenSCAD 2021.01, headless):** `openscad -D
part="base" --render` reports `Simple: yes`, `Volumes: 2` — a single
connected manifold solid, not the disconnected-sheet failure this note
originally warned about. (The "expect Volumes: 1" comment above was itself
wrong: CGAL's Nef-polyhedron count always includes the unbounded exterior as
an extra volume, confirmed by rendering a plain merged two-cube test case
alongside a genuinely disconnected one — a single real part always reports
2, not 1.) Buttress-to-post clearance computed directly from the SCAD
variables (`lc_x0=-27.5`, buttress far edge at X=1.5, overload-stop post
near edge at X=18): **16.5 mm**, matching the "~16 mm" estimate.

---

## 2. Porch TFT adapter — window size and pocket depth

**File:** `porch-tft-adapter.scad` — **removed from the repo**, superseded
by `porch-tft-faceplate.scad` (issue 5). Entry kept as historical record
of a real fit issue and its fix.

**Change A — enlarge 0.5 mm PER SIDE, opening + surrounding shelf
equally.** The 0.5 mm is per side (i.e. +1.0 mm on each overall
dimension), applied equally to the bezel window opening **and** the shelf
/ pocket recess around it — so the lip width is unchanged, the whole
recessed area just grows. In the SCAD: `win_x` 85→86, `win_y` 55→56, and
grow the `pocket_x`/`pocket_y` recess by the same 0.5 mm/side.

**Change B — +10 mm to the WHOLE object (taller walls), to seat the
header.** The 10 mm applies to the entire part, not just the pocket floor:
plate thickness / perimeter walls grow by 10 mm (`plate_t` 5→15) so the
adapter becomes a deeper tray whose raised walls house the board's pin
header. This **eliminates the slot cut** for the header pins.

**Status:** **Fixed & verified** — applied to `porch-tft-adapter.scad`:
`win_x` 85→86, `win_y` 55→56; `pocket_clr` 0.4→1.4 (pocket grown 0.5 mm/
side); `plate_t` 5→15 with `pocket_d` 3.2→13.2 (keeps the 1.8 mm bezel
lip, adds 10 mm of wall to house the soldered header). The design now
**keeps the header** rather than desoldering it. Printed and verified
(2026-08-16):

- Header stays soldered: the wire notch is **removed**; wires exit the
  **open back** into the porch cavity. No back cover / cable relief — the
  open back is intentional. Confirmed on the printed part.
- A **microSD access slot** was added in the top wall (card exits the top;
  socket on the PCB back). First print had it on the wrong side and a bit
  tight — corrected: offset flipped to **+18 mm**, width **22 mm**
  (+3/side), and the display-side edge extended 1.5 mm (Z 4.7→11.2).
  Reprinted with the corrected offset/width and now clears.
- Screws pass through 15 mm of plate now — use M3×20+ (noted in the SCAD
  header). Confirmed on the printed part.
- Printed and test-fit against the board and bezel — fits as designed.

**Render-verified (2026-08-16, OpenSCAD 2021.01, headless):** `openscad
--render` reports `Simple: yes`, `Volumes: 2` (single connected solid, same
CGAL convention as the base part above). `win_x`/`win_y`/`pocket_clr`/
`plate_t`/`pocket_d`/`plate_y`/`sd_slot_offset`/`sd_slot_w` all confirmed
present in the SCAD exactly as described above.

---

## 4. Hairline crack at the bottom of the front-corner crevice

**File:** `weighstation.scad` — `base()`, SOLIDS union, ~line 288
(`fillet_r`).

**Symptom:** at both front corners (where the main shell's rounded corner
transitions into the 45-degree porch wedge), a hairline crack runs down the
outer wall from the top rim, right where the curved wall and the flat porch
wall meet. Spotted in an exterior render, not yet on a physical print.

**Root cause — genuinely different from a modeling gap.** The crescent-
shaped notch/crevice at this corner (bounded by `rrect()`'s corner arc on
one side and the porch wedge's exposed front face on the other) is the
*intended* shape of this transition — it's what a rounded corner meeting a
sharp-edged wedge looks like, and it's the look this corner is meant to
have. The problem is narrower than that: the arc is centred at
(`porch_x0+corner_r`, `base_w/2-corner_r`), so at X=`porch_x0` its tangent
direction is exactly vertical — the same direction as the porch's flat
face there. A tangent meeting closes the gap to **exactly zero width at one
point** and opens up on either side of it. No nozzle can resolve a
zero-width feature, so that one point prints as a hairline gap even though
the model is a valid, fully manifold solid there (confirmed: `Volumes: 2`,
`Simple: yes`, unchanged before and after the fix below — this was never a
hole in the geometry, just a cusp too fine to print).

**First attempt (reverted):** a full-height gusset cube filling the entire
crevice. This closed the crack, but also squared off the whole notch,
changing the corner's silhouette — not what was wanted. Reverted
(`git revert`) in favour of the fix below.

**Fix, first pass (superseded, see below):** a small vertical cylinder
(`fillet_r` = 1.5mm radius, full base height) at each front corner — not
filling the crevice, just padding the point where it pinches to zero. The
broader crescent shape stays exactly as it was.

> **First version of this fix was itself broken** — centred exactly on the
> tangent point (X=`porch_x0`), which straddles the porch wedge's own
> boundary there. The porch's top edge is a 45-degree slope: its solid
> only reaches the full `base_h` height exactly AT X=`porch_x0`, receding
> forward in Z for every mm forward in X past it. A cylinder centred ON
> that boundary therefore pokes a visible stub through the receding slope
> near the rim on the porch side, even though it's fine on the shell side
> — caught visually (a render sent for review showed it clearly) before
> ever reaching a printer. Fixed by moving the cylinder's centre to
> X=`porch_x0 + fillet_r`, keeping the entire cylinder at X >= `porch_x0`
> (tangent to the boundary, never crossing it) — entirely on the
> shell/void side, where nothing recedes with height, so it can safely run
> the full `base_h`. Confirmed by isolating just the porch wedge and the
> fillet cylinder in a standalone test file and rendering an orthographic
> side profile: the cylinder's silhouette sits entirely inside the wedge's
> own outline at every height.

**Render-verified (2026-08-16, OpenSCAD 2021.01, headless):** `openscad -D
part="base" --render` reports `Simple: yes`, `Volumes: 2` — unchanged from
both the original and the (reverted) gusset version, still one connected
solid. The hairline seam is gone in the same exterior viewpoint used to
find it, and the crescent notch's overall shape is visibly preserved (not
squared off) compared side-by-side with the gusset version.

**Fix, final (2026-08-17) — the tangent-point fillet above undersold the
real gap.** Tracing the actual cross-section showed the porch cavity's own
cut leaves only a thin, Z-sliding sliver of the wedge's rear wall standing,
so the true gap between the shell's rounded corner and the porch's back
wall is far wider than a single tangent point through most of the case's
height (derived exactly: `gap(Z) = 55.757 - Z` for Z in [13.757, 56.5]).
The fillet is now anchored where two fixed planes meet instead — the
porch's own back face (`X = porch_x0`) and the case's inside wall
(`Y = 64.5`, the porch cavity's own Y-extent boundary) — confirmed solid by
cross-section at multiple heights, radius bumped 1.5mm → 2.0mm, then
sliced against the porch's own 45-degree roof plane and the real display
cutout geometry so it can't poke through the sloped face or intrude on the
faceplate's recess (this fix also caught and closed a related poke-through
into the display pocket — see issue 5). Render-verified: `Simple: yes`,
`Volumes: 2`, unchanged.

**Closed 2026-08-17, not printed.** The current prototype was built before
any of this section's fillet work and is working fine as printed — the
crack was only ever seen in a render, never confirmed as a real defect on
this unit. No reprint is planned to validate the fillet fix; if a second
unit gets built, print it with the current SCAD and confirm the crevice is
actually gone and the fillet doesn't foul the faceplate before trusting
this closed.

---

## 5. Porch TFT adapter replaced by a flush faceplate

**Files:** `porch-tft-faceplate.scad` (new); `weighstation.scad` — `base()`,
"porch display faceplate" boss section.

**This is a design change, not a fault fix** — logged here because it
retires the part covered by issue 2 and shares the same corner-fillet
history as issue 4 above. `porch-tft-adapter.scad` mounted the display
proud, through-bolted, as a full-face panel; it has been **removed from
the repo** (2026-08-17) now that this faceplate is the intended part —
see issue 2 and the top-of-doc note for what that means for those
historical entries.

**New design:** the display sits flat against the porch's own front face,
in a large opening cut directly into `base()`. `porch-tft-faceplate.scad`
is a thin retainer plate over that opening — a bezel window, held down by
4 corner screws into heat-set-insert bosses that reach sideways to the
porch's own real side walls (not a wall behind the opening, so display
wiring keeps a clear path through). The board itself is still held by its
own 4 screws through the plate into a nut behind it, the same mechanism
the adapter used.

**Mounting-hole coaxiality confirmed** (2026-08-17): the faceplate's
corner screw holes (`boss_u`/`boss_v` in `porch-tft-faceplate.scad`) and
the porch's heat-set bosses (`disp_boss_u`/`disp_boss_v` in
`weighstation.scad`) are hand-copied between the two files, not shared
code — checked by extracting the live values from both real files via
OpenSCAD `echo()` rather than trusting the source comments: both resolve
to identical U/V offsets (23.1198mm / 61.3mm). The two files code the
local frame with X/Y transposed relative to each other, but the hole
pattern is a symmetric `±U, ±V` rectangle, so that's immaterial — only the
magnitudes matter, and they match exactly.

**Closed 2026-08-17, not printed.** Render-verified only (`Simple: yes`,
`Volumes: 2` for the base with the new boss geometry). The current
prototype keeps the printed adapter from issue 2 and is working fine; this
faceplate is banked for the next unit built, not scheduled for a reprint
of this one. If a second unit gets built: print the faceplate, confirm all
4 screws seat straight into their bosses with no binding, and confirm the
board still clears the bezel window before trusting this closed.

---

## 6. Load-cell fixed-end mount needed a field-drilled, countersunk access hole

**File:** `weighstation.scad` — load-cell fixed-end boss (same area as
issue 1's stiffening fix, but a different problem: this one is about the
fastener's access path, not the boss's stiffness).

**Symptom:** as printed, the boss didn't provide a workable way to
actually drive the mounting screw into the strain gauge's fixed end. The
designed path (per issue 1's fix and `fastener-schedule.md`: M5×30 SHCS
down through the platform and load-cell bar into a top-of-boss insert)
wasn't usable in practice on the built unit.

**Field fix (2026-08-17):** drilled through the case from underneath and
countersunk the hole, then ran a long screw up into the mount from below
instead. Works well — the load cell is properly secured — but this was a
hand-drilled modification to the physical part, not a SCAD change, so
none of it is reflected in `weighstation.scad`.

**Status: OPEN.** Not yet investigated in the model. Before designing a
fix: pin down *why* the top-down path wasn't usable (tool/screwdriver
clearance under the platform once assembled? insert depth or thread
engagement issue? something else?), then model the underside access hole
and countersink as a real feature — including whatever floor thickness
and boss geometry changes that implies — so a future print doesn't need
the same manual drill-and-countersink step. Not printed, not
render-verified — this is only a written record of the field fix so far.

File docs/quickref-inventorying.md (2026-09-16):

# Quick Reference — Inventorying

*Print this page and keep it at the station. Full detail: [user-manual.md](user-manual.md).*

Two things live under this heading: checking what's on hand day-to-day, and
periodically running a physical shelf audit.

## Checking what's on hand (no action needed)

Browse to `http://weighstation.local/` — every weigh already updates this
automatically.

| Page | What it shows |
|---|---|
| **Inventory** | Remaining filament by material, grouped by vendor. Click a row to see individual spools; click a spool number for its weigh history. |
| **Stock List** (`/stock`) | The curated "what we keep buying" list, each item with a 90-day popularity score. Lowest-popularity and never-in-stock items sort to the top — those are the candidates to reconsider. It's normal for inventory to hold material *not* on this list (phased-out stock). |
| **Reorder** | Stock List items at or below their threshold — download a CSV, or use Copy list / E-mail this list to place the order. |
| **Usage** | The permanent, all-time consumption record by month/year — CSV download. |

## Running a physical audit (e.g. monthly shelf inventory)

An audit finds spools that have gone missing without anyone recording it, and
retires them properly instead of leaving the count wrong forever.

1. On **Inventory**, click **Start audit**.
2. **Weigh every spool** — a normal weigh during the audit window marks that
   spool "found" automatically, no extra step. **Leave the Inventory page
   open** while you work — the found count updates itself live as each spool
   is weighed.
3. When every spool has been checked, click **Finish audit**. The page now
   lists every spool that was *not* seen, each with two buttons:
   - **Found** — it's physically there but wasn't weighed (eyeballed it
     on the shelf). No weight change.
   - **Close** — it's genuinely gone. Its last known weight is recorded as
     consumed and it's marked **retired**.
4. Resolve **every** not-found spool one of those two ways — there's no bulk
   action and no way to leave some undecided. Once the last one is resolved,
   the audit closes itself.
5. **Abandon audit** at any point backs out of the audit itself, without
   undoing any Found/Close already recorded.

**Retired spools aren't deleted** — their history still counts toward Usage
and Stock List popularity, but they're hidden from Inventory by default (a
count + show/hide toggle reveals them). If a "retired" spool turns up and gets
weighed again, it automatically un-retires — no extra step.

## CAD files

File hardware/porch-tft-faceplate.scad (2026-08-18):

// SPDX-License-Identifier: GPL-3.0-or-later
// Copyright (C) 2026 Norm Sohl

// =============================================================
// porch-tft-faceplate.scad — thin retainer plate for the porch's TFT
// window, replacing an earlier through-bolted adapter design (removed
// from the repo -- note this design itself is still render-verified
// only, not yet printed or fitted to real hardware; see
// printed-parts-issues.md issue 5).
// =============================================================
// The display sits FLAT against the porch's own front face, directly in
// the large opening cut in weighstation.scad's base() -- it is no longer
// housed in a deep pocket machined into this plate. This plate exists
// only to make mounting easy: a thin frame with a bezel window, held
// down over the board by 4 corner screws into the porch's own
// heat-set-insert bosses (see weighstation.scad, "porch display
// faceplate" comment in base()'s interior-bosses section). The board
// itself is still held by its own 4 screws through the plate into a nut
// behind it, the same mechanism the old adapter used.
//
// Dimensions here MUST match weighstation.scad's disp_* variables and
// the ILI9488 board geometry -- kept in sync by hand, not shared code,
// same as the old adapter's screw pattern always was.
//
// Print: PETG, 3-4 walls, 15-20% infill, FRONT FACE DOWN on bed (flat,
// no supports needed -- same convention the old adapter used).
// Corner screws: 4x M3x10 SHCS + M3 washer, straight into the porch's
// heat-set-insert bosses -- no nut, nothing reached through the porch
// wiring passage (that was the old adapter's M3x25+nyloc pattern; this
// plate doesn't use it). Board screws: 4x M2.5x8 SHCS + M2.5 washer +
// M2.5 nyloc nut behind the board, same as the old adapter used.
// =============================================================

$fn = 64;
eps = 0.01;

// ── Plate dimensions ────────────────────────────────────────────────────
// Matches weighstation.scad's disp_open_w/disp_open_u (134.6 x 58.2396)
// minus clearance to seat in the opening, same 0.6mm-total convention the
// deck uses against its own rebate ledge. disp_rim_w (there) is set to
// porch_edge_w-0.3 so this plate's own final installed edge measures
// exactly porch_edge_w (3mm, matching the deck's edge) once the 0.3mm
// fit clearance is added back on -- see weighstation.scad's disp_rim_w
// comment for the derivation. (Earlier history: disp_rim_w went 1mm ->
// 2mm after a hairline crack/hole showed up at the front-corner fillet;
// this 2.7mm is a further tuning of that same number, not a reversion.)
plate_v = 134.6  - 0.6;   // 134     -- face-width (V)
plate_u = 58.2396 - 0.6;  // 57.6396 -- up-slope   (U)
plate_t = 3;              // matches wall -- "as thick as the top panel"
corner_r = 7;   // matches weighstation.scad's corner_r-1 (the deck's own corner radius), for visual consistency

// ── Corner mounting screws (plate -> porch bosses) ──────────────────────
// Must match weighstation.scad's disp_boss_u/disp_boss_v exactly.
// Plain through-hole, no counterbore: a proper SHCS counterbore is 5.8dia
// x 3.5 deep (m3_cbore_d/m3_cbore_h elsewhere in this project) -- more
// depth than this whole 3mm plate has. The deck solves the same problem
// by hanging a reinforcing pad off its back at each screw, extending the
// local material enough to hold a real counterbore with floor to spare.
// Doing that here means re-coordinating the porch's insert-boss depth to
// match, for a screw head that's only ever seen from an angle anyway --
// not worth it. Head sits proud instead, same call already made for the
// board-mounting screws below.
boss_v = 61.3;      // disp_open_w/2 - 6
boss_u = 23.1198;   // disp_open_u/2 - 6
m3_cl_d = 3.4;

// ── Display bezel window ─────────────────────────────────────────────────
// Unchanged from the old adapter design -- the viewable active area.
win_v = 86;
win_u = 56;

// ── ILI9488 TFT — MSP3520-type PCB, landscape (for reference; the board
//    itself sits directly against the porch face now, not in a pocket
//    here) ──────────────────────────────────────────────────────────────
tft_pcb_v = 98.00;
tft_pcb_u = 56.34;

// ── Board mounting screws (plate -> board -> nut behind), same mechanism
//    and same pattern the old adapter used: cap proud on the front,
//    shaft through the board's corner hole into a nut trapped behind it. ──
brd_screw_v = 46;     // +-46mm (V), 92mm c-c
brd_screw_u = 25;     // +-25mm (U), 50mm c-c
brd_screw_d = 2.7;    // M2.5 clearance bore

module rrect(l, w, h, r) {
    linear_extrude(h)
        offset(r) offset(-r) square([l, w], center = true);
}

module faceplate() {
    difference() {
        rrect(plate_v, plate_u, plate_t, corner_r);

        // bezel window, full thickness
        translate([0, 0, -eps])
            linear_extrude(plate_t + 2*eps)
                offset(0.5) offset(-0.5)
                    square([win_v, win_u], center = true);

        // 4x corner mounting screws: plain clearance bore, head proud
        for (sv = [-1, 1], su = [-1, 1])
            translate([sv*boss_v, su*boss_u, -eps])
                cylinder(d = m3_cl_d, h = plate_t + 2*eps);

        // 4x M2.5 board-mounting bores, plain through-holes, cap proud
        for (sv = [-1, 1], su = [-1, 1])
            translate([sv*brd_screw_v, su*brd_screw_u, -eps])
                cylinder(d = brd_screw_d, h = plate_t + 2*eps);
    }
}

faceplate();

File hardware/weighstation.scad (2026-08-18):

// SPDX-License-Identifier: GPL-3.0-or-later
// Copyright (C) 2026 Norm Sohl

// =============================================================
// OpenPrintTag Weigh Station — parametric enclosure
// =============================================================
// Rev — see printed-parts-issues.md:
//   #1 load-cell fixed-end boss reinforced (fore-aft footprint widened;
//      +X buttress capped below the bar so the beam still flexes).
//   Porch UI reworked: OLED/button/LED removed; single TFT opening, now
//   covered by a flush faceplate (porch-tft-faceplate.scad) on corner
//   heat-set bosses inside the cavity -- superseded an earlier
//   through-bolted adapter design, since removed from the repo.
//   plat_gap 2->5: raises the platform so it clears the display
//   mount's top edge (with plate_y=63) — boss grows ~3mm (see fastener
//   note).
//   Reinforcement render- and print-verified 2026-08-16 — see
//   printed-parts-issues.md.
// =============================================================
// Parts: set `part` below (or via -D part="...") and export STL.
//   "platform"  — weighing disc + antenna pocket (prints top-face-down)
//   "spigot"    — separate centering cone, bolts to platform center
//                 (swap spigots for different hub bores)
//   "base"      — shell + 45-deg UI porch, load cell boss, tray bosses
//                 (prints fully open-topped — zero bridging)
//   "deck"      — drop-in top plate closing the corners the platform
//                 doesn't cover; rests on the base's rebate ledge
//   "tray"      — electronics tray (modules + crimped jumper harnesses)
//   "assembly"  — preview of everything in place (don't print)
//
// MEASURE BEFORE PRINTING (the four numbers that must match reality):
//   hub_bore_d        — measured: 53mm
//   tag_ring_r        — set from the MK1 drawing (35.8mm); only revisit
//                       if a future tag revision changes coil geometry
//   (load cell: measured — TAL220B 55mm, one M5 per end @ 7.5mm)
//   pcb_hole_*        — tray/boss mounting pattern (shared by base + tray)
//
// Print notes: base in PETG (4 walls, 40% infill near the
// load cell boss), platform + spigot in PLA. All screws: metric
// socket head (SHCS) + washers on plastic. Heat-set inserts:
//   M3 (Ruthex RX-M3x5.7) — tray bosses, deck columns, overload stop
//   M4 (Ruthex RX-M4x6.0) — platform center (spigot bolt)
//   M5 (Ruthex RX-M5x7.0) — load cell fixed-end boss
// =============================================================

part = "assembly"; // [assembly, platform, spigot, base, deck, tray]

$fn = 96;
eps = 0.01;

// ---------------- heat-set insert pockets (Ruthex press-fit style) --------
// Pocket diameter = insert OD; pocket depth = insert length + 0.5mm lead-in.
// All inserts are installed from the TOP of the boss/post (iron in from above).
// Screw clearance bores are Ø = nominal + 0.4mm throughout.
m3_ins_d  = 4.6;   m3_ins_l  = 6.2;   // M3 insert (Ruthex RX-M3x5.7): OD 4.6, L 5.7+0.5
m4_ins_d  = 6.0;   m4_ins_l  = 6.5;   // M4 insert (Ruthex RX-M4x6.0): OD 6.0, L 6.0+0.5
m5_ins_d  = 7.4;   m5_ins_l  = 7.5;   // M5 insert (Ruthex RX-M5x7.0): OD 7.4, L 7.0+0.5
// Socket-head cap screw (SHCS ISO 4762) counterbore dims:
// M3: head Ø5.5 x 3.0 → cbore Ø5.8 x 3.5
// M4: head Ø7.0 x 4.0 → cbore Ø7.4 x 4.5
// M5: head Ø8.5 x 5.0 → cbore Ø9.0 x 5.5
m3_cbore_d = 5.8;  m3_cbore_h = 3.5;
m4_cbore_d = 7.4;  m4_cbore_h = 4.5;
m5_cbore_d = 9.0;  m5_cbore_h = 5.5;

// ---------------- spool / tag ----------------
hub_bore_d   = 53;     // measured spool center bore (Jun 2026)
// Tag geometry per the official MK1 drawing
// (specs.openprinttag.org/media/tag_mk1.pdf): tag OD Ø90; antenna coil
// traces occupy the zone between Ø64 and Ø79.1 → coil mean radius ≈36mm.
// The reader couples to the COIL, so the pocket centers on this radius.
tag_ring_r   = 35.8;   // MK1 coil mean radius (was a 60mm placeholder)

// ---------------- platform ----------------
plat_d       = 205;    // fits the MK4S bed (210mm Y, 2.5mm/side margin);
// holds Ø200 spools with the rim still 2.5mm proud — contact is near
// the hub regardless. Bump to 220 only if printing on an XL.
plat_t       = 8;   // disc top is dead flat (prints face-down).
// All fasteners are metric SOCKET HEAD cap screws (user stock), washer
// under every head on plastic. Both platform fastenings live inside
// the spool's Ø53 bore shadow: the free-end M5 counterbore floor
// stacks on the integral spacer pad (2mm disc + 3mm pad = 5mm), and
// the spigot uses an M4 through-bolt from above into a captive-nut
// trap recessed in the underside — no island, no protrusions.
spigot_h     = 45;
spigot_top_d = 30;     // cone: top narrower than hub bore for easy drop-on
spigot_clr   = 1.0;    // diametral clearance at hub seat

// ---------------- load cell (5 kg bar, 80x12.7x12.7 typ.) ----------------
// TAL220B, per datasheet (measured Jun 2026): 55 x 12.7 x 12.7mm,
// ONE M5 per end, holes 40mm apart (7.5mm from each end). Single-bolt
// ends can rotate about the bolt — both mounts get anti-rotation
// features (cradle walls at the fixed end, flanking ribs at the free
// end). Rated output 1.0 mV/V; ultimate overload 150%FS (7.5kg on a
// 5kg cell) — the stop bolt is not optional.
lc_len  = 55;
lc_w    = 12.7;
lc_h    = 12.7;
lc_hole_from_end = 7.5;  // both ends, M5
spacer_h        = 3;    // flex clearance both ends
plat_gap        = 5;    // platform floats this far above the base rim
                        // (raised 2->5 so it clears the TFT adapter's top
                        //  edge; pairs with plate_y=63 -> ~3.1mm clearance)
// Boss height is DERIVED so the platform always clears the shell:
// raise the bar high enough that (boss + bar + spacer) tops the rim.
// (was a fixed 14mm — which buried the platform inside the box)

// ---------------- base ----------------
base_l   = 200;
base_w   = 140;
base_h   = 60;
wall     = 3;
corner_r = 8;
// Target width of the wall remaining around the deck once it's actually
// installed (the deck rebate ledge's own inset, in base(), PLUS the
// deck plate's 0.3mm fit clearance beyond that ledge -- see both use
// sites). Was an uncancelled wall+0.3=3.3mm; set to exactly `wall` on
// request so the deck's real edge measures the same 3mm as the general
// wall thickness. Global, not local to base() or deck(), because both
// modules need the identical number and are otherwise independent.
deck_edge_w = wall;
// Same idea, for the porch faceplate: disp_rim_w (below, near the
// display-opening variables) is set to porch_edge_w-0.3 so the
// faceplate's own installed edge also lands on exactly `wall`, matching
// the deck's treatment above.
porch_edge_w = wall;

// ------------- electronics tray mounting -------------
pcb_l = 80;  pcb_w = 50;   // tray fits the -Y half, clear of the central load-cell band
pcb_hole_inset = 5;     // hole centers from each edge
pcb_boss_h = 8;
pcb_pos = [20, -38];    // tray in -Y half: clears central LC/stop band, columns, walls

// ---------------- antenna (PN5180-NFC module) ----------------
// Board measured: 40 x 70mm, +5mm radial relief so wires reach the
// header without binding. Header (JP1) sits at the INWARD end, antenna
// coil at the OUTWARD end — the radial cable channel exits inward-to-
// outward, but the header needs to reach DOWN through the platform to
// the base, so the channel still routes from the pocket's outer edge
// to the rim (matches existing harness routing in base()).
ant_l = 40;              // tangential extent (board width, across header)
ant_w = 70 + 5;          // radial extent (board length + 5mm wire relief)
ant_t = 3.5;             // pocket depth
ant_angle = 90;          // angular position on tag ring (deg, 0 = +X)
ant_web_t = 2;           // plastic left between pocket and platform top
// Pocket center is offset OUTWARD from the tag-ring antenna reference
// point (ant_pos, used elsewhere for the OPT coil alignment and the
// base harness pass-through) so the pocket's inward edge clears the
// center M4 boss (Ø10 counterbore, 5mm radius) with a 3mm wall margin.
ant_clear_r   = 8;                          // min radial clearance from center
ant_pocket_dy = ant_clear_r + ant_w/2;      // pocket center offset along radius

// ---------------- ports / UI ----------------
usb_w = 12;  usb_h = 7;            // rear cutout for USB-C breakout module
// The SSD1306 OLED, panel button, and status LED are REMOVED — replaced
// by a single 3.5in ILI9488 TFT on a printed faceplate (porch-tft-faceplate.scad).
// The faceplate is centred on the porch face and fastened with 4x M3
// into heat-set bosses in the porch wall.
// 45-degree UI porch: a wedge extending forward past the platform edge,
// carrying the display on its sloped face, angled at the user.
porch_len = 45;                    // how far the wedge extends (also = height drop @45)
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

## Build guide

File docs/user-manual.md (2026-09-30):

# Weigh Station — User Manual

The assembled weigh station on the workbench

The Weigh Station is a self-contained filament inventory tool for the Seattle
Makers 3D-printing lab. Place a spool on the scale; it reads the NFC tag, weighs
the spool, and records the remaining filament **on the device**. A built-in web
app (`http://weighstation.local/`) shows inventory and history, onboards new
spools, flags reorders, and takes backups. There is no external server.

**Printable one-page quick references**, for posting at the station itself:
[Weighing a spool](quickref-weighing.md) ·
[Onboarding a new spool](quickref-onboarding.md) ·
[Inventorying](quickref-inventorying.md). (There's also a
[Tag Erase](quickref-tag-erase.md) one-pager, but that workflow isn't in
active use right now.)

---

## For Members: Weighing a Spool

1. **Place the spool on the scale.** The NFC reader and load cell activate
   immediately — no button press needed.
2. **Wait for the display to settle.** It shows the spool number, material, and
   remaining weight for a second or two.
3. **Remove the spool.** The display returns to the idle screen.

That's it — the reading is saved locally, and a weigh entry is added to the
spool's history.

### What the display shows

The idle screen in person: Seattle Makers, Place spool to begin, the web app address, and a QR code

The 3.5" screen shows one of these, depending on what's happening:

| Display | Meaning |
|---|---|
| Idle screen: Seattle Makers, Place spool to begin, web app address, and a QR code | **Idle, ready** — place a spool to begin |
| Weighing screen showing grams | **Weighing** — reading the load cell |
| Present screen: spool number, material, grams remaining, Weight recorded | **Done** — spool number, material, and remaining weight recorded locally |
| Registered screen: Registered!, spool number and weight on one line, NEEDS ONBOARDING, Scan QR to add details or visit the Onboard page, both addresses, and a QR code | **New spool registered** — scan the QR or visit the **Onboard** page to fill in the material details (see *New Spools* below) |
| Updating tag screen | **Updating tag** — writing updated filament data back to the NFC tag |
| Idle screen with a Scale not calibrated warning and a QR code | **Not calibrated** — shown on idle until the scale is calibrated (weights are unreliable until then) |

> **Opening the web app from your phone.** The idle screen shows a **QR code** on
> the right — scan it with the camera and it opens the app directly. The address
> is also printed as text: `weighstation.local` for typing, with the numeric IP
> underneath as a fallback. Use the numeric one if `.local` doesn't resolve,
> which happens on some Android browsers and across some networks. (The QR
> always encodes the numeric address, for exactly that reason.)

### Status light (NeoPixel)

| Color | Meaning |
|---|---|
| Dim green | Idle, ready |
| Blue | Working (WiFi setup, weighing, writing tag) |
| Green | Spool weighed and saved |
| Yellow | Spool registered but needs details entered in the web app |
| Amber (blinking, accelerating) | New-tag countdown — remove the spool to cancel |
| Red | Tag read error — reposition the spool |

---

## For Members: New Spools

When you place a spool with a **blank NFC tag** on the scale:

1. The display shows a **2-second countdown** — "New tag found / Remove to
   cancel / Registering in: 2…". The window is short, so in the last second
   the digit turns red and the text switches to "Writing tag now!" as a final
   heads-up.

   New tag found screen with a large countdown digit

2. **Remove the spool within 2 seconds** to cancel, or **leave it in place** to
   proceed.
3. The station formats the tag and creates a placeholder record on the device.
   The display shows `Registered!`, the spool number, and **NEEDS ONBOARDING**
   — the spool has no vendor, material or colour yet, so it is not usable for
   inventory until step 4. **Scan the QR code on that screen** to jump straight
   to the form for this spool, or type either address it shows —
   `weighstation.local/onboard` or the numeric one below it. Both go to the
   **Onboard** page, which acts on whichever spool is currently on the scale.

   Registered screen: Registered!, spool number and weight on one line, NEEDS ONBOARDING, Scan QR to add details or visit the Onboard page, both addresses, and a QR code

4. **Open the web app and fill in the material details** for that spool — see
   *Onboarding a spool* below.

Once the details are saved, the NFC tag is written with the real data — either
right away if the spool is still on the scale, or the next time it's placed.

### Onboarding a spool (web app)

1. With the spool on the scale, browse to `http://weighstation.local/` on any
   phone or laptop on the same network.
2. Open **Onboard**. If this is another spool of something already on file,
   pick **another spool of X** — it inherits the vendor, material, colour and
   tare with nothing to retype. If this one came on a different kind of spool
   (a vendor sometimes switches spool bodies), set its tare below; the product
   keeps its own. For something new, choose **a new product**.
3. **Search the catalog first.** Typing a vendor or material name searches the
   published OpenPrintTag catalog directly; picking a real result fills in the
   brand, material, colour, print temperatures, and the manufacturer's own
   identifiers — the same data a genuine vendor tag carries. If the filament
   isn't in the catalog, expand **Enter details manually** and pick the
   **vendor**, **material**, and **color** from the lab's own lists — each
   picklist defaults to whichever choice was used last, so onboarding a batch
   of the same shipment doesn't mean re-picking the same vendor for every
   spool. Any of them has a **+ Add new** option if it isn't in the list yet —
   no need to visit Settings first to add it.

   **Spool profile** sits next to the tare field, outside the manual section,
   and works however you identified the filament — catalog pick, manual
   entry, or **another spool of X**. It's a preset for the empty spool's weight: picking one fills in
   the **tare** box for you. It starts on **— choose a spool profile —**
   every time, rather than on the last one used, so what the tare box shows
   is always what will be saved. It has its own **+ Add new** option. If you
   entered details manually you must pick one: it also sets the spool's
   nominal full weight, and the form won't save without it. After a catalog
   pick it's optional; leaving it unchosen keeps the catalog's own tare.
   Anything you type in the tare box yourself wins. You can also
   capture the tare from a matching empty spool with **Capture tare**. (If
   you chose **another spool of X**, a blank tare box means the product's
   tare; anything you pick or type is used for this spool only.)

   **Every spool needs a tare.** The form won't save if it would end up with
   none — for example a catalog product with no empty weight listed, or a
   spool profile without one. Type it, pick a profile that has one, or use
   **Capture tare**. Without it the station would count the empty spool as
   filament. A spool or product saved before this rule shows its tare as
   *not recorded*; fix a product's on its own page.

   **Cost for this spool** is optional: enter what the reel cost if you know
   it, leave it blank if you don't. It drives the dollar columns on the Usage
   page. The field is deliberately blank every time the form opens — coming
   back later to fix something else and leaving it empty keeps the price
   already on record rather than wiping it. Enter `0` to clear one.
4. **Save & write tag.** The full OpenPrintTag data (identity, print temps,
   weights) is written to the tag and the record is saved.

### Changing a spool that's already onboarded

If the spool on the scale has already been onboarded, the **Onboard** page
says so and shows what it is, instead of showing an empty form. Nothing needs
entering. Two reasons to go further:

- **Adding a price you didn't have at onboarding.**
- **Fixing a spool attached to the wrong product**, or giving a product to an
  old spool that predates products.

Click **Change this spool's details** to open the form. It opens on the
spool's current product (marked *(current)*), so to add a price, just type it
and save; the spool's identity stays as it was. To attach it to a different
product, pick that product from the list. Choosing **a new product** instead
(typed in or from the catalog) replaces the spool's identity, and the page
asks you to confirm before it does. Saving always rewrites the tag.

### Applying an NFC tag to a new spool

Use an OpenPrintTag MK1 sticker — sourced directly from
[Prusa](https://www.prusa3d.com/), who created and promotes the OpenPrintTag
format itself (see `docs/build-guide.md` if you need to reorder). Peel and
apply to the flat hub face of the spool — away from the filament windings,
centered so it sits over the NFC reader when placed on the scale. Press
firmly for 5 seconds.

**Do not reuse tags.** Peeling a tag risks cracking the foil antenna invisibly.
New tag for every new spool.

### Pre-tagged spools (e.g. Prusament)

Some spools arrive with an NFC tag already applied (genuine Prusament, or spools
tagged by another maker's setup). The station recognizes these as legitimate and
creates a local record from the data already on the tag — no countdown, no
blank-tag flow. It then weighs and records normally.

---

## For Administrators: Initial Setup

Full build/flash steps are in [`DEVELOPMENT.md`](../DEVELOPMENT.md); a short
version follows.

### 1. Hardware assembly

Wire the components per [`hardware/netlist.md`](../hardware/netlist.md). The
NAU7802 connects via a Qwiic cable; the PN5180 NFC module and the ILI9488 TFT
display share the SPI bus.

### 2. Flash the firmware

```bash
pio run --target upload
```

### 3. First-time WiFi setup

On first boot the display shows the WiFi setup screen:

WiFi Setup screen: Join network WeighStation-Setup, then open browser to 192.168.4.1

1. On any phone or laptop, join the `WeighStation-Setup` WiFi network.
2. A captive-portal page opens automatically (or browse to `192.168.4.1`).
3. Select your WiFi network and enter the password.
4. Submit. The device connects to the lab network and the display shows the idle
   screen with its address (`http://weighstation.local/`).

If no network is configured (or it can't be reached), the station falls back to
its own `WeighStation` access point so the web app stays reachable — the idle
screen shows the SSID and address to use.

### 4. Scale calibration (web)

The scale reads raw counts until calibrated; the idle screen shows **"Scale not
calibrated"** until you do this:

Idle screen with a Scale not calibrated warning and a QR code

1. With the spool on/off as directed, browse to `http://weighstation.local/` and
   open **Settings → Calibrate**.
2. **Step 1 — Zero:** clear the scale, then click **Zero (tare)**.
3. **Step 2 — Calibrate:** place a known weight, type its exact mass in grams,
   then **Set calibration**.

The banner clears when it takes. (Serial `ZERO` / `CAL <grams>` at 115200 baud
still work as a fallback.)

---

## For Administrators: Ongoing Maintenance

### The web app

`http://weighstation.local/` provides:

- **Inventory** — remaining filament by material, grouped by vendor. Click a
  row to expand it and see the individual spools, or a spool number to open
  its weigh history + a remaining-over-time sparkline (with CSV export). A
  spool's own page is also where you can check **what it cost** — it shows
  the recorded price, or says plainly that none was recorded, which is how
  you spot spools still needing one. This is also where a physical stock
  **audit** is started — see below.
- **Onboard** — fill in details for a new/blank spool, or add another spool of
  something already on file. For a spool that's already onboarded it says so,
  and keeps the form behind a **Change this spool's details** button.
- **Reorder** — Stock List items at or below threshold; download a CSV to
  place the order.
- **Stock List** (`/stock`) — the curated list of what the lab keeps in stock,
  each with a 90-day popularity score, sorted so the least-popular (or
  never-in-stock) items surface first — see *Deciding what to stock* below.
- **Usage** — the lab's permanent consumption record: how much filament has
  gone through the station, per material, broken down by year, quarter and
  month, all-time; CSV download. Also shows what that consumption **cost**,
  for spools that had a price recorded at onboarding — filament used before
  a price was entered counts its grams but contributes $0, since there's no
  honest way to price it after the fact. (For deciding what belongs on the
  Stock List, prefer the Stock List page's popularity score — it corrects for
  spools that sold out early, which this page's plain totals do not.)
- **Settings** — edit the vendor/material/color/spool-profile/stock-item
  tables, set the WiFi/API-key, choose the display timezone and 12/24-hour
  clock format, rename the station (the idle screen's greeting — "Seattle
  Makers" by default, but any lab running this can make it their own), and
  reach **Calibrate**.
- **Backup** — download the event log; restore from an uploaded backup. Also
  where the separate Settings-table backup lives (see *Recalibrating /
  backups* below).

A product's own edit page (`/product?id=N`) isn't in the top nav — reach it by
clicking a spool's material name on its detail page. Editing there updates
every spool of that product and rewrites their tags automatically the next
time each is placed on the scale.

### Physical inventory audits

Periodically (e.g. a monthly shelf count), do a physical audit: weigh and scan
every spool the lab actually has, and let the station reconcile what wasn't
seen.

1. On the **Inventory** page, click **Start audit**. Spools weighed from this
   point on are marked found automatically — no separate step needed for
   normal weighing during the count.
2. When every spool has been physically checked, click **Finish audit**. The
   page now lists each spool that was never seen during the count, with two
   buttons per row:
   - **Found** — it's on the shelf but wasn't weighed (e.g. you eyeballed it
     without placing it on the scale). No weight change.
   - **Close** — it's genuinely gone. The station records its last known
     weight as consumed (the same as a normal weigh-to-zero) and marks it
     **retired**.
3. Every not-found spool must be resolved one of these two ways before the
   audit finishes — there's no way to leave some undecided. Once the last one
   is resolved, the audit closes itself; there's no separate "finish resolving"
   button.
4. **Abandon audit** drops the audit at any point without undoing anything
   already marked Found or Closed.

**Retired spools are not deleted.** They stay in the inventory history (their
consumption still counts toward Usage and Stock List popularity) but are
hidden from the normal Inventory view by default — a count next to a
**show/hide** toggle reveals them. If a spool marked retired is later found
and weighed again, it's automatically un-retired and rejoins normal tracking
with no extra step.

### Deciding what to stock

The **Stock List** page (`/stock`) is where the lab's day-to-day
"what do we keep buying" decisions happen — it's a curated list, not a
snapshot of everything currently on the shelf (that's Inventory). Each entry
shows a **popularity score**: grams consumed over the trailing 90 days,
corrected so a material that sold out early in that window isn't scored as
if it sat unused the rest of the time. The list sorts lowest-popularity (and
never-in-stock) first, since those are the candidates to reconsider. A
material can be in the lab's inventory without being on the Stock List at
all — that's normal for something being phased out, not an error.

**Adding an entry.** The list comes first on the page; the add/edit form is
below it (the **Edit** link on a row jumps straight down to it). The
"Item is…" dropdown at the top of the form decides how you identify the
filament:

- **Pick one of the listed products** if the lab already has that filament on
  file — nothing to retype.
- Otherwise leave it on **Search catalog or type in** and use the **catalog
  search**, which looks up any real vendor product, including ones the lab has
  never stocked.
- Not in the catalog (a colour the vendor added recently, or an out-of-date
  entry)? Expand **Or enter manually** and pick vendor / material / colour
  from the lists, each with a **+ Add new** option. These default to whatever
  you chose last time, which speeds up entering several at once.

For the catalog and manual routes, fill in **Default spool tare** — the empty
spool's weight. It becomes the product's starting tare, so the first real spool
onboarded against it weighs correctly. Leave it blank after a catalog pick that
already lists an empty weight; otherwise it's required. It's only a default: a
spool that arrives on a different kind of spool gets its own tare when it's
onboarded.

All three routes are equal — each one files the entry against a real product,
so the Stock List can match it against Inventory exactly rather than guessing
from the spelling. That's why there's no separate Color column: a filed entry
shows the product's full name, colour included (for example
"PETG Magenta"), the same way the spool's own tag stores it.

### Changing the WiFi network

**Option A — web (device currently connected):** browse to
`http://weighstation.local/reset` and press **Reset WiFi**. The device reboots
and opens the `WeighStation-Setup` AP; connect and reconfigure as in initial
setup. (Visiting the page does nothing on its own — the button is what triggers
it, so a stray link can't wipe the network config. If an API key is set, you'll
be asked for it.)

**Option B — power cycle (device unreachable):** power-cycle it. If stored
credentials fail, the captive portal opens for **2 minutes** — connect within
that window and reconfigure. **Once your phone joins the AP the countdown
stops**, so there's no time pressure while typing the password. The portal does
close after **10 minutes** no matter what, so an abandoned session can't leave
it open forever — just power-cycle to reopen it. (Holding the BOOT button for 3 s at power-on also
clears WiFi credentials.)

### Recalibrating / backups

Recalibrate any time via **Settings → Calibrate**.

**Back up by downloading the event log** from the **Backup** page — that one
file is the whole backup. It carries current spool state *and* the permanent
consumption totals, and **Restore** puts it back. There is no SD card: the
ESP32-S3 ran out of SPI peripherals, so the slot on the display board is not
wired and nothing is saved to it.

Download a copy whenever you'd mind losing the data — before a firmware
update, before a device swap, or on a monthly reminder. It can be automated;
see the API section below.

**About storage limits.** The log is append-only and the device has about 2 MB
for it. Long before that fills, the station compacts the log on its own while
nothing is on the scale: each spool's history collapses to a single checkpoint
and recent events are kept as-is. **Monthly consumption totals are kept forever
and are never affected.** What compaction gives up is individual weigh readings
older than the retained tail — so if you want the complete weigh-by-weigh
record long-term, download the log periodically. The **Backup** page shows the
current log size and warns you if writes ever start failing.

**The Settings tables (vendors/materials/colors/spool-profiles/Stock List)
back up separately**, also from the **Backup** page: they download and
restore as their own file, independent of the event log. Nothing in a spool's
record points back into these tables by ID, so the two backups don't need to
be kept in sync — and the Settings-only file is also the quick way to hand a
second station the lab's picklists without dragging along this one's spool
history.

---

## For Administrators: HTTP API

Other programs on the network can read from the station directly — a dashboard,
a spreadsheet job, a monitoring script. Everything is plain HTTP on the same
address as the web app. Full reference: [`api.md`](./api.md).

### Reading data (no setup needed)

Read-only endpoints are open, so nothing needs configuring first:

| URL | What you get |
|---|---|
| `/usage.csv` | Consumption per month per vendor + material — a spreadsheet file |
| `/export` | The complete event log (the same file the Backup page downloads) |
| `/config/export` | The Settings tables as one file (the separate backup mentioned above) |
| `/api/status` | Everything at a glance: what the station is doing, what's on the scale, WiFi, storage health |
| `/api/spools` | Every spool and its remaining filament, as JSON |
| `/api/products` | Every product (filament SKU) the station knows about |
| `/api/stock` | The Stock List with each item's 90-day popularity score |
| `/stock.csv` | The Stock List as a plain spreadsheet — handy for checking against the physical bins |
| `/api/usage` | The same data as `/usage.csv`, as JSON |

Automated monthly consumption pull:

```bash
curl -sf "http://weighstation.local/usage.csv" -o "usage-$(date +%F).csv"
```

Nightly off-device backup, which is the same thing the Backup page gives you:

```bash
curl -sf "http://weighstation.local/export" -o "events-$(date +%F).ndjson"
```

> **Use the IP address, not `weighstation.local`, for anything scheduled.**
> The `.local` name relies on mDNS, which is unreliable from some machines and
> across network segments. Give the station a fixed address in your router's
> DHCP reservations and use that.

> **Poll gently** — every few seconds at most, one program at a time. The
> station is a microcontroller and handles only a handful of connections.
> `/api/status` exists so a dashboard can get everything in one request.

### Protecting the write endpoints

By default **anything on the network can change the station** — onboard spools,
edit the config tables, recalibrate the scale, replace the event log, reset
WiFi. On a trusted lab network that's usually fine and keeps things simple.

To require a password for those actions, set an **API key** on the **Settings**
page (bottom of the page, *API access*). Reading stays open; only changes need
the key. The web app will prompt you for it the first time you save something.

Scripts pass it in whichever way suits them:

```bash
curl -X POST -H "X-API-Key: YOURKEY" http://weighstation.local/api/cal-zero
curl -X POST -u :YOURKEY http://weighstation.local/api/cal-zero
```

**If you lose the key,** connect a USB cable, open a serial monitor at 115200
baud, and type:

```
APIKEY none
```

That clears it and reopens the write endpoints. It is the only way back —
changing the key from the web app requires the current one — so the USB port is
worth keeping accessible. `APIKEY` on its own shows the current key.

**What the key is and isn't.** It stops mistakes and casual poking: a script
aimed at the wrong machine, someone exploring endpoints, a browser following a
link to something destructive. It is **not** encryption — the key travels over
the network in the clear, so anyone able to watch lab traffic could capture it.
Treat the network itself as the real boundary, and don't put the station
somewhere a guest network can reach it.

---

## Troubleshooting

### Device won't connect to WiFi

- Power-cycle the device and connect to `WeighStation-Setup` within 2 minutes
  (the countdown pauses as soon as you join, so take your time on the form;
  the portal closes after 10 minutes regardless) to reconfigure.
- If the SSID list in the portal is empty, wait ~30 seconds for the scan and
  refresh the page.

### Tag stuck on "Read error" after a failed registration

If registering a new tag failed partway, the tag is left half-written: it is no
longer blank, but it isn't valid OpenPrintTag data either, so the station shows
**Read Error** every time and there is no way back through the normal flow.

Recover it over USB serial (115200 baud):

```
TAGFORMAT
```

Then lift the spool and place it again. The station rewrites the tag from
scratch and registers it normally.

This is deliberately a manual command rather than something automatic — a tag
the station can't read might be a legitimate tag in a format it doesn't
understand, and reformatting is irreversible.

### NFC tag not reading ("Read error")

- Reposition the spool so the tag is centered over the reader.
- Check that the tag sticker is fully adhered with no air bubbles near the center.
- If the error persists, the tag antenna may be damaged — replace the tag.

### Scale reads zero or wildly wrong values

- Recalibrate: open **Settings → Calibrate**, **Zero** with the platform clear,
  then **Set calibration** with a known weight.
- Check that the load cell wiring hasn't shifted (particularly E+ / E− polarity).

### Display is blank

- Check the TFT's SPI wiring — CS (GPIO 15), DC (GPIO 16), RST (GPIO 17), and the
  shared MOSI/SCK.
- Make sure the backlight (`LED` pin) is powered (tied to 3.3 V) — the panel
  shows nothing without it.

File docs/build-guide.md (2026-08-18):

# Build Guide

The assembled weigh station on the workbench

Everything needed to build your own Weigh Station, start to finish: what it
is, what to buy, what to print, how to wire it, how to flash it, and how to
confirm it actually works before you trust it with your filament.

This guide is the front door — it sequences and links out to the detailed
reference docs rather than repeating them, so those stay the single source
of truth as the design evolves. Read it top to bottom on your first build;
come back to individual sections on a repeat build.

## Contents

1. [What you're building](#1-what-youre-building)
2. [What you'll need](#2-what-youll-need)
3. [Parts & sourcing](#3-parts--sourcing)
4. [Printing the parts](#4-printing-the-parts)
5. [Wiring](#5-wiring)
6. [Flashing the firmware](#6-flashing-the-firmware)
7. [Testing your build](#7-testing-your-build)
8. [Operating it](#8-operating-it)
9. [Troubleshooting](#9-troubleshooting)

---

## 1. What you're building

A **self-contained** NFC + load-cell filament scale: place a spool, it reads
the spool's [OpenPrintTag](https://specs.openprinttag.org) (OPT) NFC
tag — an open spool-identification standard created and promoted by
[Prusa](https://www.prusa3d.com/), the project's namesake (spec source:
[OpenPrintTag/openprinttag-specification](https://github.com/OpenPrintTag/openprinttag-specification))
— weighs it, and records the remaining filament — all on the device itself,
with no server, no cloud account, and no app to install. A built-in web
page (open from any phone or laptop on the same network) handles inventory,
onboarding new spools, low-stock reordering, backups, and calibration.

Why this exists, in case you're deciding whether to build one rather than
buy a commercial equivalent:

- **It speaks the open OpenPrintTag standard**, not a proprietary tag
  format — a spool tagged here reads correctly on a Prusa printer or any
  other OPT-aware reader, and a genuine vendor-tagged spool (Prusament,
  eSun, etc.) is recognized and adopted automatically the first time it's
  weighed, no manual entry required.
- **Nothing leaves the device.** Inventory, usage history, and popularity
  analytics all live in on-board flash. There's no account to create, no
  internet dependency for day-to-day use, and no third-party service that
  can shut down or change its pricing under you.
- **It's built for a shared shop, not a single desk.** Multiple people use
  it over months without administration: a shelf audit workflow reconciles
  "what's on the shelf" against the log without anyone hand-editing
  records, and a reorder page tells whoever's ordering supplies what's
  actually running low, weighted by real consumption, not by "we think
  we're out."

It is **not** a general-purpose postal scale, and it's tuned for spools in
roughly the 0–5 kg range on a fixed platform — see the Bill of Materials
for the exact load cell rating.

This is a from-scratch electromechanical build: expect a few hours of
printing (several parts, some multi-hour), an evening of soldering and
wiring, and an hour or so of flashing and bring-up. None of the steps are
hard on their own; there are just several of them.

## 2. What you'll need

**Skills:** comfortable soldering small-gauge wire, running a slicer and a
3D printer, and following a PlatformIO/Arduino-style flashing workflow. No
firmware-writing skill is required to *build* one — the firmware is
already written; you're flashing it as-is.

**Tools** (from [`hardware/bill-of-materials.md`](../hardware/bill-of-materials.md)):

- Soldering iron — for heat-set insert installation *and* the wiring splices
- 2.5mm and 3mm hex keys (M3/M4 SHCS), 4mm hex key (M5 SHCS)
- Digital calipers
- A 3D printer with a bed at least 210×210mm (the platform disc is Ø205mm)
- A phone or laptop on the same WiFi as the finished station, for setup
- NFC Tools app (NDEF tag formatting) + NFC.cool Tools (tag testing) — for
  formatting/testing blank NFC tags, separate from the station's own
  onboarding flow
- A known-mass reference weight (anything from a calibrated gym plate to a
  bag of sugar you've weighed elsewhere) — needed once, to calibrate the
  scale in step 7

## 3. Parts & sourcing

Full list with specs and notes:
[`hardware/bill-of-materials.md`](../hardware/bill-of-materials.md). Fastener
sizes and quantities (heat-set inserts, screws, washers, nuts):
[`hardware/fastener-schedule.md`](../hardware/fastener-schedule.md).

The short version — five things worth reading the notes on *before* you
order, because getting them wrong is either expensive or hard to diagnose
later:

- **PN5180 NFC reader:** needs both a 3.3V logic supply *and* a separate
  5V feed to its RF/antenna-driver pin. Cheap breakout listings sometimes
  only call out the 3.3V logic rail — check yours has a 5V pin broken out,
  or the reader will look alive over SPI but never actually read a tag.
- **TFT display:** a 3.5" ILI9488 SPI panel, 480×320 (Hosyond/MSP3520-type
  in the BOM). Get the **SPI** version, not an 8-bit parallel one — the
  firmware's display driver is configured for SPI.
- **Load cell:** TAL220B, 5kg rating, ~40mm bolt spacing. A different
  capacity works fine (swap the calibration factor in step 7); a different
  bolt pattern means adjusting the mounting boss in the SCAD.
- **USB-C:** the ESP32-S3 board's *native* USB-C is the only port this
  design uses — for power, serial console, and flashing. No separate power
  input or USB bridge chip to source.
- **NFC tags:** genuine OpenPrintTag MK1 stickers, sourced directly from
  Prusa — the format's own creator/promoter — are what this project
  actually uses: [Blank OpenPrintTag, 10-pack](https://www.prusa3d.com/product/blank-openprinttag-10-nfc-tags/)
  from Prusa's own store, or the same product from
  [Printed Solid](https://www.printedsolid.com/products/original-prusa-blank-openprinttag-10-nfc-tags),
  Prusa's official US distributor (acquired by Prusa Research in 2022; US
  warehouse in Delaware) if you'd rather order domestically. See
  `docs/user-manual.md` for how they're applied to a spool. If you'd
  rather source your own, any blank ISO15693 (ICODE SLIX2-compatible) tag
  works too — the station formats
  a blank tag automatically the first time you place one (see step 7), so
  nothing needs pre-formatting, but it must be ISO15693, not NTAG/MIFARE.

## 4. Printing the parts

Printed parts, by module in [`hardware/weighstation.scad`](../hardware/weighstation.scad)
plus the standalone [`hardware/porch-tft-faceplate.scad`](../hardware/porch-tft-faceplate.scad):

| Part | Material | Orientation | Notes |
|---|---|---|---|
| Base | PETG | as modeled | 4 walls, 40% infill near the load-cell boss — this is the structural part carrying weighing load |
| Deck | PETG or PLA | face-down | drop-in top plate, no supports |
| Platform | PLA | face-down | Ø205mm disc — confirm it fits your bed with margin |
| Spigot | PLA | as modeled | centering cone |
| Tray | PETG or PLA | as modeled | carries the ESP32 + NAU7802 |
| Porch display faceplate | PETG | face-down | thin retainer plate, no supports |

Rendering each part: `weighstation.scad` picks which module to export off a
top-level `part` variable (`assembly` by default — the full preview).
Override it from the command line, **keeping the inner double-quotes
intact** — dropping them passes an unquoted bareword that OpenSCAD's `-D`
parser doesn't accept as a string, which hangs rather than erroring
cleanly:

```
# macOS/Linux/Git-Bash — wrap the whole thing in single quotes
openscad -D 'part="base"' --render -o base.stl hardware/weighstation.scad

# Windows cmd.exe — escape the inner quotes instead
openscad -D "part=\"base\"" --render -o base.stl hardware\weighstation.scad
```

Valid values: `base`, `deck`, `platform`, `spigot`, `tray`. The standalone
`porch-tft-faceplate.scad` has no `part` switch — it only ever exports the
one plate, so render it directly with no `-D` needed.

**Before you print:** check
[`hardware/printed-parts-issues.md`](../hardware/printed-parts-issues.md)
for known errata — some entries there are closed *without* being
print-validated on hardware (the current prototype predates them and
wasn't reprinted to confirm), so if you hit a fit problem matching one of
those descriptions, that file has the context and the exact SCAD variables
involved.

**Heat-set inserts:** installed from above with a soldering iron, after
printing — see the fastener schedule for sizes (mostly M3, one M4, one
M5) and locations. Let the part cool fully before handling; a warm insert
can pull back out.

**Print envelope:** the platform (Ø205mm) is the tightest fit — it needs a
bed with at least 210mm of clearance in one direction. The base footprint
is 200×140×60mm.

## 5. Wiring

Full pin-by-pin netlist, wiring diagram, and every gotcha that's bitten a
prior build: [`hardware/netlist.md`](../hardware/netlist.md).

This guide assumes **point-to-point wiring** — solder (or crimp) each
connection directly, no custom PCB. If you want to get fancier (a
perfboard bus for the shared SPI/power/ground splices, or a breakout
board), the netlist's "Rails with many legs" note covers that option; it's
not required.

Read the netlist's **Cautions** section before you start soldering — three
mistakes there are easy to make and each one produces a confusing symptom
rather than an obvious failure:

- **PN5180 needs both 3.3V (logic) and 5V (RF driver) wired.** Skipping
  the 5V leg makes the reader answer SPI commands but never actually see a
  tag — it looks alive, it just can't read anything.
- **Never wire the display's SDO pin to the shared MISO line.** The
  ILI9488 panel's SDO doesn't tri-state, so it will permanently drive
  MISO low and the NFC reader will appear completely dead while the
  display works fine. Leave that pin unconnected.
- **PN5180 and TFT share MOSI and SCK, never MISO** — this is handled in
  firmware (`src/spi_bus.cpp`), not at the bench, but it's why this looks
  like an ordinary shared SPI bus and isn't quite one.

The **shared nets** (MOSI, SCK, MISO, 3V3, GND) each get one soldered
splice near the controller, not multiple wires stacked on one pin — see
the netlist's splice table for exactly which legs join at each one, and
its soldering technique notes (thread the heat-shrink on *before* you
solder, stagger the splices, keep them near the MCU).

Leave a **slack loop** in the wiring between the load-cell platform and the
controller — a taut harness transmits its own tension into the load cell
and corrupts every reading.

## 6. Flashing the firmware

**Recommended: flash a pre-built release.** No PlatformIO, no cloning the
repo, no build toolchain — just a serial-port tool and four downloaded
files. This is the right choice unless you're modifying the firmware
itself.

1. Install [esptool](https://github.com/espressif/esptool): `pip install esptool`.
2. Download the four `.bin` files from the
   [latest release](https://github.com/NormSohl/openprinttag-weigh-station/releases/latest)
   into one folder: `bootloader.bin`, `partitions.bin`, `boot_app0.bin`,
   `firmware.bin`.
3. Plug the board in over USB-C.
4. **First flash on a fresh board:** hold **BOOT**, tap **RESET**, release
   **BOOT**, *then* run the command below — the S3's native USB won't
   present a bootloader otherwise. Every flash after that auto-resets on
   its own.
5. From that folder, run (swap `<PORT>` for the board's serial port —
   `pio device list`, Windows Device Manager, or `ls /dev/tty.usbmodem*`
   on macOS):

   ```
   esptool.py --chip esp32s3 --port <PORT> --baud 921600 write_flash -z \
     --flash_mode dio --flash_freq 80m --flash_size 4MB \
     0x0000 bootloader.bin \
     0x8000 partitions.bin \
     0xe000 boot_app0.bin \
     0x10000 firmware.bin
   ```

This writes only the firmware and partition table — it doesn't touch the
event log, config catalog, WiFi credentials, or scale calibration, since
those all live in LittleFS/NVS regions this command doesn't address. There
is no separate filesystem image to flash: config tables seed themselves on
first boot and the web UI is built into the firmware image.

**Building from source instead** — only needed if you're modifying the
firmware, or a release for your board revision doesn't exist yet. Full
setup/build/flash walkthrough, including what a healthy boot log looks
like: [`DEVELOPMENT.md`](../DEVELOPMENT.md). Short version once the tools
are installed:

1. `git clone` this repo, open the folder in VS Code with the PlatformIO
   extension.
2. Plug the board in over USB-C.
3. **First flash only:** same BOOT/RESET dance as above, *then* upload.
4. Click **Upload** (or `pio run -t upload`).

## 7. Testing your build

Run through this once, in order, before putting the station into service —
this checklist is the same whether you flashed a downloaded release or
built from source. Each step below depends on the previous one succeeding.

1. **Power on.** The TFT should light up and show a WiFi-setup screen —
   that alone confirms the board booted and the display is wired
   correctly. Watching the boot log over serial is optional but catches
   problems earlier and more specifically (a missing line points at
   exactly which subsystem didn't start — see the "healthy boot" example
   in `DEVELOPMENT.md`); any 115200-baud serial terminal works, no
   PlatformIO required — `python -m serial.tools.miniterm <PORT> 115200`
   (pyserial ships with esptool, so nothing extra to install) or
   `pio device monitor -b 115200` if you already have PlatformIO from a
   source build.
2. **Join it to WiFi.** On first boot it opens a `WeighStation-Setup`
   access point — connect to it from your phone and enter your lab's
   WiFi. It then reboots and joins as `weighstation.local`. If it can't
   reach your network within the setup window, it falls back to its own
   `WeighStation` access point instead — the idle screen tells you which
   state it's in.
3. **Open the web app** at the address shown on the idle screen (or scan
   the QR code it displays).
4. **Calibrate the scale**, Calibrate page: *Zero* with nothing on the
   platform, then *Set calibration* with your known-mass reference weight,
   entering its actual grams. The "not calibrated" banner on the idle
   screen should clear.
5. **Format and onboard a blank NFC tag.** Place a blank tag on the
   reader: the display should show a countdown ("New tag — remove to
   cancel"); leave it in place and it formats the tag and creates a stub
   spool record automatically. Fill in the material details on the
   **Onboard** page it points you to.
6. **Weigh it.** Remove and replace the spool — the display should show
   its spool number, material, and remaining weight, and the reading
   should show up on the web app's Inventory page.
7. **Confirm the round trip.** Edit that spool's detail on the web app
   (change the tare, say), then place the spool back on the scale — the
   physical tag should get rewritten with the new data on the next
   placement. This proves tag reads, tag writes, and the store are all
   actually talking to each other, not just individually alive.

If every step above passes, the station is ready for day-to-day use.

## 8. Operating it

Once it's built, calibrated, and confirmed working, day-to-day use — for
both regular members and whoever administers it — is covered in
[`docs/user-manual.md`](./user-manual.md). That's the doc to hand to
someone who didn't build the thing and just needs to use it.

## 9. Troubleshooting

Symptoms you might hit during bring-up, and where the root cause usually
is:

| Symptom | Likely cause |
|---|---|
| NFC reader never detects any tag, but SPI/boot looks fine | PN5180's 5V (RF driver) line isn't connected — 3.3V alone runs the logic but not the antenna field |
| Display works, but the NFC reader seems dead | Display's SDO pin is wired into the shared MISO line — disconnect it, the panel doesn't need it |
| Serial monitor is blank after a successful upload | ESP32-S3 native-USB CDC quirk — add `-DARDUINO_USB_CDC_ON_BOOT=1` to `build_flags` in `platformio.ini` |
| Upload fails / board not found | Needs a manual entry into download mode: hold **BOOT**, tap **RESET**, release **BOOT**, then upload |
| Scale reading is noisy or drifts under a placed spool | Check for a taut wiring harness between the platform and the controller — it needs slack |
| Web app unreachable after WiFi setup | Check the idle screen — it shows whether the station joined your network or fell back to its own `WeighStation` access point |
| A printed part doesn't fit as expected | Check `hardware/printed-parts-issues.md` first — several fit issues are already documented with the exact SCAD variables involved |

For anything not covered here, the deep-dive design notes and hardware
gotchas are in [`CLAUDE.md`](../CLAUDE.md) at the repo root, and issues can
be filed against this repository.

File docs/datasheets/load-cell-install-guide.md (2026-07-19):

# Load Cell — Installation & Wiring Guide (translated)

English translation of the Chinese installation sheet that shipped with
the strain-gauge weight sensor (load cell). This is the sensor that feeds
the NAU7802 ADC in the weigh station.

**Source:** [`load-cell-install-guide.jpeg`](./load-cell-install-guide.jpeg)
(original Chinese single-sheet insert, title **安装必看** — "Read Before
Installing").

**See also:** [`hardware/netlist.md`](../../hardware/netlist.md) — the
load-cell section carries the condensed wire-color-to-terminal table.

> Translation notes: the original is a general-purpose insert covering
> both half-bridge and full-bridge cells and several mounting layouts.
> Only the full-bridge wiring and single-beam mounting apply to this
> project; the rest is included for completeness.

---

## Installation (安装操作)

- Mount the sensor exactly per the orientation diagram. The **force
  direction must be perpendicular to the horizontal plane** — load must
  push straight down onto the cell.
- Wire strictly according to the wiring diagram. **Solder every
  connection point with a soldering iron.**
- ⚠️ *Do not join the sensor leads by twisting or knotting them — this
  makes the sensor signal unstable.*

## Avoid stress damage (避免应力损伤)

- Handle small/low-capacity sensors gently; avoid excessive force or
  drops/impacts. Protect the cell from overload during handling and use.

## Calibration & setup (校准与调试)

- After **installing or replacing** a sensor, recalibrate.
- Follow your readout meter's calibration procedure.
- Calibrate with a known weight in the **50–80 % of rated range** band
  (large cells: not less than ⅓ of rated range).

> In this project that maps directly to the serial workflow: run `ZERO`
> with nothing on the scale, then `CAL <grams>` with a reference weight
> in the 50–80 % band. See the "Scale calibration" section of
> `CLAUDE.md`.

---

## Wiring — full-bridge load cell (全桥称重传感器接线方法)

4 signal wires + optional shield. This is the configuration used in this
project (single full-bridge cell → NAU7802).

| Wire color | Function | Cell terminal | → NAU7802 |
|---|---|---|---|
| Red (红) | Excitation + | **E+** | EX+ / AVDD side  |
| Black (黑) | Excitation − | **E−** | EX− / AGND side  |
| Green (绿) | Signal + | **A+ / S+** | VIN+ |
| White (白) | Signal − | **A− / S−** | VIN− |
| Yellow (黄)  | Shield / drain | **GND** | ground |

> Note from the sheet: *if the full-bridge 4-wire cell has no yellow
> wire, no separate ground connection is needed.*

## Wiring — half-bridge load cell (半桥称重传感器接线方法)

Shown on the sheet for reference (3-wire, multiple cells A/B/C combined
into a bridge). **Not used in this project** — included only to document
the original insert.

Terminals: `S+`, `E+`, `E−`, `S−` with red / black / white leads.

---

## Mounting (安装结构示意图)

### Single parallel-beam cell (平行梁传感器)

- One end is the **fixed end** (bolted to the base plate), the other is
  the **load / force end** (carries the platform).
- Use a **spacer block** so the beam can deflect freely.
- Hardware per the diagram: top plate ×1, bottom plate ×1, spacer ×1,
  screws ×4.
- **Wire-exit end** faces away from the load.

### Four-cell platform (四个传感器)

- Keep **all four corners level**; the four sensor support points define
  the weighing-pan center.
- ⚠️ *The sensor's sealed / glued (potted) face points **down**; this
  gives a **positive** output.*

---

## Manufacturer contact

Printed on the sheet: **Manager Li (李经理), +86 153 9970 8396** (same
number on WeChat). For questions about using the sensor.

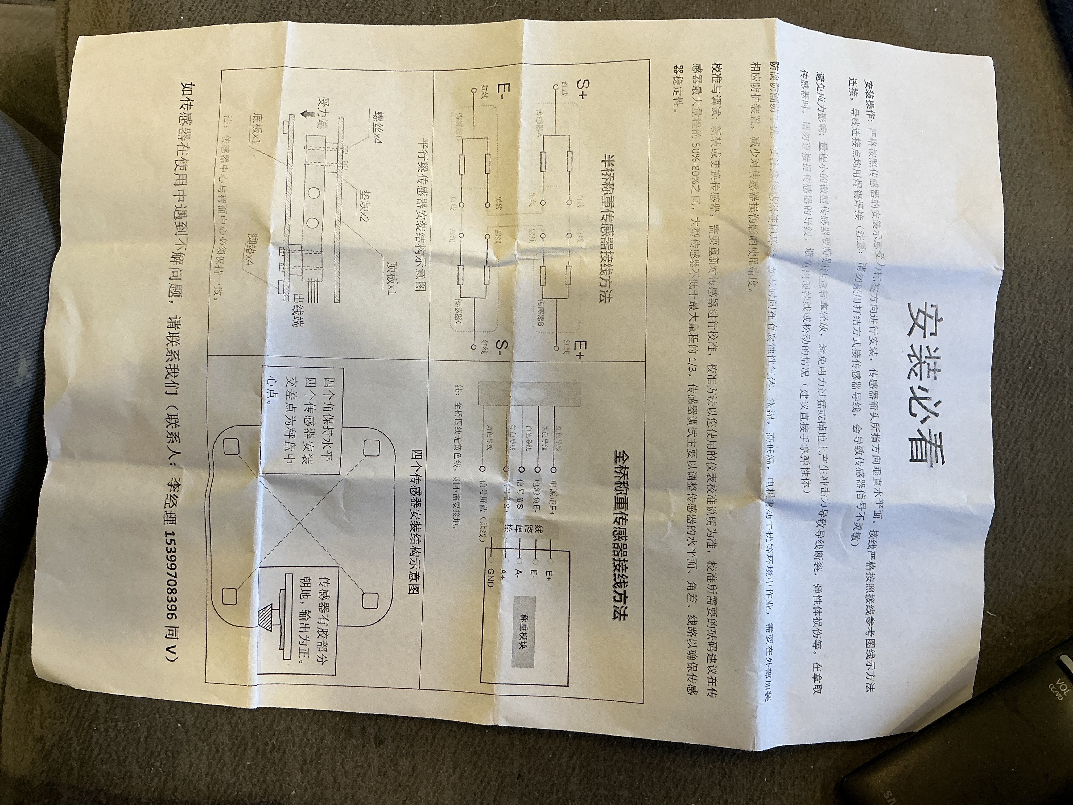
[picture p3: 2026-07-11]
docs/datasheets/load-cell-install-guide.jpeg

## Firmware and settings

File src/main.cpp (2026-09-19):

// SPDX-License-Identifier: GPL-3.0-or-later
// Copyright (C) 2026 Norm Sohl

#include <Arduino.h>
#include <Wire.h>
#include <SPI.h>
#include "config.h"
#include "device_state.h"
#include "opt_tag.h"
#include "store.h"          // local-storage core (redesign Phase 1)
#include "config_store.h"   // config catalog (redesign Phase 3)
#include "api_key.h"        // shared secret for mutating HTTP endpoints
#include "display_tz.h"     // display-only local timezone (TFT clock, web app)
#include "station_name.h"   // Idle screen's configurable greeting
#include "last_onboard.h"   // Onboard page's remembered last vendor/material/color/profile
#include "last_stock.h"     // Stock List page's remembered last vendor/material/color
#include "controller.h"     // single owner of the WiFi/idle gState group

// ── Shared state ──────────────────────────────────────────────
// Tasks read/write gState under gStateMutex.
volatile DeviceState gState       = DeviceState::Boot;
SemaphoreHandle_t    gStateMutex  = nullptr;

// Latest weight from scaleTask, consumed by syncTask and displayTask.
volatile float    gWeightGrams  = 0.0f;
SemaphoreHandle_t gWeightMutex  = nullptr;

// False until a real calibration is stored. displayTask shows an idle-screen
// "not calibrated" banner while false, so the uncalibrated first boot isn't silent.
volatile bool     gScaleCalibrated = false;

// Calibration requests from the web UI (or serial), consumed by scaleTask.
volatile bool     gCalZeroReq  = false;   // tare with an empty scale
volatile float    gCalSetGrams = 0.0f;    // >0: calibrate against this known weight

// ── Shared tag data (written by nfcTask, read by syncTask / displayTask) ──────
uint8_t           gTagUid[8]    = {};
OptMeta           gTagMeta      = {};
OptMain           gTagMain      = {};
OptAuxiliary      gTagAux       = {};
SemaphoreHandle_t gTagMutex     = nullptr;

// Write-back requests: syncTask sets these flags; nfcTask clears them after writing.
volatile bool gWriteMainPending = false;
volatile bool gWriteAuxPending  = false;

// Set by the TAGFORMAT serial command, consumed by nfcTask: reformat whatever
// tag is present regardless of how it classifies. Recovery for a tag left
// half-written by a format that failed partway — those stop reading as blank
// and stop decoding, so nothing else can get them back.
volatile bool gTagForceFormat = false;

// Set by the web /erase page's Start/Stop buttons. While true, nfcTask
// erases any freshly placed tag immediately -- no countdown, same as a
// forced TAGFORMAT -- and syncTask retires whatever spool that physical
// chip previously carried without minting a new stub. See nfc_task.cpp's
// classification check and sync_task.cpp's Resolving phase. Deliberately a
// persistent mode, not a one-shot per-tag arm: the whole point is processing
// a bin of tags back to back with no per-tag step.
//
// Nothing about this mode requires a browser tab to stay open or focused --
// it is a server-side flag, so the real risk is not "the tab changed," it's
// "a person walked away from the physical station and left it armed." A
// tab-visibility check would not catch that at all. gEraseModeActivityMs
// instead tracks wall-clock time since the mode was turned on or last
// actually erased a tag; nfc_task.cpp's idle (Waiting) loop auto-clears
// gEraseModeActive after ERASE_MODE_IDLE_TIMEOUT_SEC of no activity, on
// direct user request after a live test raised exactly this concern.
volatile bool     gEraseModeActive     = false;
volatile uint32_t gEraseModeActivityMs = 0;

// SPI bus mutex — nfcTask (Core 1) and displayTask (Core 0) share the bus.
// Both tasks must take this mutex before any SPI transaction.
SemaphoreHandle_t gSpiMutex = nullptr;

// Local spool ID for the tag currently on the scale (-1 = none / unknown).
// Set by syncTask; read by displayTask for the "Spool #N" line.
volatile int  gSpoolId             = -1;
// True while the spool's local record still has needs_onboarding=true.
// Drives the "Registered! add details in web app" display variant.
volatile bool gSpoolNeedsOnboarding = false;

// Web-UI reachability, set by syncTask once the network is up and shown on the
// idle screen so anyone can find the app. gApSsid is non-empty only in SoftAP
// fallback (join that SSID, then browse to gWebAddr).
char gWebAddr[48] = {};
char gApSsid[24]  = {};

// Seconds left before the captive portal gives up; -1 when no portal is running.
//
// The portal is a TIMED window and nothing said so. Carried to a new location,
// the unit opened it, waited two minutes with nobody looking, closed it, and
// fell back to its own AP — which looks from the outside like it simply never
// offered to be configured. Written by syncTask's portal loop, shown by
// displayTask.
volatile int gPortalSecsLeft = -1;

// True once SNTP has given us a real date. Until then every event is stamped
// 1970 and its consumption is filed as "unknown" rather than as January 1970 —
// see periodOf_() in store.cpp. Surfaced on /api/status and LOGSTATS so
// "the clock never set" is a visible condition rather than a puzzle found in
// the Usage page a month later.
volatile bool gClockSet = false;

// Task handles, kept so the STACK serial command can report each task's
// high-water mark. Stack overflow has been this project's characteristic
// failure — scaleTask blew its canary on the first SEED, and the symptom is a
// reboot loop with no useful backtrace — so "how much headroom is left" needs
// to be an answerable question rather than something guessed at after the fact.
TaskHandle_t gNfcTask = nullptr, gScaleTask = nullptr,
             gDisplayTask = nullptr, gSyncTask = nullptr,
             gControllerTask = nullptr;

// ── Task forward declarations (defined in their own .cpp files) ──
void nfcTask(void* param);
void scaleTask(void* param);
void displayTask(void* param);
void syncTask(void* param);

// Display/NeoPixel/buzzer hardware init — run on the main task before any task
// starts, so TFT_eSPI and the PN5180 library can't initialise the shared SPI
// bus concurrently from two cores. See displayBegin() in display_task.cpp.
void displayBegin();

// Boot progress marker. Each init step announces itself BEFORE it runs, so if
// the board hangs the last line printed names the culprit. Flushed immediately
// because a hang would otherwise leave the message sitting in the USB buffer.
static void bootMark(const char* step) {
    Serial.printf("[boot] %s\n", step);
    Serial.flush();
}

void setup() {
    Serial.begin(115200);
    // Native USB (USB-Serial/JTAG on this board): the host re-enumerates after
    // the post-flash reset and a monitor typically attaches ~1-2 s in, so
    // anything printed before that is lost. Hold here so the first boot is
    // actually observable — the cost is 3 s on a device that runs for months.
    delay(3000);
    Serial.println();
    Serial.println("=== weigh station boot ===");
    Serial.printf("[boot] build %s\n", BUILD_VERSION);

    bootMark("i2c (Wire.begin)");
    Wire.begin(I2C_SDA, I2C_SCL);

    // Starts the PN5180's peripheral (SPI2) and gives it GPIO 11/12/13.
    // displayBegin() later hands the same two output pins to the display's
    // peripheral (SPI3) — the S3 lets only one peripheral drive a pin, so from
    // then on ownership is arbitrated per-transaction by spi_bus.cpp. This call
    // just has to happen first so SPI.bus() is a valid handle to route to.
    bootMark("spi (shared PN5180 + TFT bus)");
    SPI.begin(SPI_SCK, SPI_MISO, SPI_MOSI);

    bootMark("mutexes");
    gStateMutex = xSemaphoreCreateMutex();
    gWeightMutex = xSemaphoreCreateMutex();
    gTagMutex = xSemaphoreCreateMutex();
    gSpiMutex = xSemaphoreCreateMutex();
    // Must exist before nfcTask/syncTask start posting WiFi/idle events to it.
    gCtrlQueue = xQueueCreate(8, sizeof(CtrlEvent));

    // Local-storage core (LittleFS log + indices + NVS counter). Headless in
    // Phase 1 — driven via the serial harness (EV / DUMP / REBUILD / …).
    // First boot after an erase formats the FS partition — expect a pause here.
    bootMark("store (mount/format LittleFS + NVS)");
    if (storeBegin())
        Serial.printf("[store] ready: %u spools, %u log lines, next id #%u\n",
                      (unsigned)storeSpoolCount(), (unsigned)storeLogLineCount(),
                      (unsigned)storePeekSpoolId());
    else
        Serial.println("[store] LittleFS mount FAILED");

    // Config catalog (vendors/materials/profiles/colors/stock-items on LittleFS).
    bootMark("config catalog (seeds on first boot)");
    cfgBegin();
    Serial.printf("[cfg] ready: %u vendors, %u materials, %u profiles, %u colors, %u stock\n",
                  (unsigned)cfgVendorCount(), (unsigned)cfgMaterialCount(),
                  (unsigned)cfgProfileCount(), (unsigned)cfgColorCount(),
                  (unsigned)cfgStockCount());

    apiKeyBegin();
    Serial.printf("[api] write endpoints are %s\n",
                  apiKeyIsSet() ? "protected by an API key"
                                : "UNPROTECTED (no key set — see APIKEY over serial)");

    // Independent of WiFi/NTP: tzset() only affects how localtime_r() later
    // INTERPRETS whatever the clock is, real or boot-relative, so this is
    // safe to apply before the clock is even set. syncTask re-applies it
    // after every configTime() call too, in case that call's own internal
    // setenv("TZ", ...) stomps it.
    tzBegin();
    Serial.printf("[tz] display timezone: %s\n", tzGetId());

    stationNameBegin();
    Serial.printf("[station] name: %s\n", stationNameGet());

    lastOnboardBegin();
    lastStockBegin();

    Serial.printf("[store] filesystem: %u kB free / %u kB\n",
                  (unsigned)(storeFreeBytes() >> 10), (unsigned)(storeTotalBytes() >> 10));

    // Display first, on this task, while nothing else can touch the SPI bus.
    bootMark("display init (TFT + NeoPixel + buzzer)");
    displayBegin();
    // TFT_eSPI asks the HAL for "no MISO" (TFT_MISO is -1 because the ILI9488's
    // SDO never tri-states), and the S3 HAL has no default MISO pin for HSPI to
    // fall back on, so it logs an error and returns — which is exactly what we
    // want it to do. Say so, because an unexplained [E] in a boot log sends the
    // next person debugging in the wrong direction.
    Serial.println("[display] the 'HSPI Does not have default pins' error above "
                   "is expected — the display is write-only by design");
    bootMark("display ok");

    // Core 1: time-sensitive hardware polling
    bootMark("starting nfcTask (PN5180)");
    xTaskCreatePinnedToCore(nfcTask,     "nfc",     6144, nullptr, 2, &gNfcTask, 1);
    bootMark("starting scaleTask (NAU7802)");
    // 8192, not 3072: the serial harness runs on this task, and SEED / COMPACT /
    // DUMP call into the store. storeAppendEvent -> FS::open -> lfs_dir_fetchmatch
    // -> esp_flash_read is a deep chain on top of the String and JSON work, and
    // 3072 overflowed the stack canary on the first SEED.
    xTaskCreatePinnedToCore(scaleTask,   "scale",   8192, nullptr, 2, &gScaleTask, 1);

    // Core 0: I/O — co-located with the WiFi stack
    bootMark("starting displayTask (TFT)");
    // 6144, not 4096: drawQr() calls into ricmoo's encoder, which builds its
    // working buffers as C99 variable-length arrays on the CALLER'S stack —
    // codewordBytes[101] + isFunctionGridBytes[137] in qrcode_initBytes(), and
    // another result[101] + coeff[20] nested inside performErrorCorrection().
    // That is ~600 bytes of transient on top of the TFT call frames, on a task
    // that used to do nothing deeper than fillRect. scaleTask already cost us
    // one canary panic for exactly this kind of hidden depth.
    xTaskCreatePinnedToCore(displayTask, "display", 6144, nullptr, 1, &gDisplayTask, 0);
    // Single owner of the WiFi/idle gState group. Priority 2 (above display/sync)
    // so an event turns into a state change promptly. No store or SPI — a small
    // stack is enough for setState + the optional trace printf.
    bootMark("starting controllerTask (owns WiFi/idle state)");
    xTaskCreatePinnedToCore(controllerTask, "ctrl", 3072, nullptr, 2, &gControllerTask, 0);
    bootMark("starting syncTask (WiFi + web)");
    xTaskCreatePinnedToCore(syncTask,    "sync",    8192, nullptr, 1, &gSyncTask, 0);

    bootMark("setup() complete — tasks running");
}

void loop() {
    vTaskDelay(portMAX_DELAY);  // all work happens in FreeRTOS tasks
}

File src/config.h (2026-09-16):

// SPDX-License-Identifier: GPL-3.0-or-later
// Copyright (C) 2026 Norm Sohl

#pragma once

// ── PN5180 SPI ────────────────────────────────────────────────
// Adjust to match your actual wiring.
#define PN5180_NSS    5
#define PN5180_BUSY   6
#define PN5180_RESET  7

// SparkFun Thing Plus ESP32-S3 default SPI pins (board silk: 12/SCK, 11/PICO,
// 13/POCI). GPIO 33-37 are NOT broken out on this board (module flash/PSRAM).
#define SPI_SCK   12
#define SPI_MISO  13
#define SPI_MOSI  11

// ── I²C / Qwiic (NAU7802) ────────────────────────────────────
#define I2C_SDA  8
#define I2C_SCL  9

// ── 3.5" ILI9488 SPI TFT display ─────────────────────────────
// Shares MOSI/SCK with the PN5180, on a DIFFERENT SPI peripheral — see
// spi_bus.h. Take the bus via spiBusTakeTft(), never gSpiMutex directly.
// TFT_CS/TFT_DC/TFT_RST are also passed to TFT_eSPI as -D flags (platformio.ini).
#define TFT_CS   15
#define TFT_DC   16
#define TFT_RST  17

// Landscape orientation. 1 and 3 are both landscape, 180° apart — which one
// reads right-way-up depends purely on how the panel sits in the mount, not on
// the panel itself. Confirmed on the assembled unit: 1 is correct.
// (Set once at init from this constant, so it cannot vary between boots of the
// same binary — a flip across a reboot means the panel moved, not the code.)
#define TFT_ROTATION 1

// ── WS2812 NeoPixel (onboard) ────────────────────────────────
// The external porch NeoPixel is superseded by the TFT display.
// SparkFun Thing Plus ESP32-S3 onboard RGB is GPIO46 (GPIO48 is the onboard
// SD card-detect on this board, not the LED).
#define NEOPIXEL_PIN     46
#define NEOPIXEL_COUNT    1

// ── Passive piezo buzzer ──────────────────────────────────────
#define BUZZER_PIN  14

// ── WiFi reset trigger ────────────────────────────────────────
// Hold the BOOT button (GPIO 0, already on the SparkFun Thing Plus ESP32-S3
// board) for this many milliseconds at power-on to erase stored WiFi
// credentials and force the captive portal to reopen.
#define WIFI_RESET_PIN      0
#define WIFI_RESET_HOLD_MS  3000

// Captive-portal exit policy (enforced in syncTask, not by WiFiManager).
// Two independent limits, because the device is cabinet-installed and the BOOT
// button is inside the case — the portal must always close on its own.
//
//   IDLE: no client associated to the AP. Nobody is setting it up, so fall back
//         to the SoftAP quickly and get the web app reachable.
//   MAX:  absolute cap regardless of clients. Covers the case where someone
//         joins, wanders off, and leaves a phone associated — without this the
//         portal would stay open forever with no way to escape.
#define WIFI_PORTAL_TIMEOUT_SEC 120   // idle: nobody joined
#define WIFI_PORTAL_MAX_SEC     600   // absolute: 10 min, then give up

// ── Web interface ─────────────────────────────────────────────
// mDNS hostname; device is reachable at http://<DEVICE_HOSTNAME>.local/
// The /reset endpoint clears WiFi credentials and reboots into the portal.
#define DEVICE_HOSTNAME  "weighstation"

// Reported by GET /api/status so a fleet dashboard can tell builds apart.
// NB: deliberately NOT called FIRMWARE_VERSION — the PN5180 library uses
// that name for a chip EEPROM register address.
#define FW_VERSION       "1.0.0"

// git describe (tag-commits-hash[-dirty]) at build time, set by
// scripts/pre_build_version.py -- answers "which commit is actually flashed
// on this unit", which FW_VERSION above doesn't (hand-maintained, hasn't
// moved since 1.0.0). Guarded in case anything ever compiles against this
// header outside the PlatformIO env that runs the script (e.g. tools/store's
// native shim build, which doesn't include config.h's owner main.cpp/
// web_app.cpp anyway, but costs nothing to guard).
#ifndef BUILD_VERSION
#define BUILD_VERSION "unknown"
#endif
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

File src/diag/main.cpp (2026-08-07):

// Shared-SPI-bus test — build with:  pio run -e diag -t upload -t monitor
//
// WHAT CAME BEFORE
// Bring-up hit two independent faults on the shared PN5180 + TFT bus, and
// fixing either alone still left the reader dead:
//
//   1. The ILI9488's SDO does not tri-state when its CS is high, and the
//      netlist wired it into the MISO splice. The panel drove MISO
//      permanently, so every PN5180 reply read back as 0x00.
//      Fixed in hardware (SDO off the splice) and in config (TFT_MISO=-1).
//
//   2. The display sits on SPI3 and the PN5180 on SPI2, yet both drive GPIO
//      11/12. spiAttachSCK() ends in pinMatrixOutAttach(), a write to the pin's
//      single-valued func_out_sel register, so the last attach wins silently.
//      displayBegin() runs after SPI.begin(), so the display took the pins and
//      the PN5180 never saw a clock edge.
//
//      Neither device can move. TFT_eSPI's S3 port resolves REG_SPI_BASE() to
//      DR_REG_SPI3_BASE for every legal SPI_PORT value, so its register writes
//      always hit SPI3 — building without USE_HSPI_PORT just makes the Arduino
//      layer drive SPI2 while those writes still go to SPI3, which panics.
//      The PN5180 library hardcodes the global `SPI` (SPI2). So the fix is to
//      re-point the pins on every handoff, which is what claimNfc/claimTft
//      below do — the same thing src/spi_bus.cpp does for the real firmware.
//
// A PN5180-only diag proved (1) — it read a tag UID with the display unlinked.
// It could not test (2) at all, because it had no display.
//
// WHAT THIS TESTS
// Both devices, both drivers, one bus — the exact contention the real firmware
// creates, with none of the application code. The display is initialised FIRST
// (as displayBegin() does), then the PN5180, then both run concurrently: tag
// polling on loop() with a display repaint on every pass.
//
//   both work            -> the handoff is correct; the real firmware should
//                           behave identically.
//   display blank/frozen -> the TFT lost the pins. Bus config, not app code.
//   NFC silent           -> the PN5180 lost the pins (or reset() hangs again).
//   TFT panic in
//   begin_tft_write()    -> the null bus-handle crash is back; SPI.begin()
//                           must run before tft.init().
//
// Whichever half fails, it fails here without the app in the way.

#include <Arduino.h>
#include <SPI.h>
#include <esp32-hal-spi.h>
#include <TFT_eSPI.h>
#include <PN5180.h>
#include <PN5180ISO15693.h>
#include "../config.h"

#define DIAG_LED 46   // onboard WS2812

static PN5180ISO15693 nfc(PN5180_NSS, PN5180_BUSY, PN5180_RESET);
static TFT_eSPI       tft;

// Pin-ownership handoff, the single-threaded twin of src/spi_bus.cpp. No mutex
// needed here — this sketch has one thread — but the routing is identical.
static void claimNfc() {
    spi_t* bus = SPI.bus();
    if (!bus) return;
    spiAttachSCK(bus, SPI_SCK);
    spiAttachMOSI(bus, SPI_MOSI);
    spiAttachMISO(bus, SPI_MISO);
}
static void claimTft() {
    spi_t* bus = TFT_eSPI::getSPIinstance().bus();
    if (!bus) return;
    spiAttachSCK(bus, SPI_SCK);
    spiAttachMOSI(bus, SPI_MOSI);
}

static uint32_t sTagCount = 0;
static uint32_t sPollCount = 0;
static char     sLastUid[24] = "(none yet)";

static void drawScreen(const char* status, uint16_t colour) {
    claimTft();
    tft.fillScreen(TFT_BLACK);
    tft.setTextColor(TFT_WHITE, TFT_BLACK);
    tft.setTextDatum(TL_DATUM);

    tft.drawString("SHARED BUS DIAG", 10, 10, 4);
    tft.drawFastHLine(10, 40, 460, TFT_DARKGREY);

    tft.setTextColor(colour, TFT_BLACK);
    tft.drawString(status, 10, 55, 4);

    tft.setTextColor(TFT_WHITE, TFT_BLACK);
    tft.drawString(String("uid:   ") + sLastUid, 10, 100, 2);
    tft.drawString(String("tags:  ") + sTagCount, 10, 125, 2);
    tft.drawString(String("polls: ") + sPollCount, 10, 150, 2);
    tft.drawString(String("up:    ") + (millis() / 1000) + " s", 10, 175, 2);

    tft.setTextColor(TFT_DARKGREY, TFT_BLACK);
    tft.drawString("This text repainting = TFT still owns the bus.", 10, 285, 2);
}

void setup() {
    Serial.begin(115200);
    delay(3000);                       // let native USB enumerate before printing
    Serial.println();
    Serial.println("=== DIAG: PN5180 + TFT sharing one SPI host ===");
    Serial.printf("pins: NSS=%d BUSY=%d RST=%d | SPI SCK=%d MOSI=%d MISO=%d"
                  " | TFT CS=%d DC=%d RST=%d\n",
                  PN5180_NSS, PN5180_BUSY, PN5180_RESET,
                  SPI_SCK, SPI_MOSI, SPI_MISO,
                  TFT_CS, TFT_DC, TFT_RST);
    Serial.flush();

    // Same order as main.cpp: claim the bus explicitly, THEN let TFT_eSPI
    // init (its own spi.begin() will early-return), THEN the PN5180.
    Serial.println("SPI.begin()…");
    Serial.flush();
    SPI.begin(SPI_SCK, SPI_MISO, SPI_MOSI);
    Serial.printf("SPI.begin() ok — bus handle %s\n", SPI.bus() ? "valid" : "NULL (bad)");

    Serial.println("tft.init()…  <-- a panic here is the null bus-handle crash");
    Serial.flush();
    tft.init();
    tft.setRotation(TFT_ROTATION);
    drawScreen("display OK, NFC starting", TFT_YELLOW);
    Serial.println("tft.init() ok — screen should show 'display OK, NFC starting'");
    Serial.flush();

    // MISO must float now that the panel's SDO is off the splice. If this still
    // reads held-LOW, the SDO wire is still connected.
    pinMode(SPI_MISO, INPUT_PULLUP);   delay(5);
    const int misoUp = digitalRead(SPI_MISO);
    pinMode(SPI_MISO, INPUT_PULLDOWN); delay(5);
    const int misoDn = digitalRead(SPI_MISO);
    pinMode(SPI_MISO, INPUT);
    Serial.printf("MISO GPIO %d: pullup=%d pulldown=%d -> %s\n",
                  SPI_MISO, misoUp, misoDn,
                  (misoUp && !misoDn) ? "FLOATING (correct — SDO is off the splice)"
                                      : "STILL DRIVEN (is the TFT SDO wire still on MISO?)");
    Serial.flush();

    Serial.println("nfc.begin()…");
    Serial.flush();
    claimNfc();
    nfc.begin();

    Serial.println("nfc.reset()…  <-- if this is the last line, the reader is deaf");
    Serial.flush();
    claimNfc();
    nfc.reset();
    Serial.println("nfc.reset() ok");

    uint8_t prod[2] = {}, fw[2] = {}, eep[2] = {};
    claimNfc();
    nfc.readEEprom(PRODUCT_VERSION,  prod, 2);
    nfc.readEEprom(FIRMWARE_VERSION, fw,   2);
    nfc.readEEprom(EEPROM_VERSION,   eep,  2);
    Serial.printf("product %d.%d  firmware %d.%d  eeprom %d.%d\n",
                  prod[1], prod[0], fw[1], fw[0], eep[1], eep[0]);

    claimNfc();
    nfc.setupRF();
    Serial.println("setupRF() ok — polling. Present a tag; watch the SCREEN too.");
    Serial.flush();

    drawScreen("both up - polling", TFT_GREEN);
}
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

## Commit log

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2026-06-20 Add intel/tinycbor and OPT tag encode/decode layer
    - platformio.ini: replace CBOR placeholder comment with intel/tinycbor dep
    - src/opt_tag.h: OptMain and OptAuxiliary structs; decode/encode/isBlank API
    - src/opt_tag.cpp: tinycbor-backed stubs with TODO comments pointing to the
    prusa3d/OpenPrintTag Python reference for exact field names and wire layout
    Claude-Session: https://claude.ai/code/session_011UE5kAaD5MDBY9SijBNtev
    [opt_tag.cpp]
2026-06-20 Rewrite opt_tag with correct field names and integer CBOR keys
    Read prusa3d/OpenPrintTag data/*.yaml for ground truth:
    - Wire format uses integer keys, not strings (critical correction)
    - OptMain: instance_uuid (key 0) as 16-byte Spoolman lookup key; full field
    set from main_fields.yaml with correct int key constants
    - OptAuxiliary: consumed_weight only (key 0); remaining = actual_netto_full_weight
    - consumed_weight, not stored on tag
    - OptMeta: region offset/size fields (keys 0-3) from meta_fields.yaml
    - optDecode: parses Meta, Main, Aux with integer key dispatch; cborGetFloat()
    handles int/float16/float32/float64 from reference CompactFloat encoding
    - optEncodeMain / optEncodeAux: t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
    [opt_tag.cpp]
2026-06-20 Implement findNdefPayload — NDEF TLV and record parser
    Walks the ISO15693 block dump to find the NDEF message TLV (type 0x03),
    then iterates NDEF records looking for TNF=0x02 MIME type matching
    "application/vnd.openprinttag". Handles both 1-byte and 3-byte TLV
    length fields, Short Record (SR) and normal payload length, and the
    optional ID Length (IL) field per the NDEF spec.
    opt_tag decode path is now fully implemented end-to-end.
    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
    [opt_tag.cpp]
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2026-06-21 Implement optBuildBlankTag and FormattingAndRegistering state
    Adds the blank-tag initialisation path: optBuildBlankTag() builds a
    complete OPT-compliant NDEF byte array (CC → NDEF TLV → Meta CBOR →
    empty Main → block-aligned empty Aux → 0xFE) for any tag geometry,
    handling SR=1/SR=0 and 1-/3-byte TLV length automatically.
    nfcTask's FormattingAndRegistering state now calls optBuildBlankTag,
    writes every block to the physical tag, mirrors the result into
    sRawBuf/sPayloadOffset, and populates gTagMeta/gTagMain/gTagAux before
    transitioning to ValidTagFound for syncTask to create the stub Spool.
    Also fixes optIsBlank to not mis-classify a formatted tag's non-empty
    Meta indefinite map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
    [nfc_task.cpp, opt_tag.cpp]
2026-06-21 Implement Spoolman HTTP client in syncTask
    Full sync_task.cpp replacement covering:
    - WiFiManager captive-portal provisioning (120s timeout → IdleNoWiFi)
    - ValidTagFound: nil UUID → create stub Spool (needs_onboarding=true),
    real UUID → GET by extra[nfc_id] → WeighingAndSync or ForeignTagFound
    - ForeignTagFound → RegisteringForeignTag: find-or-create Vendor/Filament/Spool
    from tag Main data; generate UUID v4 if tag had none
    - WeighingAndSync: compute remaining/consumed from scale weight, write
    consumed_weight to tag (gWriteAuxPending), PATCH Spoolman remaining_weight
    - Present: ~1Hz poll compares Spoolman filament/spool fields against
    sSnapshot baseline; triggers gWriteMai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
    [sync_task.cpp]
2026-06-21 Implement scaleTask, displayTask, and shared display globals
    - scale_task.cpp: NAU7802 load cell with NVS-backed calibration persistence;
    serial ZERO/CAL commands for field calibration; auto-tare on first boot
    - display_task.cpp: Full OLED + NeoPixel rendering for all device states;
    accelerating amber blink for AwaitingFormatConfirm countdown; two Present
    variants (synced vs needs-onboarding)
    - main.cpp: Add gSpoolId and gSpoolNeedsOnboarding shared globals; bump
    scaleTask stack to 3072 bytes
    - config.h: Add SCALE_CAL_FACTOR default (1.0f, replaced after field cal)
    Claude-Session: https://claude.ai/code/session_011UE5kAaD5MDB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
    [config.h, display_task.cpp, main.cpp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]
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2026-06-21 Persist Spoolman URL in NVS, expose in WiFiManager captive portal
    The Spoolman base URL is no longer hardcoded at compile time. On boot
    sync_task loads the URL from NVS (key "spoolman_url" in namespace "weigh"),
    falling back to the config.h default if NVS is empty. A custom field in
    the WiFiManager captive portal lets the installer set both WiFi credentials
    and the Spoolman URL in one step; the value is saved to NVS on form submit
    (trailing slashes stripped). Subsequent reboots use the persisted value
    without re-entering the portal.
    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
    [sync_task.cpp]
2026-06-21 Add BOOT-button hold to reset WiFi credentials and reopen captive portal
    Hold GPIO 0 (the BOOT button already on the SparkFun Thing Plus ESP32-S3
    board) for 3 seconds at power-on to clear stored WiFi credentials via
    wm.resetSettings(), forcing the captive portal to reopen. This lets the
    device be re-provisioned with a new SSID or a corrected Spoolman URL
    without reflashing.
    [config.h, sync_task.cpp]
2026-06-21 Add web interface for remote WiFi/URL reconfiguration
    Starts an mDNS responder (weighstation.local) and a minimal WebServer
    after WiFi connects. http://weighstation.local/ shows current Spoolman
    URL; http://weighstation.local/reset clears stored WiFi credentials and
    reboots into the captive portal. Lets a cabinet-installed device be
    reconfigured from any browser on the same network without physical access
    to the BOOT button or USB port.
    [config.h, sync_task.cpp]
2026-06-21 Decouple Spoolman URL config from WiFi credential reset
    Add a POST /url handler to the web interface so the Spoolman URL can be
    updated from any browser without touching WiFi credentials. Extract URL
    persistence into saveSpoolmanUrl() shared by the web handler and the
    captive-portal save callback.
    /reset now only clears WiFi credentials; the Spoolman URL survives a
    WiFi re-provision. The URL field in the captive portal still works as a
    convenience for initial setup when the web UI isn't reachable yet.
    [sync_task.cpp]
2026-06-21 Show URL reset instructions on OLED when Spoolman is unreachable
    SpoolmanUnreachable state now shows "Fix URL at: / weighstation.local"
    below the existing status lines, using the spare lower half of the 64px
    display. Gives cabinet-installed users the address without needing to
    look up documentation.
    [display_task.cpp]
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2026-06-22 feat: add external WS2812 NeoPixel; fix buzzer pin GPIO 13→14
    The BOM always specified GPIO 13 for the external NeoPixel breakout
    (mounted in the enclosure's 5mm light-pipe hole) and GPIO 14 for the
    buzzer, but the code had drifted to buzzer=13 with no external pixel.
    - config.h: add EXT_NEOPIXEL_PIN 13; move BUZZER_PIN 13→14
    - display_task.cpp: add extPixel instance that mirrors the onboard
    NeoPixel colour on every frame
    - hardware/wiring.md: add external NeoPixel section (data/3.3V/GND);
    fix buzzer to GPIO 14; update summary table
    - hardware/wiring-checklist.md: add external NeoPixel steps (17-19);
    renumber buzzer to 20-21; renumber remaining items
    - hardware/block-diagram.svg: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
    [config.h, display_task.cpp]
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2026-06-23 display: replace SSD1306 OLED with 3.5" ILI9488 SPI TFT
    Switch the porch display from the 1.3" Qwiic SSD1306 OLED to a
    Hosyond/MSP3520-type 3.5" ILI9488 480x320 SPI TFT, which fills the
    existing porch face. Key changes:
    - display_task.cpp: rewritten for TFT_eSPI; render-once-per-state model
    with dynamic update only for the AwaitingFormatConfirm countdown;
    status colours shown as text/title colour on the TFT
    - main.cpp / nfc_task.cpp: add gSpiMutex — nfcTask (Core 1) and
    displayTask (Core 0) share the SPI bus; all PN5180 transactions now
    guarded by the mutex
    - include/User_Setup.h: new TFT_eSPI config (ILI9488, GPIO 15/16/17
    for CS/DC/RST, shared MOSI/SCK/MISO with PN5180 on GPIO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
    [config.h, display_task.cpp, main.cpp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]
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2026-06-23 firmware: add piezo buzzer feedback for state transitions
    Initialises GPIO 14 as a LEDC PWM output and plays distinct tones
    on each meaningful state change:
    - Boot ready (WiFiSetupMode→Idle): C5-E5-G5 ascending chime
    - No WiFi: G4-E4 descending warning
    - Tag read error: E4-C4 low error drop
    - Blank tag detected: A5 double-pip
    - Foreign tag found: E5-G5 attention pair
    - Present after weigh: E5-G5-A5 success chime
    - Present after registration: C5-E5-G5-A5 fanfare
    - Spoolman unreachable: G4-E4 warning drop
    Spool removal (Present→Idle) is intentionally silent. All tones
    use vTaskDelay so nfcTask and scaleTask remain responsive during
    playback.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
    [display_task.cpp]
2026-06-30 hardware: fix TFT adapter plate mounting hole geometry
    Replace the buggy 4-hole loop (all holes landed left of centre) with
    two explicit pairs:
    - Left pair at plate-local X = −50.24 mm (face-local −37.24) —
    matching the two outer existing OLED porch holes.
    - Right pair at plate-local X = +52 mm (face-local +65) — outside
    the TFT PCB pocket right edge (+49.2) and the TFT active area
    right edge (+36.72).
    The right holes don't exist yet; the plate doubles as a drilling
    template — align to left screws, awl-mark through the right bores,
    drill Ø3.4 mm. Widens plate from 112 mm to 118 mm to give the
    right holes 7 mm edge clearance.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
    [porch-tft-adapter.scad]
2026-06-30 hardware: make TFT adapter mounting holes fully symmetric
    All four M3 holes now sit at plus-minus 52 mm plate-local, 2.8 mm outside
    the PCB pocket edge on each side. The previous left pair at -50.24 mm had
    only 1 mm pocket clearance; moving to -52 mm matches the right pair exactly.
    Old OLED holes are not reused - plate is a drill template for all four holes.
    [porch-tft-adapter.scad]
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2026-07-11 docs: add printed-parts known-issues log (deferred fixes)
    Record two field-found issues to fix on the next print revision:
    1. Base load-cell fixed-end boss flexes under load, corrupting weight
    readings — stiffen cross-section / add gussets (enlarged by hand on the
    built unit; SCAD unchanged).
    2. Porch TFT adapter — enlarge window ~0.5 mm and deepen pocket ~10 mm to
    seat the pin header without cutting a slot.
    Cross-link from the BOM printed-parts section and add pointer comments in
    both SCAD headers. No geometry changed.
    [porch-tft-adapter.scad, weighstation.scad]
2026-07-11 docs: clarify deferred TFT adapter fix specifics
    Per-side 0.5 mm applied equally to the window opening and the surrounding
    shelf/pocket (win 85x55 -> 86x56, pocket grows same); the 10 mm applies
    to the whole object (plate_t 5->15), raising the walls to seat the pin
    header. Update both the issues log and the SCAD header note. Still
    deferred — no geometry changed.
    [porch-tft-adapter.scad]
2026-07-11 hardware: apply TFT adapter fixes — +0.5mm/side window+pocket, +10mm depth
    Enlarge the bezel window and surrounding pocket 0.5 mm per side (win
    85x55 -> 86x56, pocket_clr 0.4 -> 1.4). Raise the whole object 10 mm
    (plate_t 5 -> 15) and deepen the pocket to match (pocket_d 3.2 -> 13.2),
    keeping the 1.8 mm bezel lip while the taller walls house the board's
    soldered pin header — no slot cut. Design now keeps the header rather than
    desoldering. Note M3x20+ screws for the thicker plate. Mark issue #2 fixed.
    Not rendered (no OpenSCAD in env) — verify in a slicer before printing.
    [porch-tft-adapter.scad]
2026-07-11 hardware: remove wire notch, add parametric microSD access slot
    Drop the wire notch (wires now exit the open back into the porch cavity).
    Add a microSD access slot cut through the top wall so the card can be
    inserted/removed while mounted. Confirmed placement: card exits the top
    edge, socket on the PCB back (slot height ~10.5 mm above back face).
    Fully parametric (edge/offset/width/height/z); sd_slot_offset still needs
    setting once board mounting rotation is fixed (socket is off-centre).
    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
    [porch-tft-adapter.scad]
2026-07-11 hardware: set microSD slot offset to -18mm; open back, no cable relief
    Socket mouth measured 67mm (+-1) from the board's right edge on the 98mm
    board -> 18mm off-centre; set sd_slot_offset = -18 (flip sign if it lands
    on the wrong side). Record that the open back is intentional — no back
    cover or cable relief.
    [porch-tft-adapter.scad]
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2026-07-11 hardware: add clearance to microSD slot (16x5mm)
    Widen the slot to 16mm (~2.5mm/side around an 11mm card) to absorb offset
    and print tolerance, and raise it to 5mm so it clears the card at both
    front-reference readings (7.2 and 9.0mm), making the earlier reference-
    face ambiguity moot.
    [porch-tft-adapter.scad]
2026-07-11 hardware: reinforce load-cell boss; rework porch for TFT adapter
    Issue #1 (load-cell boss flex): enlarge the fixed-end boss (extend
    rearward -X, widen +-Y) and add a rear triangular buttress to the floor.
    All added material stays on the -X/+-Y sides so the +X edge is fixed and
    the deflecting bar's free travel is untouched. Parameterised
    (lc_boss_ext/wide/butt) to tune to the physical fix.
    Porch UI rework: remove the OLED window+holes, panel button, and LED
    cutouts; replace with a single TFT display opening (110x37, inset 15mm/
    side from the 140x67 adapter, centred on the face) plus 4x M3 adapter
    screw holes at +-60 (V) x +-23.5 (U), matching porch-tft-adapter.scad.
    Verified numerically (in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
    [weighstation.scad]
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2026-07-12 hardware: fix degenerate boss buttress; extend pillar forward (+X)
    The rear buttress was a hull() of eps-thin boxes -> a zero-thickness
    sheet (the 'polygon with no sides', Volumes: 2). Remove it and instead
    widen the fore-aft footprint on the free-end side: a solid +X buttress
    (lc_boss_fwd) reaching toward the free end but capped lc_beam_gap=5mm
    below the bar so the beam still flexes. Fore-aft base 18mm -> ~43mm.
    Verified: 5mm beam clearance, 16.5mm clear of the overload-stop post.
    [weighstation.scad]
2026-07-12 hardware: resolve TFT adapter vs platform interference
    The adapter's top edge fouled the overhanging weighing platform (~-2.7mm,
    i.e. collision). Fix as a combo: trim plate_y 67->63 (top edge drops) and
    raise plat_gap 2->5 (platform rises) -> ~3.1mm clearance. Decouple the
    adapter screw pattern (fixed +-60/+-23.5) from the plate outline so the
    trim doesn't move the holes off the porch pattern. Window and PCB pocket
    are unchanged, so the display still fits (2.63mm frame remains). Note the
    boss grew 46.3->49.3mm (plat_gap), tightening the overload-stop screw.
    Verified numerically (no OpenSCAD in env) — slice-check before printing.
    [porch-tft-adapter.scad, weighstation.scad]
2026-07-13 hardware: correct microSD slot after first print
    Photo of the printed adapter showed the slot on the wrong side (over the
    touch header, not the SD socket) and slightly tight. Flip sd_slot_offset
    -18 -> +18 (socket is on the +X side), widen 16 -> 22mm (+3/side), and
    extend the display-side edge 1.5mm (Z-span 4.7 -> 11.2) to reach the
    socket mouth at the PCB-back plane. Front edge stays 2mm below the glass,
    so the bezel lip is intact.
    [porch-tft-adapter.scad]
2026-07-13 hardware: add M2.5 front through-bolt holes to retain the display board
    Add 4 M2.5 clearance bores through the adapter's front panel at the
    board's 92x50mm hole pattern (+-46 x +-25). Cap sits proud on the front;
    the shaft passes through the panel and the board's corner hole into an
    M2.5 nut behind, cinching the board against the panel back. Bores land on
    the bezel shelf (clear of the window, pocket, porch screws, and SD slot).
    Add the M2.5 screws/nuts/washers to the fastener schedule and BOM.
    Verified placement numerically; not rendered (no OpenSCAD) — slice-check.
    [porch-tft-adapter.scad]
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2026-07-14 feat(store): Phase 1 core — LittleFS log, indices, NVS counter, serial harness
    Implement the store module (tasks 1.1-1.8):
    - Append-only NDJSON event log on LittleFS with per-line CRC-32; identity
    rides on onboard/reconcile, weights on weigh.
    - Durable append (adds a newline before a torn tail so recovery is clean).
    - In-memory spool + inventory indices; log-replay rebuild that skips
    torn/corrupt lines.
    - Atomic NVS spool-ID counter; read-only query API.
    - Serial test harness (EV/DUMP/REBUILD/LOGSTATS/TORN/WIPE), routed via
    scale_task; storeBegin() called at boot.
    CRC round-trip + torn-tail skip validated against a Python mirror; not yet
    compiled/flashed (1.9 = on-hardware milestone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
    [main.cpp, scale_task.cpp]
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2026-07-16 feat(config): Phase 3 — config catalog module
    config_store.{h,cpp}: vendors / materials / spool-profiles / colors /
    stock-items tables on LittleFS (/config/*.json), loaded at boot with
    seeded defaults, read/iterate/add API, whole-table replace+serialize for
    web CRUD, and a CFG serial harness. Wire cfgBegin() at boot and route CFG
    commands via scale_task. Foundation for onboarding (pick-not-type) and
    ordering (stock catalog).
    [config_store.cpp, main.cpp, scale_task.cpp]
2026-07-16 fix(display): buzzer LEDC calls build on arduino-esp32 2.x and 3.x
    CI resolves core 2.x, where ledcAttach(pin,freq,res) and ledcWriteTone(pin,
    ..) don't exist (that's the 3.x API) — the build was failing at
    display_task.cpp:114. Wrap the LEDC calls in version-guarded macros so both
    the 2.x (ledcSetup+ledcAttachPin, channel-based) and 3.x (pin-based) APIs
    compile.
    [display_task.cpp]
2026-07-16 fix(config): build seed tables via explicit builders (GCC 8 aggregate init)
    CI (esp32 GCC 8) rejected push_back({...}) for CfgColor/CfgMaterial/CfgProfile
    (char-array and nested-array aggregate members). Replace the braced-init
    seeds with addMat/addProf/addColor helpers that strlcpy + assign fields.
    [config_store.cpp]
2026-07-16 Phase 2: cut tag/weigh flow over to local store; delete Spoolman client
    Replaces the Spoolman HTTP client in sync_task with local-store operations:
    - Blank tag: mint UUIDv4 + local stub (needs_ob), stamp identity to tag.
    - Known tag: look up by UUID in store, push web-side identity edits to tag.
    - Foreign tag: decode its own Main, create a local record from it.
    - Weigh: append a Weigh event (gross/remaining/used) + write tag Aux.
    - Present: poll the local store (not Spoolman) and rewrite tag Main when a
    web-side edit changes identity — the same reconcile mechanism, local source.
    Drops HTTPClient/ArduinoJson/Preferences from sync_task, SPOOLMAN_BASE_URL and
    the Spoolman URL captive-porta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
    [config.h, display_task.cpp, sync_task.cpp]
2026-07-16 Phase 4: built-in inventory dashboard + onboarding web app
    Adds web_app.* (ESPAsyncWebServer) serving the device's own UI, replacing
    the Spoolman web interface:
    - GET / inventory roll-up by material + the spool on the scale
    - GET /spools full spool list with color swatches / onboarding flags
    - GET /api/spools JSON inventory
    - GET /onboard pick vendor/material/color/spool-profile for the current spool
    - POST /api/tare one load-cell reading to prefill empty-spool tare
    - POST /api/onboard write full OPT Main (identity + temps + weights) to the tag
    and append a reconcile event to the log
    - GET /reset clear WiFi creds + reboot to captive portal (was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
    [sync_task.cpp]
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2026-07-16 Phase 7: SoftAP fallback + idle-screen web address; retire Spoolman state
    - syncTask now brings up a real 'WeighStation' SoftAP when no lab WiFi is
    provisioned, so the web app is reachable with zero infrastructure. It
    publishes the reachable address (mDNS hostname in station mode, AP IP +
    SSID in fallback) via gWebAddr/gApSsid.
    - Idle screen shows 'http://weighstation.local'; the no-WiFi screen shows the
    'Join WiFi: WeighStation' SSID + AP URL so anyone can find the UI on-screen.
    - Removed the dead DeviceState::SpoolmanUnreachable and its display/buzzer
    cases; de-Spoolman'd remaining nfc_task/main comments.
    Capacity harness for 'test capacity all at once' already ships as the stor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
    [display_task.cpp, main.cpp, nfc_task.cpp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]
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2026-07-17 Show on-screen calibration hint until CAL is run
    First boot has no stored calibration, so the scale reads raw counts silently.
    Add gScaleCalibrated (set from NVS at boot, true after a successful CAL) and an
    idle-screen banner ('Scale not calibrated / Send CAL <g> over USB') that shows
    while uncalibrated. displayTask forces a clean redraw when the flag flips so the
    banner clears the moment CAL completes, even while sitting at idle.
    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
    [display_task.cpp, main.cpp, scale_task.cpp]
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2026-07-19 docs: rename OLED->TFT wording; rewrite display-states doc for the TFT
    The project switched from an SSD1306 OLED (Qwiic) to an ILI9488 TFT (SPI) but
    several docs still described the OLED. Replace docs/design/oled-display-states.md
    with tft-display-states.md, rewritten from display_task.cpp (480x320, TFT_eSPI,
    current per-state screens; no Spoolman/offline states). Fix the user manual
    (display is SPI, not a Qwiic SSD1306; blank-display troubleshooting), CLAUDE.md
    (display, and the doc reference), device-states.mermaid, and a stale
    weighstation.scad standoff comment. Kept the accurate 'OLED removed/replaced by
    TFT' history notes in the SCAD files.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
    [weighstation.scad]
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2026-07-22 display: show web-app URL on the Registered! screen; add tools/ previews
    The 'Registered!' (needs-onboarding) screen said 'Add details in web app' but
    never showed where — add the URL line (http://<gWebAddr>, cyan) like the idle
    screen. Update tft-display-states.md to match.
    Also commit the UI preview generators under tools/ (preview_webapp.py,
    preview_lcd.py) with a README noting they duplicate firmware layout with sample
    data, aren't built by CI, and will drift if the UI changes.
    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
    [display_task.cpp]
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2026-07-26 hardware: wire the display board's microSD (dedicated 2nd SPI bus)
    The Hosyond ILI9488's microSD is on a separate header, not bonded to the
    display SPI bus, so it gets its own SPI host (SD_SCK/MOSI/MISO/CS = GPIO
    10/18/33/34) isolated from the shared PN5180+TFT bus. Backup/archive only;
    the station still runs with no card, and the Thing Plus's own onboard SD
    slot is left empty.
    - config.h: add SD pin defines + build note
    - netlist.md: add SD wiring table, update totals, move SD out of 'not wired'
    - wiring-diagram.svg: add microSD node on its 2nd-SPI edge
    - display datasheet: record the assigned pins; note onboard slot left empty
    - BOM: mark SD wired, add microSD-card line, resolve the open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
    [config.h]
2026-07-26 feat(sd): implement SD-card backup snapshots + restore (Phase 6)
    Adds sd_backup.* — the display board's microSD on its dedicated 2nd SPI
    host (HSPI, GPIO 10/18/33/34), fully isolated from the PN5180+TFT bus.
    Snapshot discipline (never overwrites a good backup in place):
    stage -> CRC-verify (independent re-read) -> archive current good copy to
    dated history -> promote staging by rename -> write manifest + prune
    history to SD_HISTORY_KEEP + mirror config. Card-full reclaim evicts
    oldest history first; if it still won't fit the snapshot is skipped
    gracefully (primary data on flash untouched).
    Restore reuses the validated import path (per-line CRC, index rebuild,
    counter advance),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
    [config.h, main.cpp, sync_task.cpp]
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
